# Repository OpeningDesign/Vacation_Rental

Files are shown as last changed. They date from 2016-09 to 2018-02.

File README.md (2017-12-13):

## The Downtowner - A Vacation Rental in Lake Geneva, WI

---

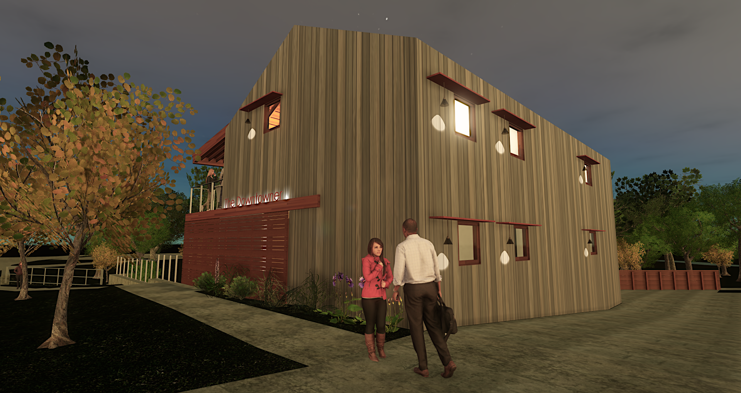
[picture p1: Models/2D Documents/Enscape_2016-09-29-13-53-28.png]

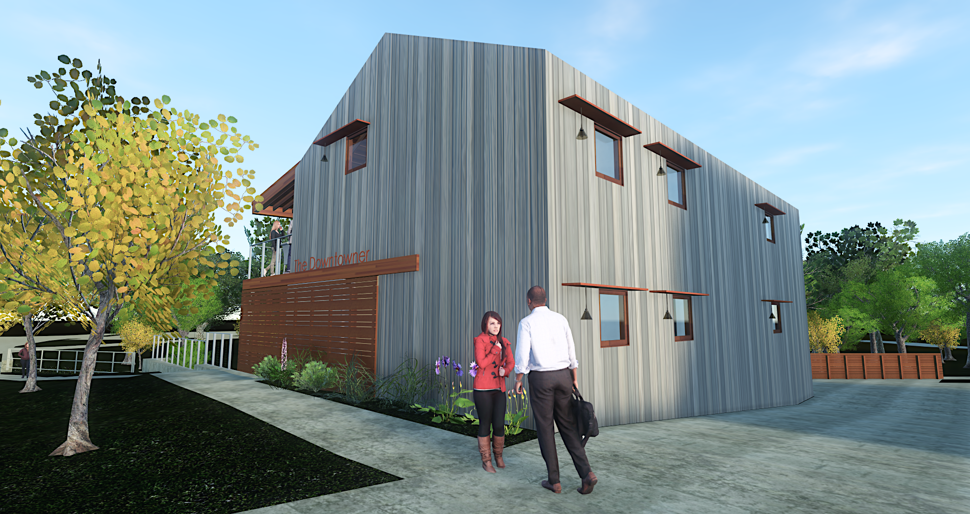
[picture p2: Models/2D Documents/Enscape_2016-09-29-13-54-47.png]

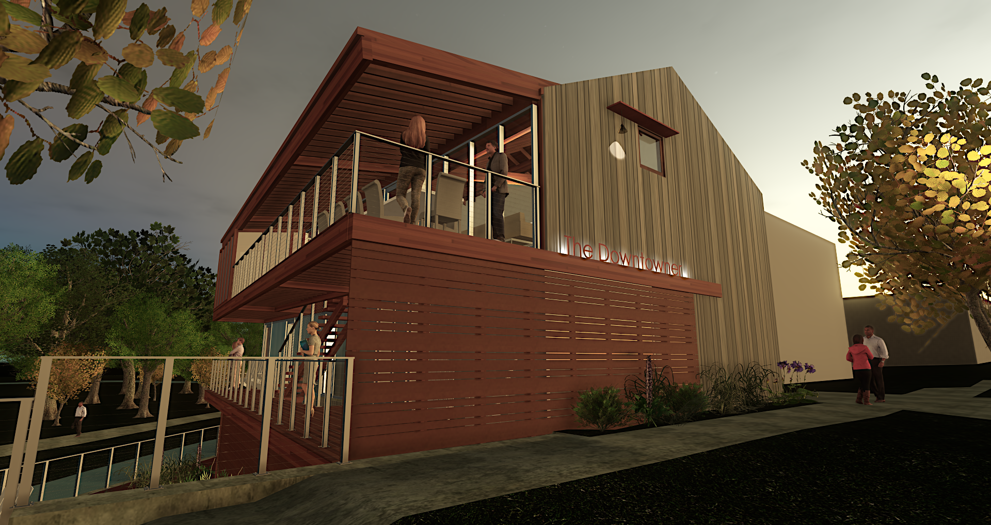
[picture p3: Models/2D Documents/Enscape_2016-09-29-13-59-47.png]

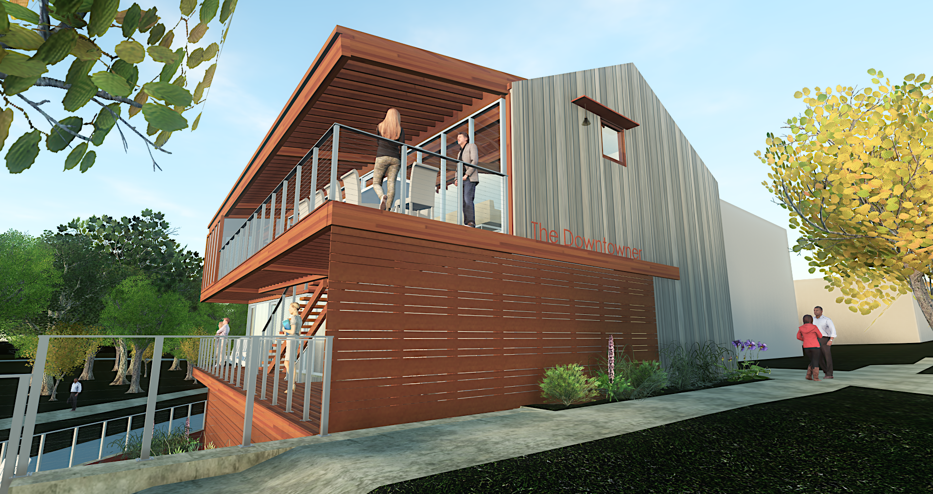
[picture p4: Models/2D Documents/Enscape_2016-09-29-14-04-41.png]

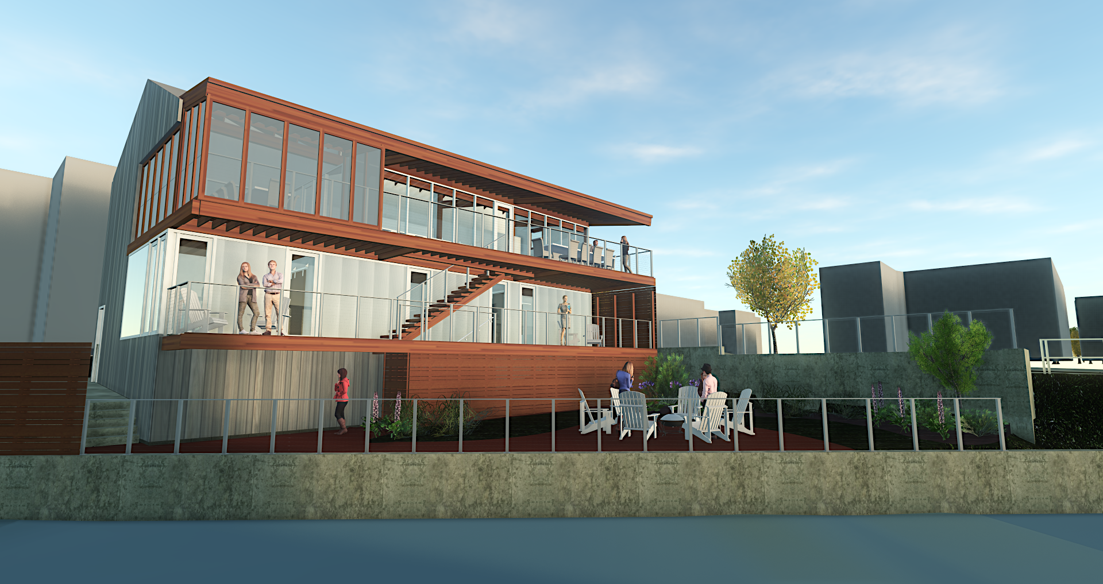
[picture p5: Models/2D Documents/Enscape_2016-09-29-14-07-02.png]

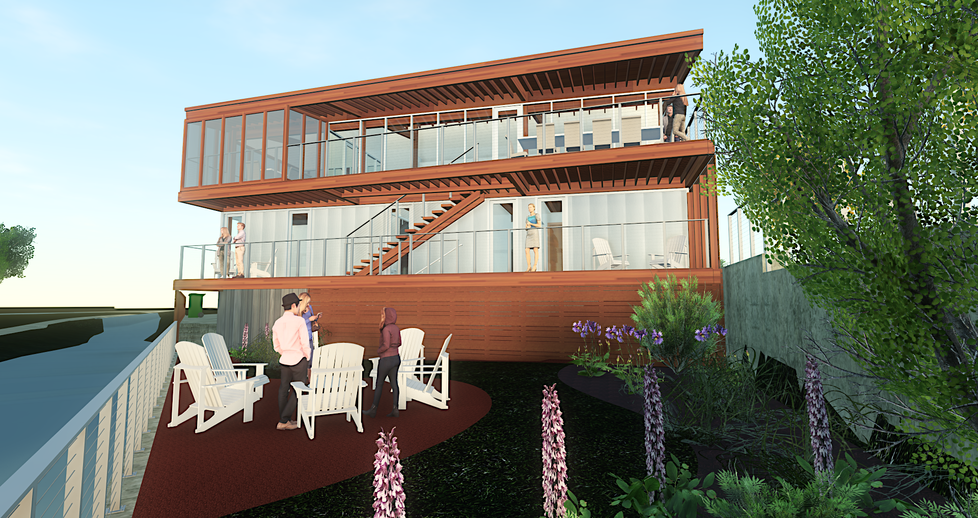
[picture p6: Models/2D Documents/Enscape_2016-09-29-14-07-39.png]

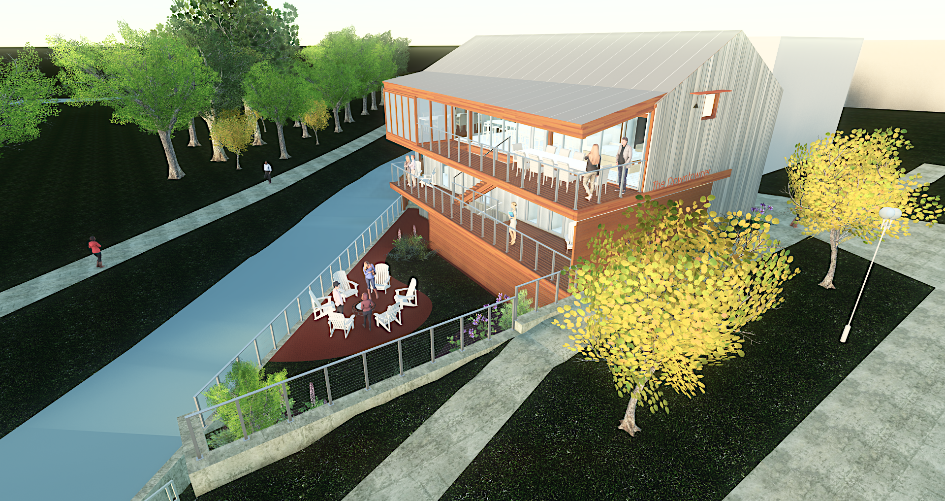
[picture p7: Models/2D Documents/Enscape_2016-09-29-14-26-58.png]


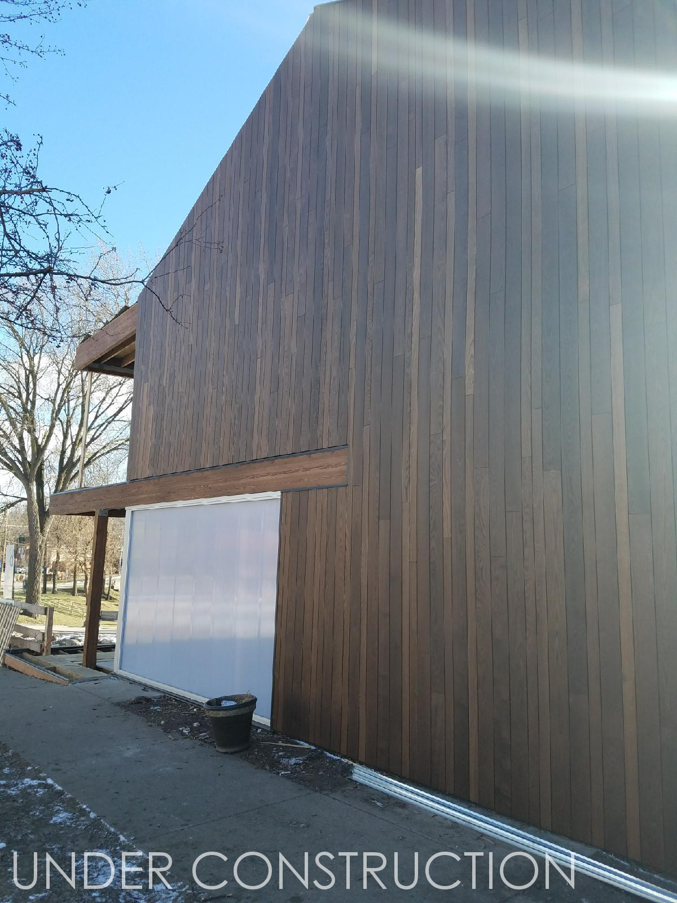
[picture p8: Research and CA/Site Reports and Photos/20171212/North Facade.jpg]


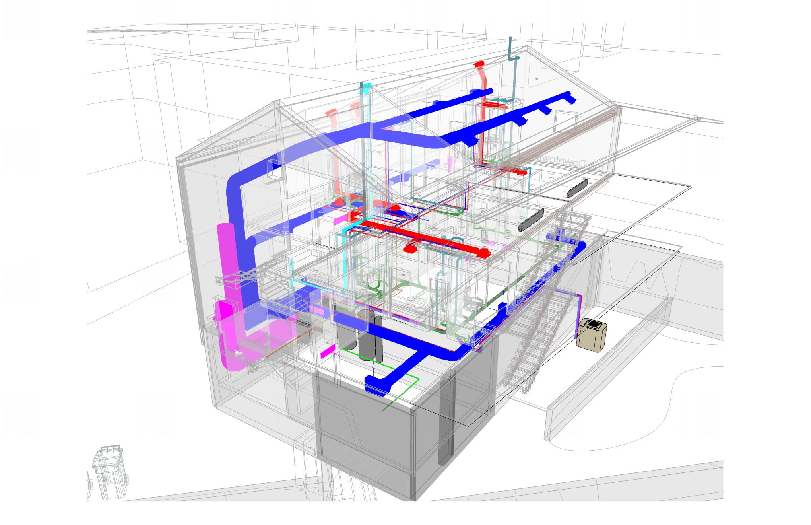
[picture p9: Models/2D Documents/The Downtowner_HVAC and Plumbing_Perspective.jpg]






---

#### In-the-Open

All of [OpeningDesign's](http://openingdesign.com/) projects are conducted out in the open.  That is, during the development of any one project, all team communication and content is hosted [publicly](https://github.com/OpeningDesign) (here on GitHub) and is <a href="#license">open source</a>.

Our [about page](http://openingdesign.com/about/) provides a more nuanced description of this open approach.

---

#### License
Per usual, unless otherwise noted, all content associated with [OpeningDesign](http://openingdesign.com) projects is licensed under an open source, 'copyleft' license: 
[Attribution-ShareAlike 4.0 International (CC BY-SA 4.0)](https://creativecommons.org/licenses/by-sa/4.0/).  Attribution to be given to the entire team associated with the project.


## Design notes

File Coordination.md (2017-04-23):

 - Screen Patio is not conditioned.
 - Eliminate the return ducts?  Can we just use the rooms/corridors to return air to main trunks?
 - Route bathroom exhausts up to roof
	 - combine exhaust stacks as much as possible. Desapex: Okay this can be done
		 - 3 exhaust penetrations on roof?
 - Okay to narrow plenum duct out of furnace to make room for stair? Desapex :Will reduce as much as possible
 - Move supply duct closer to east facing storefront to counteract cold drafts. Desapex:All floors ???
	 - Also Include radiant heat along east facing storefront on 2nd floor. Desapex : We shall discuss on this
		 - Might be valued engineered out, but include for permit set. Desapex : We shall discuss on this
 - Rerouted refrigerant lines to compressor . Desapex : This can be done the way required.
 - see ModelsARCHs HVAC Proposal.rvt file for other spatial/configuration proposals.Desapex : okay

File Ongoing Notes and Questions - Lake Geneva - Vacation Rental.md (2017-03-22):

 - Showers per room
 - 1/2 bath upstairs
 - 70" T.V.

- Outside basement entrance?

- submit HVAC?
- submit plumbing?

- Sliding door at unit entrance
- pocket door at restrooms
- stackable washer/dryer
- smaller closets
- ironing board

- screened in porch

- Fire Department
	- Lieutenant Dennis Detkowski 262-248-7228
	- Jim Bastic
- Zoning and Building Inspection
	- Ken Robers

Mike Kasseric
Dan Draper - City Attorney

- Balloon framed?
- foundation dimensions
	- floor dimensions
	-

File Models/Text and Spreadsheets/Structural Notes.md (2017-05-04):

### LAMINATED WOOD STRESS COMBINATIONS:
|SPECIES|DOUGLAS FIR UNLESS NOTED|
|-|-|
|LAMINATION THICKNESS|1 1/2" (2" NOM.) UNLESS NOTED|
|STRESS COMBINATION|SEE STRESS LISTING BELOW|
|TREATING|ALL MEMBERS EXPOSED TO THE EXTERIOR TO BE TREATED|
|ADHESIVE|RESORCINOL RESIN
|AITC APPEARANCE GRADE|ARCHITECTURAL SMOOTH TEXTURE |
|FINISH (EXPOSED SURFACES)|FACTORY STAIN - ONE COAT.<br>ARCHITECT TO SELECT COLOR|
|FINISH (UNEXPOSED SURFACES)|ONE COAT SEALER|
|PROTECTION (TRANSIT)|WRAP INDIVIDUAL MEMBERS w/WATER-RESISTANT PAPER OR OPAQUE POLYETHYLENE, TAPE SEAMS

- MATERIALS AND WORKMANSHIP SHALL BE IN CONFORMANCE WITH "AMERICAN NATIONAL STANDARD", ANSI/AITC A190.1-1992.
- MEMBERS SHALL BE MARKED WITH A QUALITY MARK INDICATING CONFORMANCE TO THE STANDARD LISTED IN NOTE 1.

### LAMINATED WOOD STRESS COMBINATIONS:
|-||
|-|-|
|BEAMS|24F-1.8E(SIMPLE SPAN, 3500' RADIUS)|
|COLUMNS|COMB 2|

### LAMINATED WOOD CONNECTION / HARDWARE NOTES:

 - ALL CONNECTIONS PLATES SHALL BE FABRICATED WITH ASTM A36 STEEL
 - WELDING SHALL BE PERFORMED IN ACCORDANCE WITH AWS STANDARDS 
 - ALL HOLES SHALL BE 13/16" - UNLESS NOTED OTHERWISE
 - ALL BOLTS SHALL BE 3/4" ASTM A307 UNLESS NOTED OTHERWISE 
 - ALL LAGS SHALL CONFORM TO ANSI/ASME STANDARDS 
 - ALL SHEAR PLATES SHALL CONFORM TO ANSI/AF&PA STANDARDS.
 - SHAPED STEEL CONNECTION PLATES MAY BE CUT FROM A SINGLE PLATE OR CONSTRUCTED OF MULTIPLE PLATES w/ BEVELED, FULL PENETRATION WELDS (GROUND SMOOTH) 
 - ALL FABRICATED STEEL, BOLTS, WASHERS, SHEAR PLATES, LAGS, AND NAILS SHALL BE HOT DIP GALVANIZED WHERE EXPOSED TO THE WEATHER OR EMBEDDED IN CONCRETE.

### LAMINATED WOOD STORAGE / ERECTION NOTES:
- JOB-SITE STORAGE SHALL BE PROVIDED IN A LEVEL AREA TO PREVENTWARPAGE.  MEMBERS SHALL BE SUPPORTED WITH BLOCKING SPACED TO PROVIDE UNIFORM AND ADEQUATE SUPPORT.
- MATERIAL SHALL BE BLOCKED WELL OFF THE GROUND AND SEPARATED WITH STRIPPING TO ALLOW AIR CIRCULATION AROUND ALL FOUR SIDES OF EACH MEMBER.
- INDIVIDUAL MEMBER WRAPPINGS SHALL BE SLIT OR PUNCTURED ON THE LOWER SIDE TO ALLOW DRAINAGE OF WATER.
- MATERIAL SHALL BE STORED BENEATH AN OPAQUE, MOISTURE-RESISTANT COVERING UNTIL ERECTED.
- PADDED OR NONMARRING SLINGS SHALL BE USED FOR ERECTION, AND CORNERS SHALL BE PROTECTED WITH WOOD BLOCKING.
- PROVIDE ADEQUATE TEMPORARY BRACING UNTIL THE ROOF STRUCTURE IS SHEATHED.
- MODERATE USE OF DRIFT PINS, MODERATE REAMING, AND SLIGHT CUTTING ARE ACCEPTABLE MEANS OF CORRECTION FOR PROPER ASSEMBLY AND FITTING.  CONTACT PIERCE ENGINEERS FOR METHOD OF CORRECTION IF ERROR OR MATERIAL DEFECTS DO NOT ALLOW PROPER ASSEMBLY.
- HEAT SHOULD NOT BE FULLY TURNED ON AS SOON AS THE STRUCTURE IS ENCLOSED.  EXCESSIVE CHECKING MAY OCCUR DUE TO RAPID LOWERING OF THE RELATIVE HUMIDITY IN THE BUILDING.  A GRADUAL SEASONING PERIOD AT MODERATE TEMPERATURE SHOULD BE PROVIDED.

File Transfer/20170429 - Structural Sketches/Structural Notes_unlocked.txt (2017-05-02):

PE
PE
AS NOTED
WIND RIVER FINANCIAL
65 BUTTONWOOD CT.
MADISON, WISCONSIN
BID PACKAGE #1
03/02/2015
1
1. DESIGN UPLIFT ON ROOF TRUSSES AS INDICATED IN THE DESIGN DATA.  PROVIDE A TIE DOWN CLIP
AT EACH TRUSS, AT EVERY POINT OF BEARING.
2. ROOF TRUSS TOP CHORDS SHALL BE PITCHED TO MATCH ROOF DRAINAGE PROFILE ON ARCH.
DWGS.
DEFLECTION LIMITS:
ROOF
LIVE LOAD                                  L/360
TOTAL LOAD                                L/240
1. ALL BRACING SHOWN OR DESCRIBED SHALL BE MINIMUM 2x4 WITH 2- 16d IN EVERY TRUSS IT
CROSSES.
2. ALL TRUSS TOP CHORDS SHALL BE CONTINUOUSLY BRACED BY THE ROOF OR FLOOR DECKING.
3. ALL TRUSS WEB MEMBERS SHALL BE BRACED @ 4'-0" O.C. UNLESS CALCULATIONS SHOW
OTHERWISE.  COORDINATE BRACING w/MECHANICAL DRAWINGS.
4. ALL ROOF TRUSS HORIZONTAL BRACING SHALL BE STIFFENED @ 20'-0" O.C. WITH EITHER:
a. DIAGONAL BRACING EXTENDED TO A SHEAR WALL PARALLEL TO THE ORIGINAL BRACING.
SEE BRACING DETAILS 5/S4.00 FIG. 1(a)-1(d).
b. 1
2" APA RATED SHEATHING EXTENDED TO ROOF DECK OR SHEAR WALL.
5. ALL TRUSS BOTTOM CHORDS SHALL BE BRACED @ 6'-0" O.C. UNLESS CALCULATIONS SHOW
OTHERWISE.
ROOF TRUSS BRACING NOTES
ROOF TRUSS DESIGN NOTES
NOTE: TRUSS MANUFACTURER MAY NOT DEVIATE FROM THE FRAMING PLANS UNLESS PRIOR
APPROVAL FROM THE STRUCTURAL ENGINEER HAS BEEN GIVEN.  IT IS THE TRUSS MANUFACTURER'S
RESPONSIBILITY TO SEEK SUCH APPROVAL PRIOR TO MANUFACTURE AND INSTALLATION OF FRAMING
MEMBERS.
WOOD TRUSS SHOP DRAWINGS SHALL SHOW THE FOLLOWING INFO:
1. INFORMATION WHICH THE RESPONSIBLE BUILDING DESIGN PROFESSIONAL WILL CHECK FOR
COMPLIANCE WITH CONTRACT DOCUMENTS.
a. ERECTION PLAN: SHOWING DIMENSIONED LOCATIONS AND TRUSS IDENTIFICATION.
b. BEARING DETAILS: SHOWING BEARING LENGTH, WIDTH, AND DEPTH INDICATING
CONFORMANCE TO DESIGN CALCULATIONS.
c. DESIGN LOADS: ALL DEAD AND LIVE LOADS SHALL BE SHOWN ON THE FRAMING PLAN OR
TRUSS ELEVATION INDICATING CONFORMANCE TO TRUSS CALCULATIONS.
d. ALL PERMANENT BRACING: SHOW TOP CHORD, BOTTOM CHORD, & WEB MEMBER BRACING
ON FRAMING PLAN AND TRUSS ELEVATION. SUPPLIER AND INSTALLER OF THIS BRACING
SHALL ALSO BE INDICATED.
e. TRUSS DIMENSIONS: SHOW DEPTH, SPAN BEARING, HEIGHT, AND SLOPES AT ALL CRITICAL
POINTS.
f. TRUSS DEFLECTIONS:  SHOW LIVE LOAD AND TOTAL LOAD DEFLECTION BASED UPON
DESIGN LOADS
2. INFORMATION THAT SHALL BE THE RESPONSIBILITY OF THE FABRICATOR AND TRUSS DESIGNER
AND SHALL BE PROVIDED WITH THE SHOP DRAWING SUBMITTAL.
a. MEMBER DESIGN: INCLUDING WEB CONFIGURATION, MEMBER SIZE, GRADE OF LUMBER,
FABRICATED SPLICES, AND MEMBER BRACING REQUIRED BY TRUSS DESIGN.
b. MEMBER CONNECTIONS: DESIGN AND INDICATE ALL NECESSARY HARDWARE FOR
PROPER INSTALLATION OF TRUSSES INCLUDING, BUT NOT LIMITED TO, GIRDER PLY
CONNECTIONS, TRUSS-TO-GIRDER CONNECTIONS, TIE-DOWNS, AND FIELD SPLICES.
c. INTERIOR CONNECTIONS: DESIGN AND SHOW DETAIL OF WEB AND CHORD CONNECTIONS,
INCLUDING CONNECTOR PLATE SIZES, CAPACITIES, AND BOLT SIZES.
d. ERECTION PLAN: SHOW SPACING AND LAYOUT OF ANY TEMPORARY BRACING REQUIRED
FOR ERECTION.
e. STRUCTURAL DESIGN OF TRUSSES: SUBMIT COMPLETE TRUSS CALCULATIONS STAMPED
AND SIGNED BY A PROFESSIONAL ENGINEER IN THE STATE OF WISCONSIN AND OBTAIN
ALL APPROVALS NECESSARY FOR CONFORMANCE TO BUILDING CODE. VERIFY SUBMITTAL
AND APPROVAL BY SENDING A COPY TO THE BUILDING DESIGN PROFESSIONAL.
f. PROVIDE CONTRACTOR/INSTALLER WITH ALL DATA NECESSARY FOR PROPER
INSTALLATION.
ROOF TRUSS SUBMITTAL NOTES
1. FABRICATION AND ERECTION OF STRUCTURAL STEEL SHALL CONFORM WITH THE AISC  (AMERICAN
INSTITUTE OF STEEL CONSTRUCTION), "MANUAL OF STEEL CONSTRUCTION",  LATEST EDITION.
2. ALL STEEL DETAILS AND CONNECTIONS SHALL BE IN ACCORDANCE WITH THE  REQUIREMENTS OF
THE AISC "SPECIFICATIONS FOR STRUCTURAL STEEL BUILDINGS,  ALLOWABLE STRESS DESIGN AND
PLASTIC DESIGN", LATEST EDITION.
3. FABRICATORS SHALL DESIGN CONNECTIONS NOT SPECIFICALLY DETAILED ON PLANS AS FOLLOWS:
A. GENERAL: MEMBERS REQUIRING END MOMENT CONNECTIONS SHALL MEET THE 
REQUIREMENTS OF TYPE 1 "RIGID FRAME" CONSTRUCTION INCLUDING FRICTION 
BOLTS IF UTILIZED. ALL OTHER MEMBERS SHALL FOLLOW THE REQUIREMENTS OF 
TYPE 2 "SIMPLE" CONSTRUCTION.
B. MEMBER SHEAR CONNECTIONS: UNLESS A LARGER END VERTICAL REACTION IS SHOWN 
OTHERWISE ON THE DRAWINGS (IE R = 85k), MINIMUM DESIGN SHEAR FORCES SHALL BE 
AS FOLLOWS:
I. NON-COMPOSITE BEAMS: SUPPORT A REACTION "R" EQUAL TO ONE HALF THE TOTAL 
UNIFORM LOAD CAPACITY FROM THE TABLE OF UNIFORM LOAD CONSTANTS IN THE 
AISC MANUAL PART 2 FOR GIVEN SHAPE, SPAN, AND GRADE OF STEEL.
4. USE A325N BOLTS UNLESS NOTED OTHERWISE.
5. SPLICES SHALL BE ALLOWED ONLY AT LOCATIONS SPECIFICALLY INDICATED ON THE  STRUCTURAL
DRAWINGS UNLESS APPROVED OTHERWISE BY THE ENGINEER.
6. OVERSIZED OR SLOTTED HOLES SHALL NOT BE USED FOR ANY CONNECTIONS UNLESS
SPECIFICALLY INDICATED ON THE DRAWINGS OR APPROVED BY THE ENGINEER.
7. BEAM AND GIRDER CONNECTIONS SHALL BE AS NOTED ON PLANS AND IN DETAILS.
8. PROVIDE HOLES IN ALL STEEL AS REQUIRED TO PREVENT ANY ACCUMULATION OF WATER DURING
ERECTION.  ALL PENETRATIONS THROUGH MAIN MEMBERS SHALL NOT EXCEED 11
2" IN DIAMETER AND
SHALL BE GROUND SMOOTH.
9. CUTS, HOLES, COPING, ETC. REQUIRED FOR WORK OF OTHER TRADES SHALL BE SHOWN ON THE
SHOP DRAWINGS AND MADE IN THE SHOP.  CUTS OR BURNING OF HOLES IN STRUCTURAL STEEL
MEMBERS IN THE FIELD WILL NOT BE PERMITTED.
10. PROVIDE ANY NECESSARY TEMPORARY BRACING OR GUYS TO PROVIDE LATERAL SUPPORT OF THE
BUILDING UNTIL PERMANENT FRAME IS COMPLETELY INSTALLED.
11. STRUCTURAL STEEL FRAMING SHALL BE TRUE AND PLUMB BEFORE CONNECTIONS ARE FINALLY
BOLTED OR WELDED.
12. THE DETAILS OF DESIGN, WORKMANSHIP, AND TECHNIQUE FOR WELDING, INSPECTION OF WELDING,
AND QUALIFICATIONS OF WELDING OPERATORS SHALL CONFORM TO THE REQUIREMENTS OF THE
SPECIFICATIONS LISTED IN IBC SECTIONS 2205, 2206, 2207, 2209, AND 2210.
STRUCTURAL STEEL NOTES
FOOTINGS - BOTTOM & SIDES 3"
FOOTING - TOP 2"
PERIMETER WALLS - #5 & SMALLER 11
2"
PERIMETER WALLS - #6 & LARGER 2"
INTERIOR WALLS 3
4"
BEAMS, PIERS, & COLUMNS 11
2"
SLABS - BOTTOM & SIDES 1"
SLABS - TOP 3
4"
MILD STEEL PROTECTION
1. DESIGN AND CONSTRUCTION SHALL BE IN ACCORDANCE WITH THE LATEST PROVISIONS OF ACI
318/318R.
2. CONTRACTOR SHALL NOTIFY THE ARCHITECT/ENGINEER AT LEAST 48 HOURS PRIOR  TO PLACING
CONCRETE TO FACILITATE ON SITE OBSERVATION OF REBAR.
3. ARRANGEMENT AND BENDING OF REINFORCING STEEL SHALL BE IN ACCORDANCE WITH ACI
DETAILING MANUAL (ACI SP-66), LATEST EDITION.
4. WHEN THE AVERAGE TEMPERATURE FROM MIDNIGHT TO MIDNIGHT IS EXPECTED TO DROP BELOW
40 DEGREES FAHRENHEIT FOR THREE SUCCESSIVE DAYS, COLD WEATHER CONCRETING
REQUIREMENTS MUST BE FOLLOWED.
5. WHEN AMBIENT AIR OR CONCRETE TEMPERATURES EXCEED 90 DEGREES FAHRENHEIT, STEEL
REINFORCING AND/OR FORMING SURFACES ARE ABOVE 120 DEGREES, OR WHEN WIND VELOCITY,
HUMIDITY, OR SOLAR RADIATION CREATE CONDITIONS OF ACCELERATED MOISTURE LOSS AND
INCREASED RATE OF HYDRATION, HOT WEATHER CONCRETING REQUIREMENTS SHALL BE
FOLLOWED.
6. ALL HOOKS IN STEEL REINFORCING SHALL BE ACI STANDARD HOOKS, UNLESS NOTED OTHERWISE
IN CONSTRUCTION DOCUMENTS.
7. ALL CONCRETE SURFACES SHALL BE FORMED, UNLESS OTHERWISE NOTED.
8. CONTROL JOINTS SHALL BE PLACED IN SLAB ON GRADE AND SLAB ON METAL DECK CONSTRUCTION
WITHIN 24 HOURS OF INITIAL POUR.
9. WIRE SPACERS, CHAIRS, TIES, ETC., FOR SUPPORT OF STEEL REINFORCING SHALL BE PROVIDED
BY THE CONTRACTOR TO ENSURE REINFORCING IS PLACED IN THE PROPER POSITION DURING
CONCRETE PLACEMENT.
10. STEEL REINFORCING SPLICES OF ADJACENT BARS SHALL BE STAGGERED SUCH THAT SPLICES ARE
4 FEET APART, MINIMUM.
11. PROVIDE (2) #5 BARS AROUND ALL OPENINGS AND (2) #5 DIAGONALLY AT ALL OPENING CORNERS
UNLESS OTHERWISE SPECIFIED.  EXTEND 2'-6" PAST OPENING TYPICALLY.
12. WELDED WIRE REINFORCING SHALL BE IN FLAT SHEETS ONLY, AND LAPPED A MINIMUM OF 6
INCHES.
13. WELDING OF STEEL REINFORCING IS NOT PERMITTED.
14. SLEEVES, CONDUITS, OR PIPES THROUGH SLABS AND WALLS SHALL BE PLACED AT THREE
DIAMETERS ON CENTER, OR 4 INCHES MINIMUM.
15. ALUMINUM CONDUIT OR PIPING SHALL NOT BE CAST IN CONCRETE.
16. PROVIDE A 3
4" CHAMFER ON EXPOSED CORNERS OF CONCRETE UNO. TOP EDGES OF WALLS SHALL
BE TOOLED UNO.
17. FINISH & COVER CONCRETE SLABS w/ FILM FORMING CURING COMPOUND OR VAPOR RETARDER
UNO OR SPECIFIED OTHERWISE.
CAST-IN-PLACE CONCRETE NOTES
1. CONCRETE COVER MEASURED PERPENDICULAR FROM THE SURFACE IN DIRECTION OF TOLERANCES:
MEMBERS 12" OR LESS ±3
8"
MEMBERS OVER 12" ±1
2"
2. STEEL REINFORCEMENT SPACING SHALL BE WITHIN THE FOLLOWING TOLERANCES:
1
4" SPACING DISTANCE, NOT TO EXCEED 1"
3. PLACEMENT OF EMBEDDED ITEMS SHALL BE WITHIN THE FOLLOWING TOLERANCES:
VERTICAL ALIGNMENT ±1"
LATERAL ALIGNMENT ±1"
LEVEL ALIGNMENT ±1"
4. PLACEMENT OF FOOTINGS SHALL BE WITHIN THE FOLLOWING TOLERANCES:
LATERAL ALIGNMENT ±2"
LEVEL ALIGNMENT +1
2" TO -2"
(LEVEL ALIGNMENT SUPPORTING MASONRY) ±1
2"
5. CROSS-SECTIONAL DIMENSION OF FOOTINGS SHALL BE WITHIN THE FOLLOWING TOLERANCES:
FORMED FOOTINGS +2" TO -1
2"
EARTHCAST FOOTINGS:
2' OR LESS +3" TO -1
2"
GREATER THAN 2' BUT LESS THAN 6' +6" TO -1
2"
GREATER THAN 6' +12" TO -1
2"
FOOTING THICKNESS ±5%
6. TOP OF FOOTING SLOPE 1" IN 10'
7. SEE DRILLED PIER NOTES FOR ADDITIONAL INFORMATION AT DRILLED PIER FOUNDATIONS.
CAST-IN-PLACE CONCRETE TOLERANCES
1. CONCRETE MIXES TO BE PLACED DURING DRY AND WINDY CONDITIONS SHALL BE MODIFIED BY
THE ADDITION OF RETARDING ADMIXTURES OR SLOWER CURING CEMENT SUBSTITUTES TO
MINIMIZE THE EFFECTS OF ACCELERATED CURING.
2. WATER SHALL NOT BE ADDED TO CONCRETE MIXES ON SITE FOR WORKABILITY. MID OR HIGH
RANGE WATER REDUCERS SHALL BE APPROVED BY ENGINEER BEFORE ADDING TO CONCRETE
MIX FOR INCREASED WORKABILITY.
3. INGREDIENTS USED IN CONCRETE MIXES SHALL BE COOLED TO MAINTAIN A CONCRETE
TEMPERATURE BELOW 90 DEGREES FAHRENHEIT AT TIME OF PLACEMENT.
4. CHILLED WATER AND CHOPPED ICE MAY BE USED IN CONCRETE MIXTURES TO CONTROL
CONCRETE TEMPERATURES. AMOUNT OF CHOPPED ICE SHALL NOT EXCEED THE EQUIVALENT
AMOUNT OF MIXING WATER REQUIRED FOR THE DESIGN MIX.
5. RETARDING ADMIXTURES SHALL NOT BE USED IN CONCRETE MIXES WITHOUT THE APPROVAL OF
THE ENGINEER.
HOT WEATHER CONCRETING NOTES
1. SNOW, FROST, AND ICE SHALL BE REMOVED FROM ALL SURFACES, INCLUDING REINFORCING,
AGAINST WHICH THE CONCRETE IS TO BE PLACED
2. DO NOT PLACE CONCRETE ON FROZEN SUBGRADE.
3. THE MINIMUM PLACEMENT AND PROTECTION TEMPERATURE OF CONCRETE SHALL BE AS
FOLLOWS: MINIMUM TEMP OF CONCRETE 
AS PLACED AND MAINTAINED
DURING PROTECTION PERIOD
LEAST DIMENSION OF SECTION (DEGREES FAHRENHEIT)
LESS THAN 12" 55
12" TO LESS THAN 36 50
36" TO 72" 45
GREATER THAN 72" 40
4. TEMPERATURES OF CONCRETE SHALL BE MEASURED AT THE CONCRETE SURFACE.
5. CONCRETE TEMPERATURES SHALL BE MEASURED AND RECORDED FOR THE FIRST 3 DAYS UPON
PLACEMENT OF CONCRETE, AT THE BEGINNING, MIDDLE, AND END OF EACH WORK DAY AT 4 HOUR
INTERVALS. OVERNIGHT TEMPERATURE MEASUREMENTS ARE NOT REQUIRED.
6. HEATED AIR TEMPERATURES SHALL NOT EXCEED THE REQUIRED CONCRETE TEMPERATURES
LISTED IN TABLE ABOVE BY MORE THAN 20 DEGREES.
7. CONCRETE SHALL BE CURED AND PROTECTED AGAINST DAMAGE FROM FREEZING FOR A MINIMUM
PERIOD OF 3 DAYS.
8. DURING PERIODS NOT DEFINED AS COLD WEATHER, BUT WHEN FREEZING TEMPERATURES MAY
OCCUR, PROTECT CONCRETE SURFACES FROM FREEZING FOR THE FIRST 24 HOURS AFTER
PLACEMENT.
9. IF TEMPERATURE REQUIREMENTS DURING PROTECTION PERIOD ARE NOT MET, BUT CONCRETE
WAS PREVENTED FROM FREEZING, CONTACT ARCHITECT/ENGINEER FOR EXTENT OF ADDITIONAL
PROTECTION TIME REQUIRED.
COLD WEATHER CONCRETING NOTES
22
f'c = 4000
BAR
SIZE f'c = 3000
#3
CLASS 'B' TENSION LAP SPLICE LENGTHS (INCHES)
BOT
CLASS BOT TOP TOP
29
#4
#5
#6
#7
#8
#9
#10
#11
28 19 24
33
25
37
36
43
63
72
81
91
101
47
56
81
93
105
118
131
31
37
54
62
70
79
87
41
49
71
81
91
102
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
NOTES (db = BAR DIAMETER, C-C = CENTER TO CENTER):
1. SCHEDULE BASED ON CLEAR COVER >1 db AND C-C > 2db
2. TOP BARS OF BEAMS AND JOIST AND HORIZONTAL WALL REINFORCING
THIS SCHEDULE IS PROVIDED FOR THE CONVENIENCE OF THE CONTRACTOR AND IS NOT
INTENDED TO COVER ALL SITUATIONS. SHOP DRAWINGS SHALL CLEARLY INDICATE ALL REQUIRED
LAP LENGTHS
1. ANCHOR BOLTS SHALL BE SET TO THE FOLLOWING TOLERANCES:
ELEVATION OF TOP OF BOLTS +1" TO -3
8"
OUT OF POSITION OF ANCHOR BOLTS ± 1
8"
2. PROTECT IN-PLACE FOUNDATIONS AND SLABS ON GRADE FROM FROST PENETRATION UNTIL
PROJECT COMPLETION
3. WHERE FILL MATERIAL IS REQUIRED ON BOTH SIDES OF GRADE BEAMS OR WALLS, IT SHALL BE
PLACED SIMULTANEOUSLY. REFER TO PLANS AND SPECIFICATIONS FOR TYPE AND PLACING OF
BACKFILL.
4. WHERE FILL MATERIAL IS PLACED ON ONE SIDE OF A WALL (OR GRADE BEAM), THE WALL (OR
BEAM) SHALL BE ADEQUATELY SHORED AND BRACED OR THE MATERIAL SHALL NOT BE PLACED
UNTIL SUPPORTING FLOOR SLABS HAVE BEEN POURED AND SET.
5. REFER TO ARCHITECTURAL DRAWINGS OR PLUMBING DRAWINGS FOR SPECIFIC FLOOR DRAIN
LOCATIONS & ELEVATIONS.
6. NO PROVISION HAS BEEN MADE FOR FUTURE EXPANSION.
7. VERIFY SIZES OF ALL STOOPS WITH ARCHITECT PRIOR TO CONSTRUCTION.
GENERAL FOUNDATION NOTES
1. FRAMING MEMBERS:
VERTICAL MEMBERS: SEE PLANS FOR SIZE, SPACING AND
GRADE.   KILN DRIED, MOISTURE 
CONTENT SHALL BE BETWEEN 15%
AND 19%
2. TOP & BOTTOM PLATES OF STUD WALLS SHALL BE THE SAME AS THE WALL STUDS.  (BOTTOM
PLATE TO BE TREATED).
3. ROOF SHEATHING SHALL BE 3
4" AT FLAT ROOFS ATTACHED TO THE ROOF FRAMING MEMBERS w/
8d COMMON OR BOX NAILS @ 6" O.C. ALONG EDGES AND 12" O.C. ALONG INTERMEDIATE
MEMBERS. STAGGER PANEL EDGES.  (1" MIN. EMBED. INTO FRAMING MEMBER).  INSTALL EDGE
CLIPS ON PANEL EDGES BETWEEN FRAMING MEMBERS.
4. EXTERIOR WALLS TO BE SHEATHED w/APA RATED SHEATHING, SEE ARCH DRAWINGS FOR
THICKNESS.   ATTACH DIRECTLY TO THE OUTSIDE FACE OF EXTERIOR STUD WALLS WITH 8d
COMMON OR BOX NAILS @ 6"O.C. ALONG EDGES AND 12" O.C. ALONG INTERMEDIATE MEMBERS.
U.N.O.
5. AS A MINIMUM, ALL CONNECTIONS SHALL CONFORM TO IBC 2006 TABLE 2304.9.1 FASTENING
SCHEDULE. DRAWING DETAILS SHALL GOVERN IF THEIR CONNECTION CAPACITY IS GREATER
THAN THOSE SPECIFIED IN TABLE 2304.9.1.
6. WHERE BUILT-UP/MULTI-PLY BEAMS AND HEADERS OF DIMENSIONAL LUMBER OR LVL MATERIAL
ARE INDICATED, SEE DETAIL 1/S4.00 FOR TOP LOADED MEMBERS FOR MINIMUM FASTENING
REQUIREMENTS.  ALSO SEE MANUFACTURER'S MINIMUM FASTENING REQUIREMENTS.
7. WHERE BUILT-UP/MULTI-PLY POSTS AND JAMBS ARE INDICATED, FASTENING SHALL BE IN
ACCORDANCE WITH NATIONAL DESIGN SPECIFICATION SECTION 15.3.3.
8. USE JOIST HANGERS DESIGNED FOR GIVEN MEMBER SIZE TO SUPPORT ALL JOISTS/HEADERS
FRAMING INTO SIDES OF OTHER MEMBERS.
9. COORDINATE WALL & FACE BRICK DIMENSIONS W/ ARCHITECTURAL DRAWINGS.
WOOD FRAMING NOTES
(APPLY TO ALL FRAMING DRAWINGS)
DESIGN CODE:
2011 WISCONSIN COMMERCIAL BUILDING CODE
WIND LOAD INFORMATION:
BASIC WIND SPEED 90 MPH
 BUILDING OCCUPANCY CATEGORY II
WIND LOAD IMPORTANCE FACTOR (Iw) 1.00
WIND EXPOSURE B
INTERNAL PRESSURE COEFFICIENTS ± .18
COMPONENTS AND CLADDING (GROSS WIND PRESSURES):
(FOR ZONE DEFINITIONS & DIAGRAMS SEE DESIGN GUIDE ASCE/SEI 7 SECTION 6)
WIDTH OF PRESSURE COEFFICIENT ZONE (a) 6 ft
TRIBUTARY WIND LOAD AREAS: 10 ftà 50 ftà 100 ftà
ROOF (GABLE/HIP/MONOSLOPE):
NEGATIVE ZONE 1 -14.6 psf -13.7 psf -13.3 psf
NEGATIVE ZONE 2 -24.4 psf -18.4 psf -15.8 psf
NEGATIVE ZONE 3 -24.4 psf -18.4 psf -15.8 psf
POSITIVE PRESSURE ALL ZONES 10.0 psf 10.0 psf 10.0 psf
WALLS:
ZONE 4 -14.4 psf -13.1 psf -12.5 psf
ZONE 5 -17.8 psf -15.0 psf -13.9 psf
OVERHANGS/CANOPIES:
ZONE 1,2 -21.0 psf -20.1 psf -19.8 psf
ZONE 3 -21.0 psf -20.1 psf -19.8 psf
SEISMIC LOAD INFORMATION:
SEISMIC USE GROUP / OCCUPANCY CATEGORY II
SEISMIC LOAD IMPORTANCE FACTOR (Ie) 1.00
SEISMIC SITE CLASS D
MAPPED SPECTRAL RESPONSE ACCELERATION (Ss) 10.40                                   
MAPPED SPECTRAL RESPONSE ACCELERATION (S1) 4.40
SPECTRAL RESPONSE COEFFICIENT (Sds) 0.111
SPECTRAL RESPONSE COEFFICIENT (Sd1) 0.070
SEISMIC DESIGN CATEGORY A
BASIC SEISMIC FORCE RESISTING SYSTEM LIGHT FRAME SHEAR WALLS
RESPONSE MODIFICATION FACTOR 2.5
SEISMIC RESPONSE COEFFICIENT (Cs) 0.044
ANALYSIS PROCEDURE EQUIVALENT LATERAL FORCE
SNOW LOAD INFORMATION:
GROUND SNOW LOAD (Pg) 30 psf 
SNOW EXPOSURE FACTOR (Ce) 1.00
SNOW LOAD IMPORTANCE FACTOR (Is) 1.00
THERMAL FACTOR (Ct) 1.10
1.20 AT OVERHANGS
DESIGN/BALANCED SNOW LOAD (Ps) 30 psf
SOIL LOAD INFORMATION:
COEFFICIENT OF SLIDING FRICTION (μ) 0.40
LATERAL EARTH PRESSURE:
ACTIVE 35 pcf
AT-REST 55 pcf
PASSIVE 200 pcf
ALLOWABLE NET SOIL BEARING PRESSURE Qa = 2500psf
MODULUS OF SUB-GRADE REACTION k = 125 pci
FROST DEPTH 42"
LIVE LOADS:
FLOOR UNLESS NOTED 100 psf
ROOF SEE SNOW LOAD INFO
CIP CONCRETE STRENGTHS:
FOOTINGS f'c = 3000 psi
CONCRETE WALLS / PIERS / COLUMNS f'c = 4000 psi
SLAB ON GRADE f'c = 4000 psi
EXTERIOR SLAB ON GRADE f'c = 4500 psi
REINFORCING STEEL STRENGTHS:
BARS (ASTM A 615, grade 60) Fy = 60,000 psi
WWF (ASTM A 185) Fy = 65,000 psi
STRUCTURAL STEEL STRENGTHS:
WF SHAPES (ASTM A992) Fy = 50,000 psi
ANGLES, CHANNELS, PLATES, & BARS (ASTM A36) Fy = 36,000 psi
SQUARE & RECTANGULAR TS OR HSS SECTIONS Fy = 46,000 psi
(ASTM A500, grade B)
ROUND HSS SECTIONS (ASTM A500, grade B) Fy = 42,000 psi
STEEL PIPE (ASTM A53, grade B) Fy = 35,000 psi
HIGH STRENGTH BOLTS (ASTM A325)
ANCHOR BOLTS (ASTM F1554) Fy = 36,000 psi
WELD ELECTRODES E70 XX
HEADED WELDED STUDS (ASTM A108) Fu = 55,000 psi
WOOD STRENGTHS:
DIMENSIONAL LUMBER (SEE PLANS & WOOD FRAMING NOTES)
LAMINATED VENEER LUMBER: E  = 1,900 ksi
Fb = 2,600 psi
Fv = 285 psi
Fc(perp) = 750 psi
Fc(para) = 2,510 psi
PARALLEL STRAND LUMBER: E  = 2,000 ksi
Fb = 2,900 psi
Fv = 290 psi
Fc(perp) = 750 psi
Fc(para) = 2,900 psi
LAMINATED STRAND LUMBER: E  = 1,500 ksi
Fb = 2,250 psi
Fv = 400 psi
Fc(perp) = 750 psi
Fc(para) = 1,950 psi
MATERIAL DESIGN PROPERTIES
DESIGN DATA
1. PREPARE SITE IN ACCORDANCE w/GEOTECHNICAL REPORT.  ALLOWABLE SOIL PRESSURE BASE ON
GEOTECHNICAL INVESTIGATION REPORT PREPARED BY CGC, INC. (PROJECT #C15019) DATED
FEBRUARY 13, 2015.  FOR A DETAILED DESCRIPTION OF THE SOILS AND BORING LOGS, REFER TO
GEOTECHNICAL EXPLORATION REPORT DATED FEBRUARY 14, 2003 FROM CGC, INC (NO. C03027).
2. ALL TOPSOIL, DEBRIS, SILTS, AND ORGANIC MATERIAL SHALL BE STRIPPED AND REMOVED FROM
LIMITS OF EXCAVATIONS AND EXISTING SUBGRADE SHALL BE COMPACTED TO 95% STANDARD
PROCTOR MAXIMUM DRY DENSITY PRIOR TO PLACEMENT OF FILL MATERIAL
3. FILL MATERIAL SHALL BE PLACED AND COMPACTED IN LIFTS NO THICKER THAN 8". EACH LIFT SHALL
MEET COMPACTION REQUIREMENTS PRIOR TO PLACEMENT AND COMPACTION OF ADDITIONAL
LIFTS.
4. FILL MATERIAL SHALL BE PLACED AND COMPACTED AT +1% TO -4% OPTIMUM MOISTURE CONTENT
TO 95% STANDARD PROCTOR MAXIMUM DRY DENSITY, UNLESS RECOMMENDED OTHERWISE BY A
QUALIFIED SOILS ENGINEER.
5. UNSATISFACTORY SOILS LOCATED BELOW FOUNDATIONS SHALL BE REMOVED AND REPLACED AS
DIRECTED BY THE SOILS ENGINEER.
EARTHWORK NOTES
@ AT
& AND
AB ANCHOR BOLT
ALT ALTERNATE
APA AMERICAN PLYWOOD ASSOC.
ARCH ARCHITECT(URAL)
BC BOTTOM CHORD
BLDG BUILDING
BLKG BLOCKING
BM BEAM
BOT BOTTOM
BRG BEARING
ȭ CENTERLINE
CB COLUMN BASE
CJ CONTROL JOINT
CMU CONCRETE MASONRY UNIT
COL COLUMN
CONC CONCRETE
CONT CONTINUOUS
DEFL DEFLECTION
DFL DOUGLAS FIR LARCH
DIA (Ø) DIAMETER
DIM DIMENSION
DL DEAD LOAD
DTL DETAIL
DWG DRAWING
EA EACH
EF EACH FACE
EL ELEVATION
EMBED EMBEDMENT
EOS EDGE OF SLAB
EO STL EDGE OF STEEL
EW EACH WAY
EXIST EXISTING
EXP EXPANSION
EXT EXTERIOR
FND FOUNDATION
FF FINISH FLOOR
FIN FINISH
FLR FLOOR
FRMG FRAMING
FTG FOOTING
GA GAGE
GB GRADE BEAM
GC GENERAL CONTRACTOR
GT GIRDER TRUSS
GYP GYPSUM
HORIZ HORIZONTAL
HP TENDON HIGH POINT
HSS HOLLOW STRUCTURAL SECTION
HT HEIGHT
INFO INFORMATION
JST JOIST
KSI KIPS PER SQUARE INCH
LL LIVE LOAD
LLH LONG LEG HORIZONTAL
LLV LONG LEG VERTICAL
LP TENDON LOW POINT
LSL LAMINATED STRAND LUMBER
LVL LAMINATED VENEER LUMBER
LW LONG WAY
MANUF MANUFACTURER
MAX MAXIMUM
MECH MECHANICAL
MIN MINIMUM
MISC MISCELLANEOUS
NTS NOT TO SCALE
OC ON CENTER
OPP OPPOSITE
PARA PARALLEL
P/C PRECAST CONCRETE
PCF POUNDS PER CUBIC FOOT
PERP PERPENDICULAR
ɓ PLATE
PLY PLYWOOD
PSI POUNDS PER SQUARE INCH
PSF POUNDS PER SQUARE FOOT
PSL PARALLEL STRAND LUMBER
P/T POST TENSIONED CONCRETE
PT PRESSURE TREATED
REINF REINFORCEMENT
REQD REQUIRED
RTU ROOF TOP UNIT
SCHED SCHEDULE
SHT SHEET
SIM SIMILAR
SMS SHEET METAL SCREWS
SPEC SPECIFICATION
SPF SPRUCE-PINE-FIR
SQ SQUARE
STRUCT STRUCTURAL
SW SHORT WAY
SYM SYMMETRICAL
SYP SOUTHERN YELLOW PINE
T&B TOP AND BOTTOM
TC TOP CHORD
T&G TONGUE AND GROOVE
TF TOP OF FOOTING
TL TOP OF LEDGE
TOC TOP OF CONCRETE
TOS TOP OF SLAB
TO STL TOP OF STEEL
TP TOP OF PIER
TRANS TRANSVERSE
TS TUBE STEEL
TW TOP OF WALL
TYP TYPICAL
UNO UNLESS NOTED OTHERWISE
VERT VERTICAL
VIF VERIFY IN FIELD
w/ WITH
WF WIDE FLANGE
w/o WITHOUT
WT WEIGHT
WWF WELDED WIRE FABRIC
STANDARD ABBREVIATIONS
WORD OR PHRASE
ABBRV. ABBRV. WORD OR PHRASE
LAMINATED WOOD SPECIFICATIONS:
SPECIES
LAMINATION THICKNESS
STRESS COMBINATION
TREATING
ADHESIVE
AITC APPEARANCE GRADE
FINISH (EXPOSED SURFACES)
FINISH (UNEXPOSED SURFACES)
PROTECTION (TRANSIT)
DOUGLAS FIR UNLESS NOTED
1 1/2" (2" NOM.) UNLESS NOTED
SEE STRESS LISTING BELOW
NONE
RESORCINOL RESIN
ARCHITECTURAL
SMOOTH TEXTURE
FACTORY STAIN - ONE COAT.
ARCHITECT TO SELECT COLOR
ONE COAT SEALER
WRAP INDIVIDUAL MEMBERS w/
WATER-RESISTANT PAPER OR
OPAQUE POLYETHYLENE, TAPE SEAMS
1.
2.
MATERIALS AND WORKMANSHIP SHALL BE IN CONFORMANCE WITH
"AMERICAN NATIONAL STANDARD", ANSI/AITC A190.1-1992.
MEMBERS SHALL BE MARKED WITH A QUALITY MARK INDICATING
CONFORMANCE TO THE STANDARD LISTED IN NOTE 1.
LAMINATED WOOD STRESS COMBINATIONS:
BEAMS
COLUMNS
OTHER MEMBERS
24F-V4 (SIMPLE SPAN, 3500' RADIUS)
COMB 2
AS NOTED
ROOF DECKING NOTES:
1.
2.
3.
4.
5.
6.
ROOF DECKING SHALL BE 2x6 NOMINAL SOUTHERN PINE OR DOUGLAS FIR,
SELECT GRADE, KILN DRIED, TONGUE & GROOVED, EDGE VEE 1 SIDE,
SMOOTH TEXTURE, FACTORY STAINED WITH ONE COAT.
DECK LAY-UP SHALL BE:
RANDOM LAY UP DECKING SHALL BE CONTINUOUS OVER THREE OR MORE
SPANS.  EACH PIECE OF DECK MUST BEAR ON AT LEAST ONE SUPPORT.
RANDOM LAY-UP DECKING SHALL BE LAID TO DISPERSE END-JOINTS SUCH
THAT:
DECKING AT CANTILEVERED OVERHANGS SHALL BE FREE OF END-JOINTS.
NAILING SCHEDULE - SEE DECK NAILING DETAIL 1 & 2/S400.
a. RANDOM LAY-UP OR TWO SPAN, SEE PLAN
a.
b.
THE DISTANCE BETWEEN END-JOINTS IN ADJACENT ROWS OF
DECKING IS AT LEAST TWO FEET.
THE DISTANCE BETWEEN END-JOINTS IN ROWS OF DECKING
SEPARATED BY ONLY ONE ROW IS AT LEAST ONE FOOT.
LAMINATED WOOD ROOF FRAMING NOTES
LAMINATED WOOD CONNECTION / HARDWARE NOTES:
1.
2.
3.
4.
5.
6.
7.
8.
ALL CONNECTIONS PLATES SHALL BE FABRICATED WITH ASTM A36 STEEL
WELDING SHALL BE PERFORMED IN ACCORDANCE WITH AWS STANDARDS
ALL HOLES SHALL BE 13/16" - UNLESS NOTED OTHERWISE
ALL BOLTS SHALL BE 3/4" ASTM A307 UNLESS NOTED OTHERWISE
ALL LAGS SHALL CONFORM TO ANSI/ASME STANDARDS
ALL SHEAR PLATES SHALL CONFORM TO ANSI/AF&PA STANDARDS
SHAPED STEEL CONNECTION PLATES MAY BE CUT FROM A SINGLE PLATE
OR CONSTRUCTED OF MULTIPLE PLATES w/ BEVELED, FULL PENETRATION
WELDS (GROUND SMOOTH)
ALL FABRICATED STEEL, BOLTS, WASHERS, SHEAR PLATES, LAGS, AND
NAILS SHALL BE HOT DIP GALVANIZED WHERE EXPOSED TO THE WEATHER OR
EMBEDDED IN CONCRETE.
LAMINATED WOOD STORAGE / ERECTION NOTES:
1.
2.
3.
4.
5.
6.
7.
8.
JOB-SITE STORAGE SHALL BE PROVIDED IN A LEVEL AREA TO PREVENT
WARPAGE.  MEMBERS SHALL BE SUPPORTED WITH BLOCKING SPACED TO
PROVIDE UNIFORM AND ADEQUATE SUPPORT.
MATERIAL SHALL BE BLOCKED WELL OFF THE GROUND AND SEPARATED
WITH STRIPPING TO ALLOW AIR CIRCULATION AROUND ALL FOUR SIDES OF
EACH MEMBER.
INDIVIDUAL MEMBER WRAPPINGS SHALL BE SLIT OR PUNCTURED ON THE
LOWER SIDE TO ALLOW DRAINAGE OF WATER.
MATERIAL SHALL BE STORED BENEATH AN OPAQUE, MOISTURE-RESISTANT
COVERING UNTIL ERECTED.
PADDED OR NONMARRING SLINGS SHALL BE USED FOR ERECTION, AND
CORNERS SHALL BE PROTECTED WITH WOOD BLOCKING.
PROVIDE ADEQUATE TEMPORARY BRACING UNTIL THE ROOF STRUCTURE
IS SHEATHED.
MODERATE USE OF DRIFT PINS, MODERATE REAMING, AND SLIGHT
CUTTING ARE ACCEPTABLE MEANS OF CORRECTION FOR PROPER
ASSEMBLY AND FITTING.  CONTACT PIERCE ENGINEERS FOR METHOD OF
CORRECTION IF ERROR OR MATERIAL DEFECTS DO NOT ALLOW PROPER
ASSEMBLY.
HEAT SHOULD NOT BE FULLY TURNED ON AS SOON AS THE STRUCTURE IS
ENCLOSED.  EXCESSIVE CHECKING MAY OCCUR DUE TO RAPID LOWERING
OF THE RELATIVE HUMIDITY IN THE BUILDING.  A GRADUAL SEASONING
PERIOD AT MODERATE TEMPERATURE SHOULD BE PROVIDED.
03/12/2015
2 ADDENDUM #1
1
1

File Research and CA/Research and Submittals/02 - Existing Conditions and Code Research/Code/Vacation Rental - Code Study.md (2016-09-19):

- Occupancy Types (303, 310, 508):
    - R-l Residential occupancies containing sleeping units where the occupants are primarily transient in nature, including:
	    - Boarding houses (transient) 
	    - Hotels (transient) 
	    - Motels (transient)
- Sprinkler System (903.2.8): 
	- - Required
- Type of Construction:  TYPE III-B
- General Building Height And Area Limitations
    - Residential Group R (TYPE III-B per Table 503)
        - Maximum Stories: 4  (Actual = 2 stories)
        - Maximum Square Footage: 1600 SF (Actual = xxx SF)
- Location on Property
- Means of Egress
- Accessiblity
	- 1107.6.1.2 all Type B units
	- (1) Accessible Unit (no roll-in shower necessary) - table 1107.6.1.1

- Building Separation and Shafts
- Fire Resistance Ratings (Table 601 for TYPE III-B construction):
    - Structural Frame:   0 hr
    - Bearing Walls- exterior: 2 hr
    - Bearing Walls-interior:  0 hr
    - Non-bearing walls-exterior:
        - Fire Separation Distance:
            - X < 5c = 1 hr
            - 5 ≤ X< 10 = 1 hr
            - 10 ≤ X< 30 = 1 hr
            - X ≥ 30 = 0 hr
    - Non-bearing walls-interior: 0 hr
    - Floor Construction: 0 hr
    - Roof Construction: 0 hr
- Fire Protection
	- Section 420, 709.1 and 712.3

Applicable Codes:

- Building/Dwelling Code IBC 2009 (WI Commercial Building Code, SPS 362)
- International Existing Building Code 2009 (WI Commercial Building Code, SPS 366)
- International  Energy  Conservation  Code 2009 (WI Commercial Building Code, v363)
- International  Plumbing Code (WI Commercial Building Code, SPS 381-387)
- Mechanical Code IMC 2009 (WI Commercial Building Code, SPS 364)
- Electrical Code NEC 2008(WI Commercial Building Code, SPS 316
- Fire/Life Safety Code 2009 NFPA-1 (WI Commercial Building Code, SPS 314 & 330)
- Accessibility Code ADA Standards (WI Commercial Building Code, SPS 362)
    - ANSI Stanadard A117.1-2009- for Accessibility
- International Fuel Gas Code 2009 (WI Commercial Building Code, Chapter 365)
- Zoning - Sun Prairie Zoning Regulations

Areas: 

- TI Interior Scope: 4,205 SF (1st Floor = 2505 SF; Basement = 1700 SF)
- Total Building Footprint: ~3011 SF
- Total Building Area: 9468 SF (1st Floor = 2505 SF; Basement = 2295 SF; 2nd&3rd Floors = 2334 SF)
- Site Zoning Classiﬁcation: (UC) Urban Commercial 
- Use of Tenant Space: Restaurant
- Alteration Level (IEBC 405):  Level 2 (TI Scope < (1/2 x Total Building Area)): (4,205 SF < (1/2 X 9468 SF))

- Table 508.4 Required Separation Of Occupancies (Hours) 
    - 2 hour floor separation between A-2 and R-2 occupancies 
- Fire Resistance Ratings (Table 601 for TYPE III-B construction):
    - Structural Frame:   0 hr
    - Bearing Walls- exterior: 2 hr
    - Bearing Walls-interior:  0 hr
    - Non-bearing walls-exterior:
        - Fire Separation Distance:
            - X < 5c = 1 hr
            - 5 ≤ X< 10 = 1 hr
            - 10 ≤ X< 30 = 1 hr
            - X ≥ 30 = 0 hr
    - Non-bearing walls-interior: 0 hr
    - Floor Construction: 0 hr
    - Roof Construction: 0 hr

- Corridor Fire Resistance Rating (Table 1018.1) 1 hr
- Interior Finishes (Table 803.9 - nonsprinklered)
    - Exit Enclosures and Passageways: Class A
    - Corridors: Class B in lobbys and Class A in all other spaces
    - Rooms and Enclosed Spaces: Class C for occupant loads < 300

- Occupant Load: (Table 1004.1.1) Maximum ﬂoor area allowances per occ. 
    - Residenital = 200sf/occupant
- Exit Access:
    - (1014.3) Common Path of Egress Travel:  75’
    - (1016.1) Maximum Travel Distance: 350’ w/ sprinklers
    - (Table 1015.1 & Table 1021.1) 
	    - Occupants ≥ 10 1 exit is required
	    - Occupants btwn (11-500) 2 exits are required
    - Dead end corridor max. length (IEBC) :  35’
- Plumbing Fixture Requirements (Table 2902.1): 47 males/48 females
- Water Closets
    - Female: (1 per 75) = 1 WC
    - Male: (1 per 75) = 1 WC
- Lavatories
    - Female: (1 per 200) = 1 Lavatory
    - Male: (1 per 200) = 1 Lavatory
- Drinking Fountains: None required IPC 410.1)
- Service Sink: 1

Fire Extinguishers:
Type: 2-A 10 lb
Distance to Extinguisher: 75’
Min. Rating: Class B
- 
-

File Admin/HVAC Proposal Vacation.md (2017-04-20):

<p align="right" style="" >

</p>

## Vacation Rental in Lake Geneva, WI

#### Proposal for [Desapex Engineering Consultants'](http://desapex.com/) Mechanical Design (HVAC) services

---
Hello, 

We are very happy to submit our proposal for the Mechanical design services for Vacation House in Lake Geneva, WI!  We have kept this simple with scope, time and fees.

---

####  Part A - Scope of work...
Although a more nuanced list of requirements will undoubtedly unfold as the project evolves, so far, on a high-level, we understand that the project will include the following...

 - Heating Ventilation & Air conditioning system design with load analysis for all 3500 sft space in accordance to requirements of Wisconsin SPS 364.
 - We can finalise on room to be eliminated from air conditioning 

---

#### Part B -Phases & Scope of Services

* **Phase 1 - Concept Design** 
*(approximate duration/fee: 0.3 weeks / 5% )*
    * Understand project existing conditions
    * Collect inputs for preliminary load calculation
    * Identify statutory requirements for the projects

* **Phase 2 - Schematic Design**
*(approximate duration/fee: 1.2 weeks / 20% )*
    * Heat gain/loss & ventilation calculation for all spaces.
    * Space allocation for AC equipment
    * Presenting design brief report in PowerPoint highlighting design consideration and basis of equipment selection.
    * Develop single line scheme routing for AC ducting/piping
    * Coordinate with Architect & other services consultants

* **Phase 3 - Design Development**
*(approximate duration/fee: 2.1 weeks / 35% )*
    * Develop approved design option
    * Update 3D model with approx. sizes of equipment
    * Discuss the selection of air terminals/AC equipment with client/Architect
    * Discuss structural requirements for floor mounted/ceiling suspended AC units
    * Developed deliverables will include:
        * Floor Plans
        * Sections detail
        * Civil requirement drawing
        * Ventilation scheme
        * Power requirement for AC equipment
    * Coordinate with Architect & other services consulatnts

* **Phase 4 - Tender Documentation**
*(approximate duration/fee: 2.1 weeks / 35% )*
     * Will complete the following drawings for Tender/contarctor quote:
        * Scope of work for the Mechanical/HVAC contractor.
        * Specification & performance requirements of all items in scope.
        * Bill of quantities of all items in scope
        * Equipment & Airterminal schedule
        * Tender drawings
	        * Mechanical/HVAC floor plan for each floor with equipment & air distribution details.
	        * Civil requirements drawing for each floor
	        * Sectional details
	        * Typical installation details of HVAC items in scope
		* Equipment, air terminal & damper schedules.
	    * Clarify design intent to the contractor and clarify any questions in preparing bid
        * Provide technical assistance to client (if required) in comparing/evaluating contractor's quote.
    * Continue to coordinate and communicate with Architect, other engineering consultant and contractor if necessary.

* **Phase 5 - Commissioning & Closure**
*(approximate duration/fee: 0.3 week / 5% )*
    * Monitor construction progress (remotely) and coordinate with HVAC contractor on site
    * coordinate with commissioning team
    * Review commissioning/balancing reports submitted by commissioning team
    * Review warranty & other closure documents submitted by contractor

---
#### Part C - Time, Fees and workflow

* Time required for above mentioned scope & phases is ** 6 weeks ** with 40 hour work week.
* **35 US$ per hour** is our hourly rate.
* Total fees shall not exceed **4200 USD**
* Payment shall be linked to phases of project and invoice shall be raised at the end of each phase.
* Payment needs to be made within 30 days of invoicing date.
* We understand the project file and project communication will be hosted on Github.  Specific location: https://github.com/OpeningDesign/Vacation_Rental
* We understand our digital content associated with this project will be licensed under an open source, 'copyleft' license: [Attribution-ShareAlike 4.0 International (CC BY-SA 4.0)](https://creativecommons.org/licenses/by-sa/4.0/).  Copyright and attribution of this content will be associated with [Desapex Engineering Consultants](http://desapex.com/).

---

We [(Desapex Engineering Consultants)](http://desapex.com/) sincerely appreciate the opportunity to provide you with this proposal and look forward to the potential of a fruitful collaboration in the future.

If any changes in scope or any other aspect needs to be made kindly let us know.
If the terms of this proposal are acceptable please sign in the space offered below.

We assure you best of our services.

<br>
Kind Regards,
<br>

Shreenidhi Hungund
Desapex Engineering Consultants

We agree to the terms mentioned in Part C with reference to scope of work mentioned in Part A & Part B.
We hereby appoint **Desapex Engineering Consultants** to provide design services for the project.

## Authorized by:

Representative for **OpeningDesign** 

* Signature
<hr>

* Title
<hr>

* Date
	<hr>

<br>
<br>
Representative for **Desapex Engineering Consultants** 

* Signature
<hr>

* Title
<hr>

* Date
	<hr>

<br>

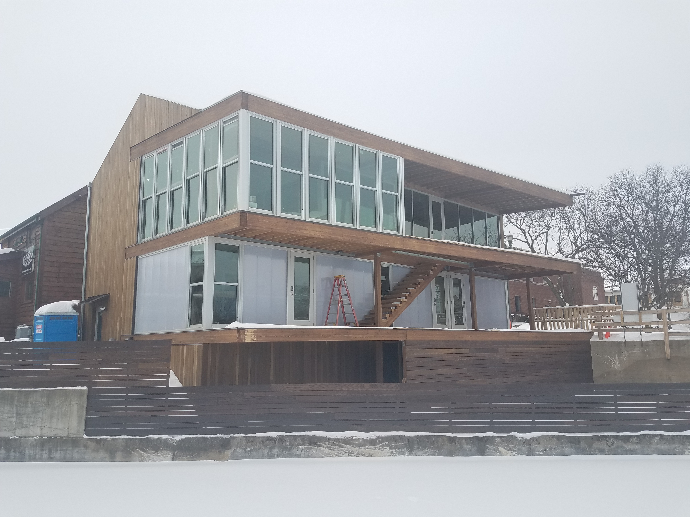
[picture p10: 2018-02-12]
Research and CA/Site Reports and Photos/20180212/2018-02-10 15.50.14.jpg

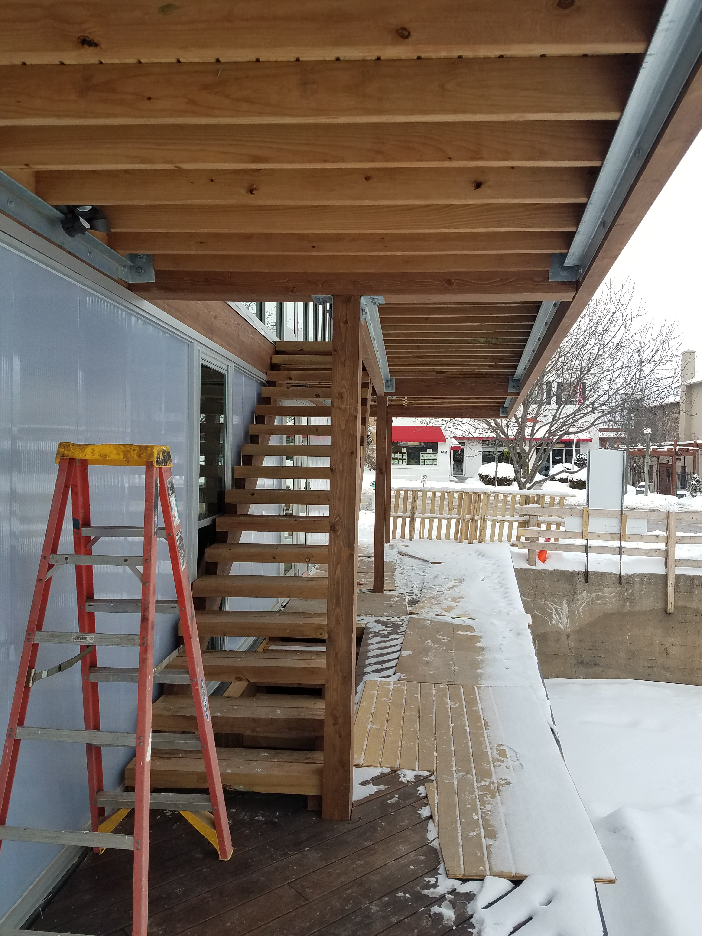
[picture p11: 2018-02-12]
Research and CA/Site Reports and Photos/20180212/2018-02-10 16.04.55.jpg

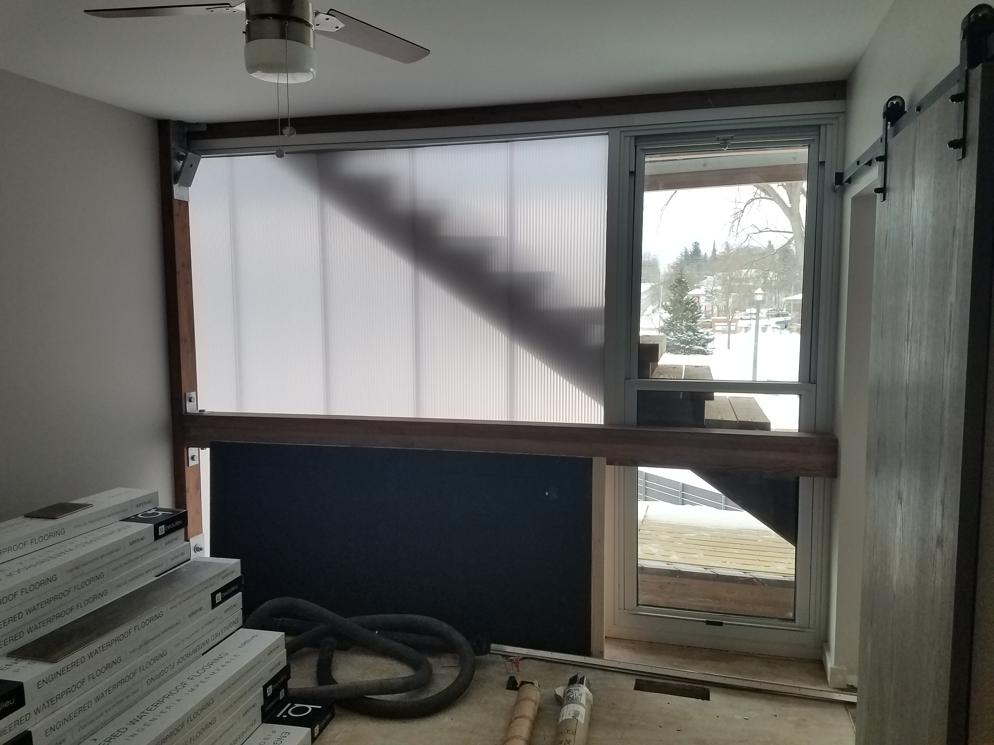
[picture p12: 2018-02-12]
Research and CA/Site Reports and Photos/20180212/2018-02-10 16.00.36.jpg

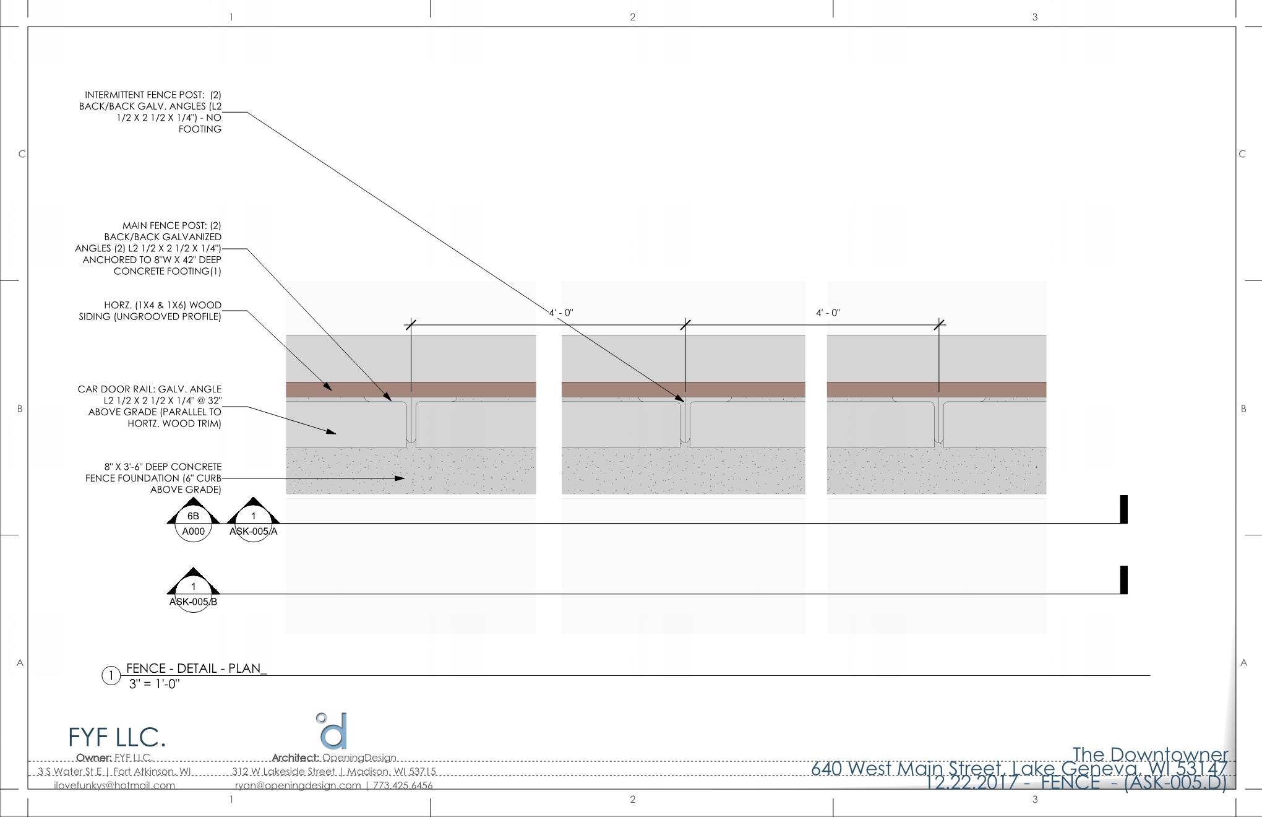
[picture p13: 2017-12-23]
Transfer/20171222 - fence design - owner review/20171223 - The Downtowner - Fence Details Page 004.jpg

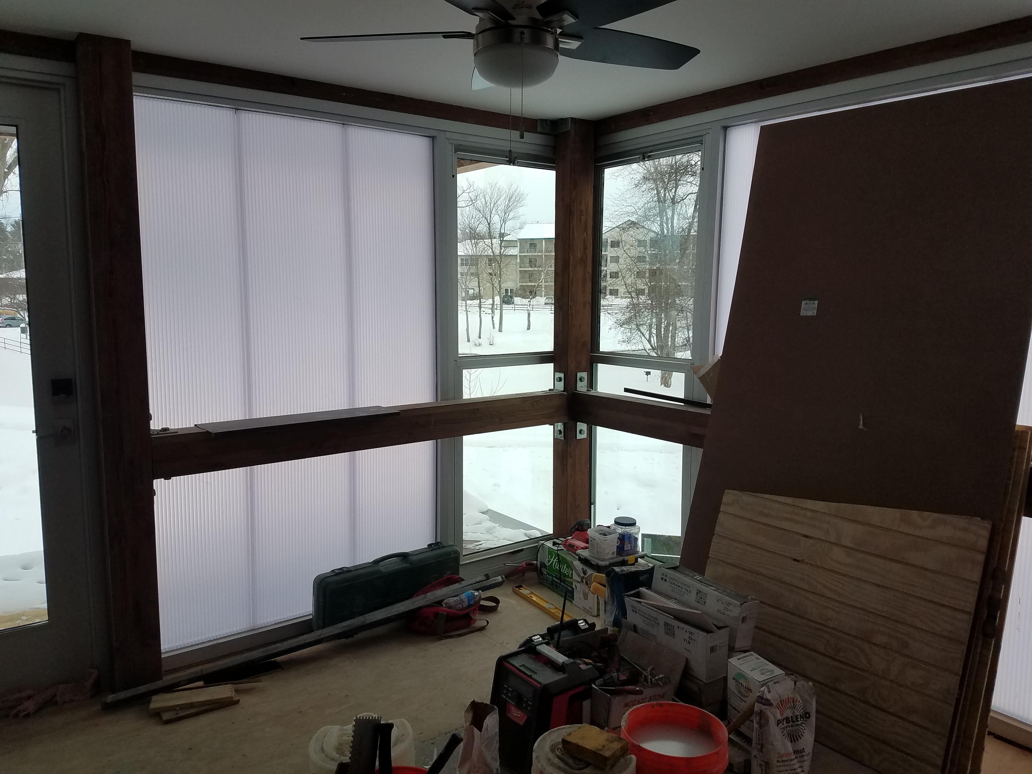
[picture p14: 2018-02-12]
Research and CA/Site Reports and Photos/20180212/2018-02-10 16.08.30.jpg

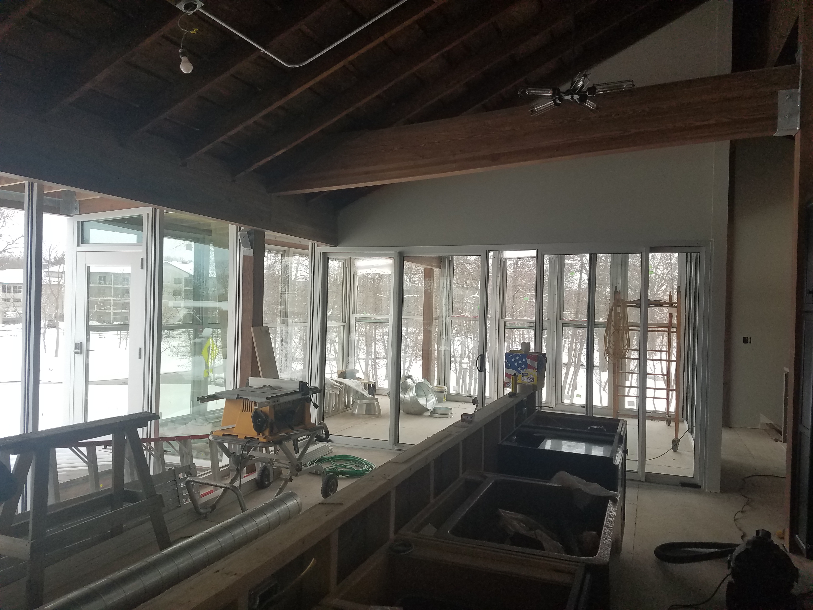
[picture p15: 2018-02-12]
Research and CA/Site Reports and Photos/20180212/2018-02-10 15.56.08.jpg

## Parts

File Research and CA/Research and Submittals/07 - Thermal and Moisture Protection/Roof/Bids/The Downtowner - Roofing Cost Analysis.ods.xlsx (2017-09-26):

Scope | Square Footage | Cost/SF | Total Installed | Notes
Demolition | 1542 SF | $1.50/sf | $2313.00 | This is an inferred number from numbers assocated with demoing floors and ceilings.
9” insulation | 1542 SF | $6.33/sf | $9760.86 | see source numbers below. 6.33/sf = ($4.83 + 1.5/sf for plywood and vapor barrier)
Standing Seam Roof | 1975 SF | $11.00/sf | $21725.00 | see source numbers below.
Gutter | 104 LF | $11.80/lf | $1227.20 | see source numbers below.
Downspout | 23 LF | $7.75/lf | $178.25 | see source numbers below.
Snow Guards | 104 LF | $12.00/lf | $1248.00
Total |  |  | $36452.31
Insulation
Line Number | Main |  | Ind 1 | Ind 2 | Ind 3 | Ind 4 | Unit | Material | Installation | Total | Notes
B30103201510 |  |  | Polyisocyanurate 2#/CF density, 1" thick |  |  |  | S.F. | $0.63 | $0.43 | $1.06
B30103201550 |  |  |  |  | 1 1/2" thick |  | S.F. | $0.80 | $0.47 | $1.27
B30103201600 |  |  |  |  | 2" thick |  | S.F. | $1.00 | $0.51 | $1.51
B30103201650 |  |  |  |  | 2 1/2" thick |  | S.F. | $1.30 | $0.53 | $1.83
B30103201700 |  |  |  |  | 3" thick |  | S.F. | $1.43 | $0.54 | $1.97 | $4.83 = (3 * $1.43) + $0.54 (conservative number, since installation would be greater with more insulation)
B30103201750 |  |  |  |  | 3 1/2" thick |  | S.F. | $2.17 | $0.54 | $2.71
Standing Seam Roof
Line Number | Main |  | Ind 1 | Ind 2 | Ind 3 | Ind 4 | Unit | Material | Installation | Total | Notes
B30101350800 | Formed Metal
B30101351000 |  |  | Batten seam, formed copper roofing, 3" min slope, 16 oz., 1.2 P.S.F. |  |  |  | S.F. | $13.57 | $5.57 | $19.14
B30101351100 |  |  |  |  |  | 18 oz., 1.35 P.S.F. | S.F. | $15.04 | $6.10 | $21.14
B30101352000 |  |  |  | Zinc copper alloy, 3" min slope, .020" thick, .88 P.S.F. |  |  | S.F. | $13.82 | $5.07 | $18.89
B30101353000 |  |  | Flat seam, copper, 1/4" min. slope, 16 oz., 1.2 P.S.F. |  |  |  | S.F. | $9.90 | $5.07 | $14.97 | The galvanized roof we’re using would be less than the copper price here, so I used $11/sf, which also checks out from an internet search
B30101353100 |  |  |  |  |  | 18 oz., 1.35 P.S.F. | S.F. | $11.12 | $5.28 | $16.40
B30101355000 |  |  | Standing seam, copper, 2-1/2" min. slope, 16 oz., 1.25 P.S.F. |  |  |  | S.F. | $10.63 | $4.70 | $15.33
B30101355100 |  |  |  |  |  | 18 oz., 1.40 P.S.F. | S.F. | $11.86 | $5.07 | $16.93
B30101356000 |  |  |  | Zinc copper alloy, 2-1/2" min. slope, .020" thick, .87 P.S.F. |  |  | S.F. | $13.33 | $5.07 | $18.40
B30101356100 |  |  |  |  |  | .032" thick, 1.39 P.S.F. | S.F. | $19.21 | $5.57 | $24.78
Gutters
Line Number | Main |  | Ind 1 | Ind 2 | Ind 3 | Ind 4 | Unit | Material | Installation | Total | Notes
B30106100040 |  | Gutters
B30106100041 |  | SECTION MATERIAL THICKNESS SIZE FINISH
B30106100050 |  | Boxaluminum.027"5"enameled |  |  |  |  | L.F. | $3.11 | $4.95 | $8.06
B30106100100 |  | mill |  |  |  |  | L.F. | $3.13 | $4.95 | $8.08
B30106100200 |  | .032"5"enameled |  |  |  |  | L.F. | $3.87 | $4.79 | $8.66
B30106100500 |  | copper16 0z.5"lead coated |  |  |  |  | L.F. | $19.60 | $4.79 | $24.39
B30106100600 |  | mill |  |  |  |  | L.F. | $8.67 | $4.79 | $13.46
B30106101000 |  | steel galv.28 Ga.5"enameled |  |  |  |  | L.F. | $2.35 | $4.79 | $7.14
B30106101200 |  | 26 Ga.5"mill |  |  |  |  | L.F. | $2.59 | $4.79 | $7.38
B30106101800 |  | vinyl 4"colors |  |  |  |  | L.F. | $1.40 | $4.66 | $6.06
B30106101900 |  | 5"colors |  |  |  |  | L.F. | $1.72 | $4.66 | $6.38
B30106102300 |  | hemlock or fir 4"x5"treated |  |  |  |  | L.F. | $18.08 | $5.35 | $23.43
B30106103000 |  | Half roundcopper16 Oz.4"lead coated |  |  |  |  | L.F. | $15.83 | $4.79 | $20.62
B30106103100 |  | mill |  |  |  |  | L.F. | $10.24 | $4.79 | $15.03
B30106103600 |  | steel galv.28 Ga.5"enameled |  |  |  |  | L.F. | $2.35 | $4.79 | $7.14
B30106104102 |  | stainless steel 5"mill |  |  |  |  | L.F. | $10.19 | $4.79 | $14.98
B30106105000 |  | vinyl 4"white |  |  |  |  | L.F. | $1.46 | $4.66 | $6.12
 |  |  |  |  |  |  |  |  |  | $11.80 | Took Average
Downspout
Line Number | Main |  | Ind 1 | Ind 2 | Ind 3 | Ind 4 | Unit | Material | Installation | Total | Notes
B30106200040 |  | Downspouts
B30106200041 |  | MATERIALS SECTION SIZE FINISH THICKNESS
B30106200100 |  | Aluminumrectangular2"x3"embossed mill.020" |  |  |  |  | V.L.F. | $1.14 | $3.16 | $4.30
B30106200150 |  | enameled.020" |  |  |  |  | V.L.F. | $1.50 | $3.16 | $4.66
B30106200250 |  | 3"x4"enameled.024" |  |  |  |  | V.L.F. | $2.56 | $4.28 | $6.84
B30106200300 |  | round corrugated3"enameled.020" |  |  |  |  | V.L.F. | $2.16 | $3.16 | $5.32
B30106200350 |  | 4"enameled.025" |  |  |  |  | V.L.F. | $3.19 | $4.28 | $7.47
B30106200500 |  | Copperrectangular corr.2"x3"mill16 Oz. |  |  |  |  | V.L.F. | $9.41 | $3.16 | $12.57
B30106200600 |  | smooth mill16 Oz. |  |  |  |  | V.L.F. | $11.91 | $3.16 | $15.07
B30106200700 |  | rectangular corr.3"x4"mill16 Oz. |  |  |  |  | V.L.F. | $11.22 | $4.13 | $15.35
B30106201300 |  | Steelrectangular corr.2"x3"galvanized28 Ga. |  |  |  |  | V.L.F. | $2.09 | $3.16 | $5.25
B30106201350 |  | epoxy coated24 Ga. |  |  |  |  | V.L.F. | $2.51 | $3.16 | $5.67
B30106201400 |  | smooth galvanized28 Ga. |  |  |  |  | V.L.F. | $3.94 | $3.16 | $7.10
B30106201450 |  | rectangular corr.3"x4"galvanized28 Ga. |  |  |  |  | V.L.F. | $1.96 | $4.13 | $6.09
B30106201500 |  | epoxy coated24 Ga. |  |  |  |  | V.L.F. | $3.05 | $4.13 | $7.18
B30106201550 |  | smooth galvanized28 Ga. |  |  |  |  | V.L.F. | $4.38 | $4.13 | $8.51
B30106201600 |  | round corrugated2"galvanized28 Ga. |  |  |  |  | V.L.F. | $2.26 | $3.16 | $5.42
B30106201650 |  | 3"galvanized28 Ga. |  |  |  |  | V.L.F. | $2.26 | $3.16 | $5.42
B30106201700 |  | 4"galvanized28 Ga. |  |  |  |  | V.L.F. | $2.71 | $4.13 | $6.84
B30106201750 |  | 5"galvanized28 Ga. |  |  |  |  | V.L.F. | $4.02 | $4.61 | $8.63
 |  |  |  |  |  |  |  |  |  | $7.65 | Took Average

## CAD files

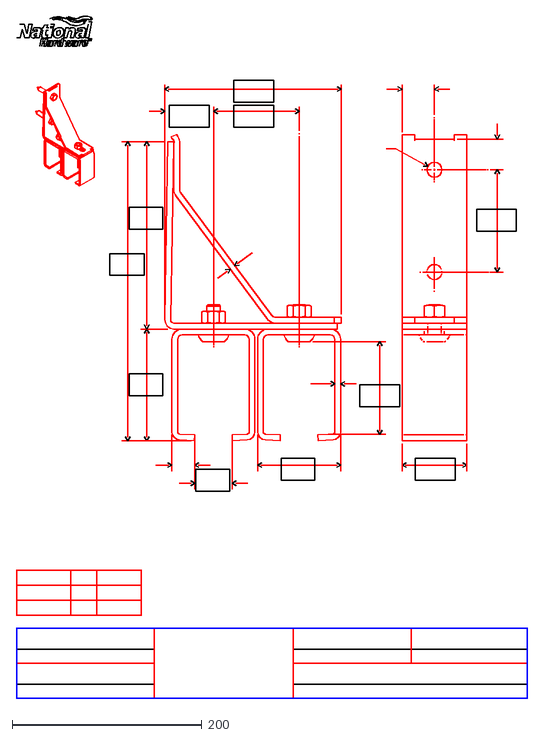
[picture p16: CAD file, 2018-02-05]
Research and CA/Research and Submittals/08 - Openings/Gate Hardware/51h-51hbc-double-box-rail-bracket_techdrawing.dxf
539.9 x 719.7

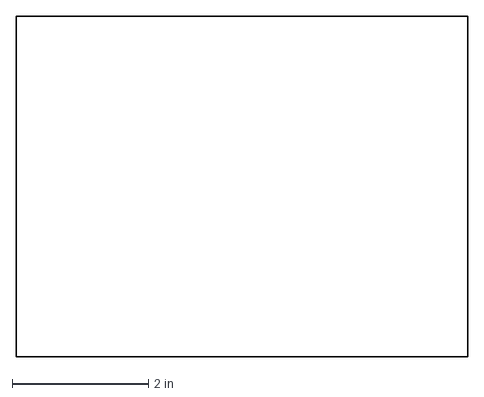
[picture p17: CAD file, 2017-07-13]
Transfer/20170626 - example files for bracket fabrication/Flat pattern - ITEM#3.DXF
6.62 x 5.00 in

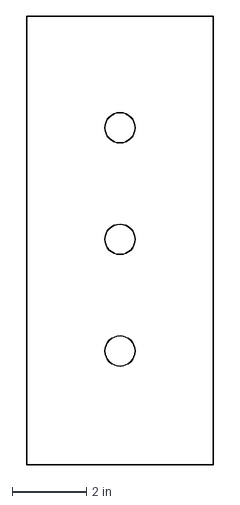
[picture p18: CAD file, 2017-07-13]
Transfer/20170626 - example files for bracket fabrication/Flat pattern - ITEM#1.DXF
5.00 x 12.1 in

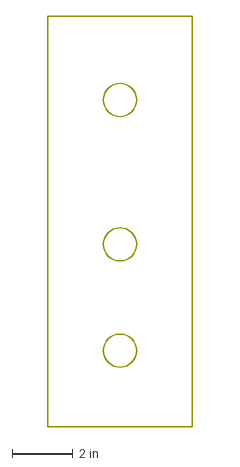
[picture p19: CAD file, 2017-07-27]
Transfer/20170726 - to Metal Fabricator - connection shop drawings/(C-2-2-1ST) - SECTION LOOKING NORTH (4 COPIES).dxf
4.75 x 13.5 in

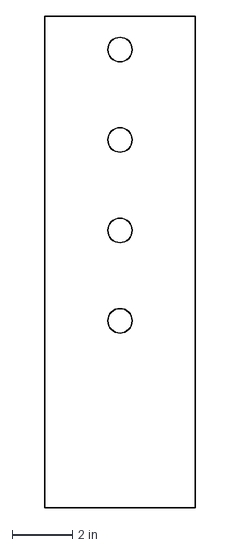
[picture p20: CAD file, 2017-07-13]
Transfer/20170626 - example files for bracket fabrication/Flat pattern - ITEM#2.DXF
5.00 x 16.3 in

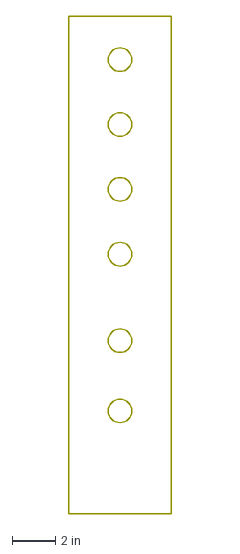
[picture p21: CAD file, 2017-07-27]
Transfer/20170726 - to Metal Fabricator - connection shop drawings/(C-ROOF) - SECTION LOOKING SOUTH (4 COPIES).dxf
4.75 x 23.0 in

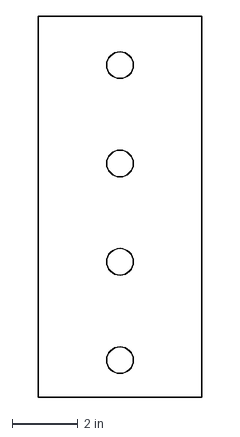
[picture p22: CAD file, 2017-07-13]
Transfer/20170626 - example files for bracket fabrication/Flat pattern - ITEM#4.DXF
5.00 x 11.6 in

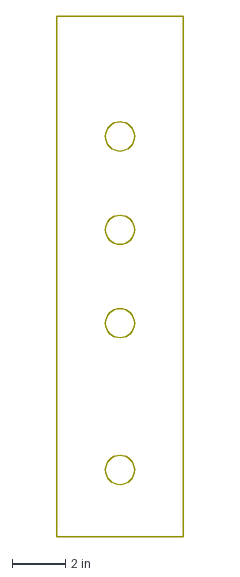
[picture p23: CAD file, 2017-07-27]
Transfer/20170726 - to Metal Fabricator - connection shop drawings/(C-3-2ND) - HIGH - SECTION LOOKING SOUTH (2 COPIES).dxf
4.75 x 19.5 in

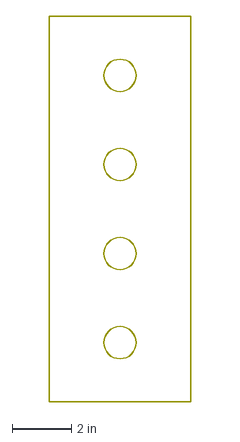
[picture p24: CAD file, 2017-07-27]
Transfer/20170726 - to Metal Fabricator - connection shop drawings/(C-Roof) SECTION LOOKING EAST (6 COPIES).dxf
4.75 x 13.0 in

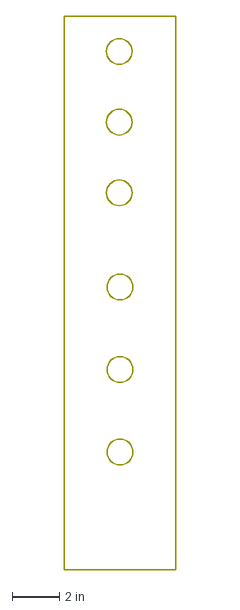
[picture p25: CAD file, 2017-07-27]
Transfer/20170726 - to Metal Fabricator - connection shop drawings/(C-3-2ND) - LOW - SECTION LOOKING SOUTH (2 COPIES).dxf
4.75 x 23.5 in

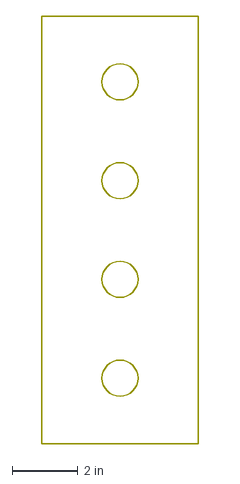
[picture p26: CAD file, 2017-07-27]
Transfer/20170726 - to Metal Fabricator - connection shop drawings/(C-2ND) - SECTION LOOKING EAST (4 COPIES).dxf
4.75 x 13.0 in

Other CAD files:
Research and CA/Research and Submittals/02 - Existing Conditions and Code Research/Topo_REDUCED.dwg
Transfer/20170726 - to Metal Fabricator - connection shop drawings/(C-2-2-2ND) - Plate 1 (2 COPIES).dxf
Research and CA/Research and Submittals/02 - Existing Conditions and Code Research/Topo.dwg
Research and CA/Research and Submittals/02 - Existing Conditions and Code Research/Streets & buildings.dwg
Research and CA/Research and Submittals/02 - Existing Conditions and Code Research/Cadastral Map.dwg
Research and CA/Research and Submittals/02 - Existing Conditions and Code Research/Cadastral Map2.dwg

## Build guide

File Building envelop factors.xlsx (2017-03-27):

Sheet: Wall
Element | Sections | Thickness (In) | Thermal Resistance "R " ( °F Ft² Hr/BTU) | U (BTU/Hr °F Ft²) | Density (lb/Sft) | Description
West wall | Inside air film | - | 0.68 |  |  | Table -18 ,ASHRE Fundamentals
 | gyp board | 0.625 | 0.56
 | gyp board | 0.625 | 0.56
 | Existing or new wood stud | 3.5 | 3.29
 | fibre glass mat gypsum panel | 0.625 | 0
 | fibre glass mat gypsum panel | 0.625 | 0
 | cont. rigid insulation ( class A flame spread) | 0.75 | 0
 | UV stable water resistant vapour permeable air barrier | - | 0.06
 | EPDM SHIMS under hat channel | 0.25
 | Galvanised( perforated or punched ) horizontal hat channel | 0.875 | 0
 | open joint siding ( chemically treated wood accoya wood) | 0.75 | 0
 | Outside air film | - | 0.25
 | Total | 8.625 | 5.4 | 0.19
South wall | Inside air film | - | 0.68
 | gyp board | 0.625 | 0.56
 | Existing or new wood stud | 3.5 | 3.29
 | fibre glass mat gypsum panel | 0.625
 | cont. rigid insulation ( class A flame spread) | 0.75
 | UV stable water resistant vapour permeable air barrier | 0 | 0.87
 | EPDM SHIMS under hat channel | 0.25
 | Galvanised( perforated or punched ) horizontal hat channel | 0.875 | 0
 | open joint siding ( chemically treated wood accoya wood) | 0.75 | 0
 | Outside air film | - | 0.25
 | Total | 7.375 | 5.65 | 0.18
North wall | Inside air film | - | 0.68
 | gyp board | 0.625 | 0.56
 | Existing or new wood stud | 3.5 | 3.29
 | fibre glass mat gypsum panel | 0.625 | 0
 | cont. rigid insulation ( class A flame spread) | 0.75 | 0
 | UV stable water resistant vapour permeable air barrier | 0 | 0.87
 | EPDM SHIMS under hat channel | 0.25 | 0
 | Galvanised( perforated or punched ) horizontal hat channel | 0.875 | 0
 | open joint siding ( chemically treated wood accoya wood) | 0.75 | 0
 | Outside air film | - | 0.25
 | Total | 7.375 | 5.65 | 0.18
East curtan wall( first floor) | Inside air film | - | 0.68
 | Poly carbonate panel ( first floor)
 | outside air film | - | 0.25
 | Total |  | 0.93 | 1.08
East curtain wall(Second floor) | inside air film | - | 0.68
 | curtain wall ( second floor)
 | Outside air film | - | 0.25
 | Total |  | 0.93 | 1.08
Interior walls | Inside air film | - | 0.68
 | Gypsum wall board | 0.5 | 0.45
 | Existing or new wood stud | 3.5 | 3.29
 | Gypsum wall board | 0.5 | 0.45
 | Inside air film | - | 0.68
 | Total | 4.5 | 5.55 | 0.18

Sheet: Roof-floor
Element | Sections | Thickness (In) | Thermal Resistance "R " ( °F Ft² Hr/BTU) | U (BTU/Hr °F Ft²) | Density (lb/Sft) | Description
Roof( inclined) | Inside air film | - | 0.92
 | 1X12 joist (existing) | 1
 | plywood substrate( existing) | 0.75 | 0.94
 | Rigid insulation | 5.5
 | Plywood substrate | 0.5 | 0.625
 | Standing seam metal roof (galv-ten robust) | 0.5 | 0
 | outside air film | - | 0.25
 | Total | 8.25 | 2.735 | 0.37
2F Floor | Inside air film | - | 0.68
 | Wood plank sub floor( existing) | 2.5 | 2.35
 | Elastic imapct base mat | 1
 | separating layer | 0.5
 | Dense-sound check layer | 0.5
 | New wood floor | 0.75 | 0.705
 | Inside air film | - | 0.25
 | Total | 5.25 | 3.985 | 0.25
1F Floor | Inside air film | - | 0.68
 | Wood Floor (NEW) | 0.75 | 0.705
 | New Sub floor | 4
 | Existing concrete slab | 6 | 1.62
 | Existing Crushed stone | 6
 | Total | 16.75 | 3.005 | 0.33

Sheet: Window
Element | Sections | Thickness (In) | Thermal Resistance "R " ( °F Ft² Hr/BTU) | U (BTU/Hr °F Ft²) | Description
West windows | Inside air film | - | 0.68
 | Glass & frame | 0.63 | 0
 | Outside air film | - | 0.25
 | Total | 0.63 | 0.93 | 1.08
South windows | Inside air film | - | 0.68
 | Glass & frame | 0.63 | 0
 | Outside air film | - | 0.25
 | Total | 0.63 | 0.93 | 1.08
North windows | Inside air film | - | 0.68
 | Glass & frame | 0.63 | 0
 | Outside air film | - | 0.25
 | Total | 0.63 | 0.93 | 1.08
East windows | Inside air film | - | 0.68
 | Glass & frame | 0.63 | 0
 | Outside air film | - | 0.25
 | Total | 0.63 | 0.93 | 1.08

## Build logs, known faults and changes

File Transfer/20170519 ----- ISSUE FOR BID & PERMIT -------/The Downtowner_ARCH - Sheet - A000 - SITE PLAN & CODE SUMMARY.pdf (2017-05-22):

# 9' - 5 1/2" ²' - 4 1/2" 9'x18' STALL

# MAIN STREET

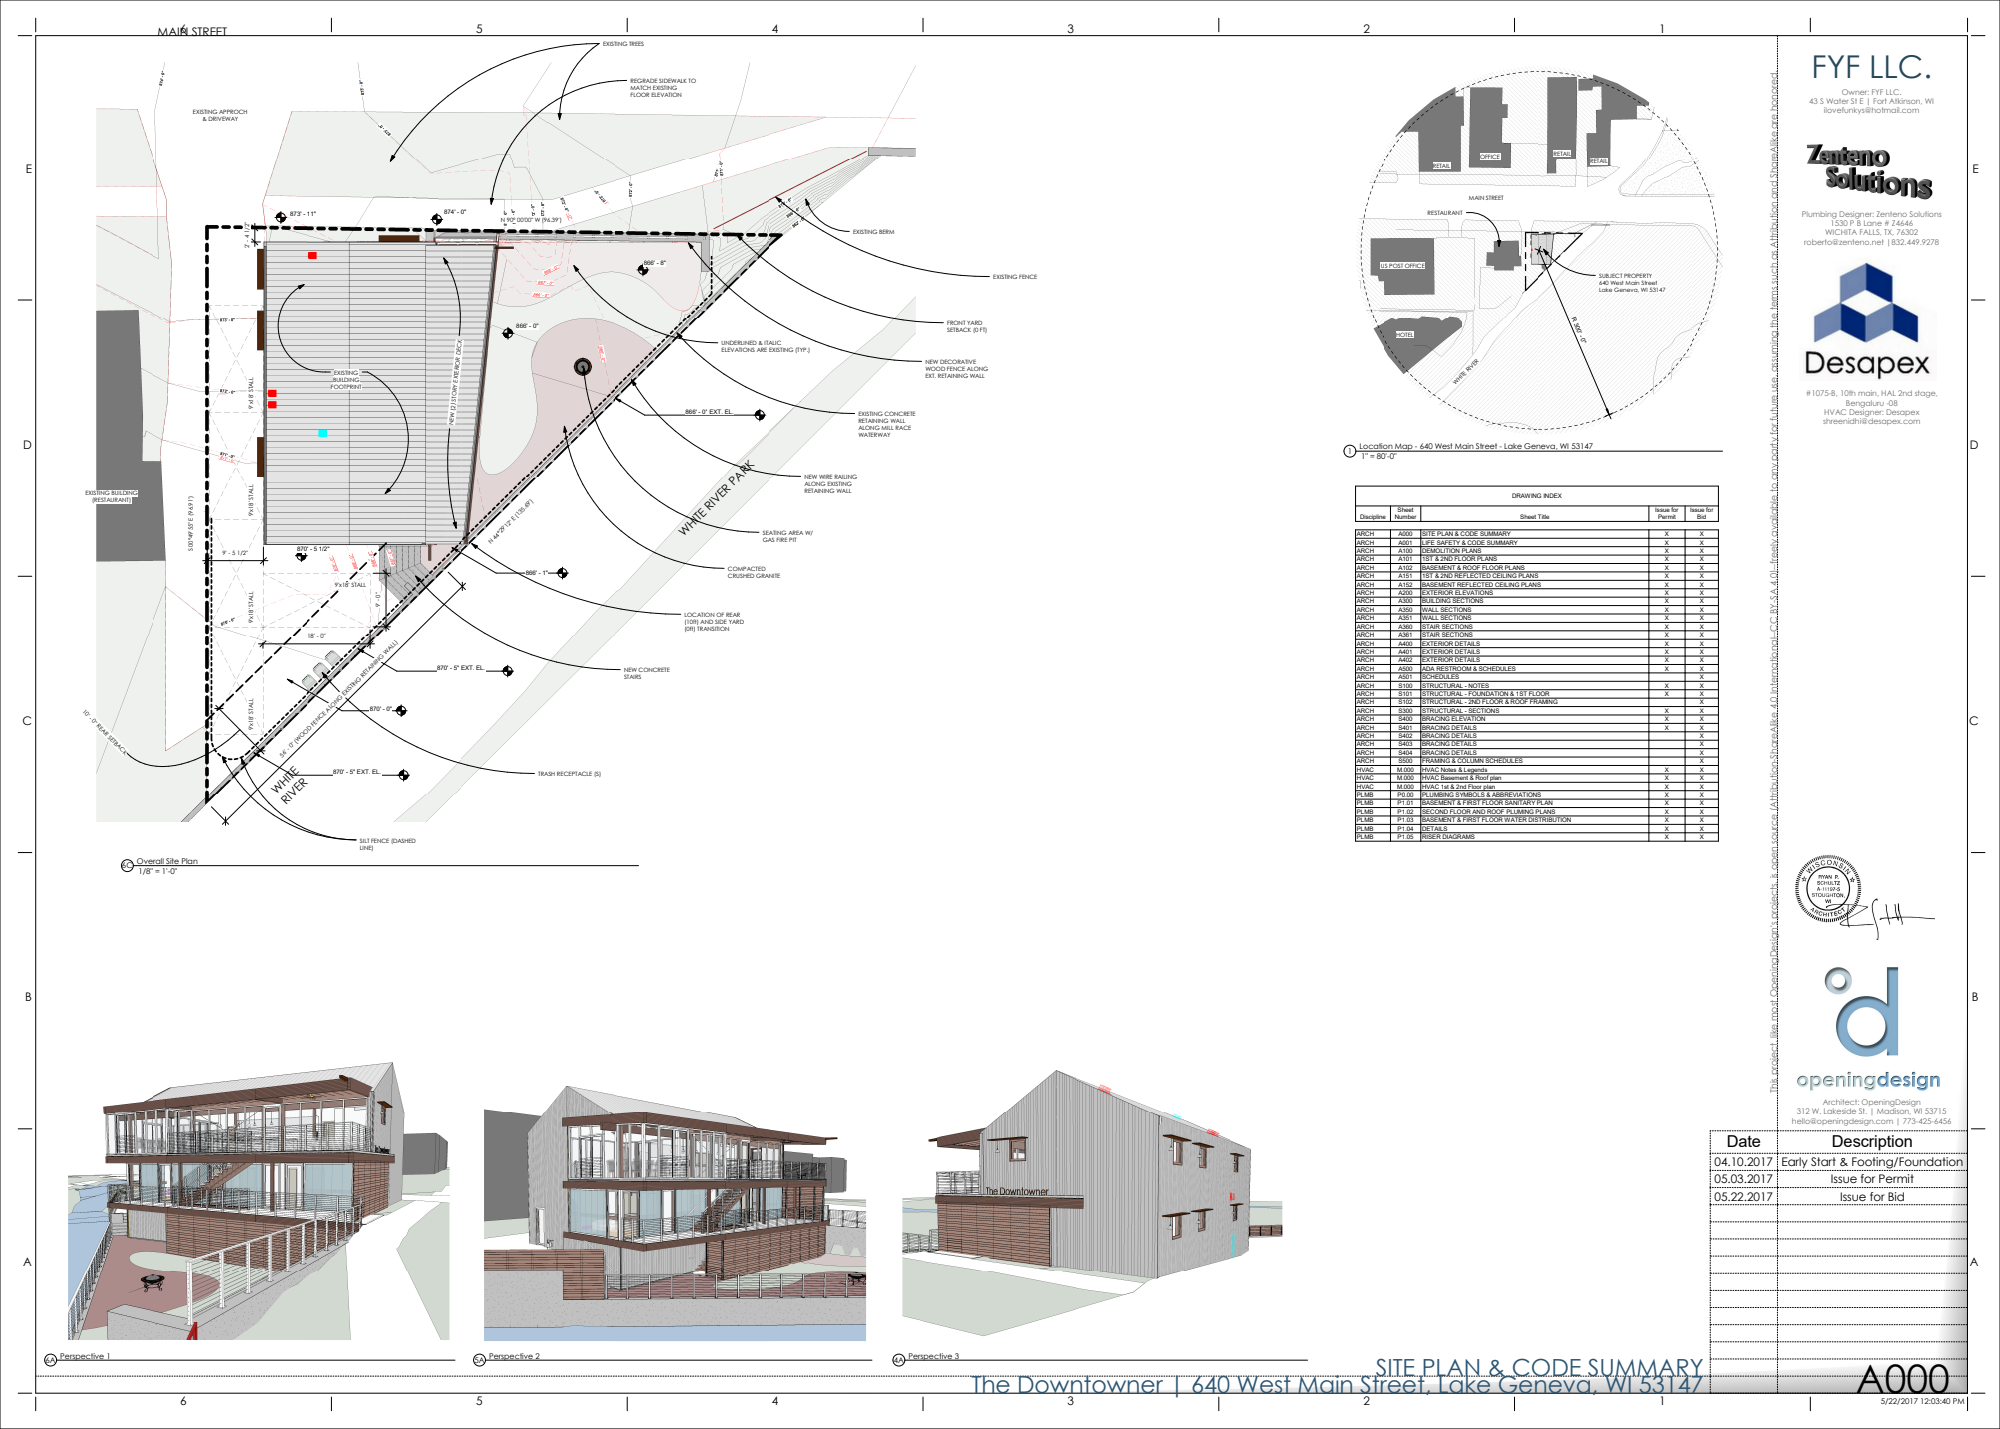
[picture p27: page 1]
870' - 5" EXT. EL.; 866' - 0" EXT. EL.; EXISTING BERM; 9'x18' STALL; 10' - 0" REAR SETBACK; EXISTING APPROCH & DRIVEWAY; EXISTING TREES; TRASH RECEPTACLE (S); WHITE RIVER; NEW CONCRETE STAIRS; EXISTING FENCE; COMPACTED CRUSHED GRANITE; NEW (2) STO; Y EXTERIO; DEC; FRONT YARD SETBACK (0 FT); EXISTING BUILDING (RESTAURANT); HOTEL; RESTAURANT; OFFICE; RETAIL; MAIN STREET; Architect: OpeningDesign; FYF LLC.; 6A Perspective 1; 5A Perspective 2; DRAWING INDEX; Discipline; Sheet; Number; Sheet Title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

This project, like most OpeningDesign's projects, is open source (Attribution-ShareAlike 4.0 International--CC BY-SA 4.0)--freely available to any party for future use, assuming the terms such as Attribution and ShareAlike are honored.

REGRADE SIDEWALK TO
MATCH EXISTING
FLOOR ELEVATION

Owner: FYF LLC.

43 S Water St E | Fort Atkinson, WI
ilovefunkys@hotmail.com

Plumbing Designer: Zenteno Solutions

1530 P B Lane # Z4646
WICHITA FALLS, TX, 76302
roberto@zenteno.net |832.449.9278

US POST OFFICE

SUBJECT PROPERTY
640 West Main Street
Lake Geneva, WI 53147

UNDERLINED & ITALIC
ELEVATIONS ARE EXISTING (TYP.)

NEW DECORATIVE
WOOD FENCE ALONG

EXT. RETAINING WALL EXISTING
BUILDING
FOOTPRINT

9'x18' STALL 9'x18' STALL 9'x18' STALL

#1075-B, 10th main, HAL 2nd stage,

Bengaluru -08
HVAC Designer: Desapex
shreenidhi@desapex.com

EXISTING CONCRETE
RETAINING WALL
ALONG MILL RACE
WATERWAY

Location Map - 640 West Main Street - Lake Geneva, WI 53147

WHITE RIVER PARK

NEW WIRE RAILING
ALONG EXISTING

SEATING AREA W/
GAS FIRE PIT

ARCH | A000 | SITE PLAN & CODE SUMMARY | X | X
ARCH | A001 | LIFE SAFETY & CODE SUMMARY | X | X
ARCH | A100 | DEMOLITION PLANS | X | X
ARCH | A101 | 1ST & 2ND FLOOR PLANS | X | X
ARCH | A102 | BASEMENT & ROOF FLOOR PLANS | X | X
ARCH | A151 | 1ST & 2ND REFLECTED CEILING PLANS | X | X
ARCH | A152 | BASEMENT REFLECTED CEILING PLANS | X | X
ARCH | A200 | EXTERIOR ELEVATIONS | X | X
ARCH | A300 | BUILDING SECTIONS | X | X
ARCH | A350 | WALL SECTIONS | X | X
ARCH | A351 | WALL SECTIONS | X | X
ARCH | A360 | STAIR SECTIONS | X | X
ARCH | A361 | STAIR SECTIONS | X | X
ARCH | A400 | EXTERIOR DETAILS | X | X
ARCH | A401 | EXTERIOR DETAILS | X | X
ARCH | A402 | EXTERIOR DETAILS | X | X
ARCH | A500 | ADA RESTROOM & SCHEDULES | X | X
ARCH | A501 | SCHEDULES | | X
ARCH | S100 | STRUCTURAL - NOTES | X | X
ARCH | S101 | STRUCTURAL - FOUNDATION & 1ST FLOOR | X | X
ARCH | S102 | STRUCTURAL - 2ND FLOOR & ROOF FRAMING | | X
ARCH | S300 | STRUCTURAL - SECTIONS | X | X
ARCH | S400 | BRACING ELEVATION | X | X
ARCH | S401 | BRACING DETAILS | X | X
ARCH | S402 | BRACING DETAILS | | X
ARCH | S403 | BRACING DETAILS | | X
ARCH | S404 | BRACING DETAILS | | X
ARCH | S500 | FRAMING & COLUMN SCHEDULES | | X
HVAC | M.000 | HVAC Notes & Legends | X | X
HVAC | M.000 | HVAC Basement & Roof plan | X | X
HVAC | M.000 | HVAC 1st & 2nd Floor plan | X | X
PLMB | P0.00 | PLUMBING SYMBOLS & ABBREVIATIONS | X | X
PLMB | P1.01 | BASEMENT & FIRST FLOOR SANITARY PLAN | X | X
PLMB | P1.02 | SECOND FLOOR AND ROOF PLUMING PLANS | X | X
PLMB | P1.03 | BASEMENT & FIRST FLOOR WATER DISTRIBUTION | X | X
PLMB | P1.04 | DETAILS | X | X
PLMB | P1.05 | RISER DIAGRAMS | X | X

LOCATION OF REAR
(10ft) AND SIDE YARD
(0ft) TRANSITION

56' - 0" (WOOD FENCE ALONG EXISTING RETAINING WALL)

SILT FENCE (DASHED
LINE)

1/8" = 1'-0" 6C Overall Site Plan

312 W. Lakeside St. | Madison, WI 53715
hello@openingdesign.com | 773-425-6456

04.10.2017 Early Start & Footing/Foundation
05.03.2017 Issue for Permit
05.22.2017 Issue for Bid

Perspective 3
The Downtowner | 640 West Main Street, Lake Geneva, WI 53147

SITE PLAN & CODE SUMMARY

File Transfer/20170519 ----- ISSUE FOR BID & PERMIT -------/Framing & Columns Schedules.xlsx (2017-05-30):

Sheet: Structural Column Schedule
Structural Column Schedule
MARK | TYPE | LEVEL | LEVEL OFFSET | COLUMN LOCATION | LENGTH | DESCRIPTION - FINISH | Top Offset
Basement
 | 5 1/8" x 6" G.L. | Basement | 0' - 2" | B.5-E | 6' - 5 3/4" | GLULAMS COLUMNS - EXTERIOR (PRESSURE TREATED W/ PENTA IN SOLVENT) (STAIN: PENOFIN VERDE EXT. STAIN - COLOR: CEDAR) | -1' - 1"
 | 5 1/8" x 6" G.L. | Basement | 0' - 2" | B.5-E.1 | 6' - 6 3/4" | GLULAMS COLUMNS - EXTERIOR (PRESSURE TREATED W/ PENTA IN SOLVENT) (STAIN: PENOFIN VERDE EXT. STAIN - COLOR: CEDAR) | -1' - 0"
 | 5 1/8" x 6" G.L. | Basement | 0' - 2" | E-2 | 6' - 5 3/4" | GLULAMS COLUMNS - EXTERIOR (PRESSURE TREATED W/ PENTA IN SOLVENT) (STAIN: PENOFIN VERDE EXT. STAIN - COLOR: CEDAR) | -1' - 1"
 | 5 1/8" x 6" G.L. | Basement | 0' - 2" | E-3 | 6' - 5 3/4" | GLULAMS COLUMNS - EXTERIOR (PRESSURE TREATED W/ PENTA IN SOLVENT) (STAIN: PENOFIN VERDE EXT. STAIN - COLOR: CEDAR) | -1' - 1"
 | 5 1/8" x 6" G.L. | Basement | 0' - 2" | E.1-2 | 6' - 6 3/4" | GLULAMS COLUMNS - EXTERIOR (PRESSURE TREATED W/ PENTA IN SOLVENT) (STAIN: PENOFIN VERDE EXT. STAIN - COLOR: CEDAR) | -1' - 0"
 | 5 1/8" x 6" G.L. | Basement | 0' - 2" | E.1-3 | 6' - 5 3/4" | GLULAMS COLUMNS - EXTERIOR (PRESSURE TREATED W/ PENTA IN SOLVENT) (STAIN: PENOFIN VERDE EXT. STAIN - COLOR: CEDAR) | -1' - 1"
5 1/8" x 6" G.L.: 6 |  |  |  |  | 39' - 0 1/2"
 | 40" | Basement | -5' - 4 1/2" | E-1.AA | 5' - 1" | 40" DIAMETER X 5FT DEEP SONO PIER WITH (4) - #5 BARS VERTICAL AND #3 TIES AT 12" O.C. | -0' - 3 1/2"
 | 40" | Basement | -5' - 4 1/2" | E-2 | 5' - 1" | 40" DIAMETER X 5FT DEEP SONO PIER WITH (4) - #5 BARS VERTICAL AND #3 TIES AT 12" O.C. | -0' - 3 1/2"
 | 40" | Basement | -5' - 3 1/2" | E-3 | 5' - 0" | 40" DIAMETER X 5FT DEEP SONO PIER WITH (4) - #5 BARS VERTICAL AND #3 TIES AT 12" O.C. | -0' - 3 1/2"
40": 3 |  |  |  |  | 15' - 2"
 | PIPE COLUMN | Basement | 0' - 0" | B(-2' - 0 13/16")-5.A(2' - 10 29/32") | 7' - 0 1/4" | Steel ASTM A53 | -0' - 8 1/2"
PIPE COLUMN: 1 |  |  |  |  | 7' - 0 1/4"
Basement: 10 |  |  |  |  | 61' - 2 3/4"
1st Floor
 | 5 1/8" x 6" G.L. | 1st Floor | 0' - 0" | B.5-E | 9' - 0" | GLULAMS COLUMNS - EXTERIOR (PRESSURE TREATED W/ PENTA IN SOLVENT) (STAIN: PENOFIN VERDE EXT. STAIN - COLOR: CEDAR) | -0' - 2 1/2"
 | 5 1/8" x 6" G.L. | 1st Floor | 0' - 0" | E-2 | 7' - 9" | GLULAMS COLUMNS - EXTERIOR (PRESSURE TREATED W/ PENTA IN SOLVENT) (STAIN: PENOFIN VERDE EXT. STAIN - COLOR: CEDAR) | -1' - 5 1/2"
 | 5 1/8" x 6" G.L. | 1st Floor | 0' - 0" | E-3 | 7' - 9" | GLULAMS COLUMNS - EXTERIOR (PRESSURE TREATED W/ PENTA IN SOLVENT) (STAIN: PENOFIN VERDE EXT. STAIN - COLOR: CEDAR) | -1' - 5 1/2"
 | 5 1/8" x 6" G.L. | 1st Floor | -0' - 0 3/4" | B-2 | 6' - 9 11/32" | GLULAMS COLUMNS - INTERIOR - (STAIN TO MATCH EXTERIOR COLUMNS) | -2' - 5 29/32"
 | 5 1/8" x 6" G.L. | 1st Floor | -0' - 0 3/4" | B-2.9 | 6' - 9 11/32" | GLULAMS COLUMNS - INTERIOR - (STAIN TO MATCH EXTERIOR COLUMNS) | -2' - 5 29/32"
 | 5 1/8" x 6" G.L. | 1st Floor | -1' - 0" | B-3 | 8' - 2 1/2" | GLULAMS COLUMNS - INTERIOR - (STAIN TO MATCH EXTERIOR COLUMNS) | -2' - 0"
 | 5 1/8" x 6" G.L. | 1st Floor | -1' - 0" | B-5.A | 9' - 4 1/2" | GLULAMS COLUMNS - INTERIOR - (STAIN TO MATCH EXTERIOR COLUMNS) | -0' - 10"
 | 5 1/8" x 6" G.L. | 1st Floor | -0' - 0 3/4" | B-B.5 | 8' - 5 1/4" | GLULAMS COLUMNS - INTERIOR - (STAIN TO MATCH EXTERIOR COLUMNS) | -0' - 10"
 | 5 1/8" x 6" G.L. | 1st Floor | -0' - 0 3/4" | B-B.5(-1' - 0 3/16") | 6' - 9 11/32" | GLULAMS COLUMNS - INTERIOR - (STAIN TO MATCH EXTERIOR COLUMNS) | -2' - 5 29/32"
 | 5 1/8" x 6" G.L. | 1st Floor | -0' - 0 3/4" | B.5-C.2 | 8' - 5 1/4" | GLULAMS COLUMNS - INTERIOR - (STAIN TO MATCH EXTERIOR COLUMNS) | -0' - 10"
 | 5 1/8" x 6" G.L. | 1st Floor | -0' - 0 3/4" | C.2-2 | 8' - 0 3/4" | GLULAMS COLUMNS - INTERIOR - (STAIN TO MATCH EXTERIOR COLUMNS) | -1' - 2 1/2"
 | 5 1/8" x 6" G.L. | 1st Floor | -0' - 0 3/4" | C.2-2.2 | 8' - 5 1/4" | GLULAMS COLUMNS - INTERIOR - (STAIN TO MATCH EXTERIOR COLUMNS) | -0' - 10"
 | 5 1/8" x 6" G.L. | 1st Floor | -1' - 0" | C.2-3 | 8' - 9" | GLULAMS COLUMNS - INTERIOR - (STAIN TO MATCH EXTERIOR COLUMNS) | -1' - 5 1/2"
 | 5 1/8" x 6" G.L. | 1st Floor | -1' - 0" | C.2-5.A | 9' - 4 1/2" | GLULAMS COLUMNS - INTERIOR - (STAIN TO MATCH EXTERIOR COLUMNS) | -0' - 10"
5 1/8" x 6" G.L.: 14 |  |  |  |  | 113' - 11 1/16"
 | 5 1/8" X 6" GLULAM @ JAMB | 1st Floor | -0' - 0 3/4" | C.1(0' - 8 1/16")-1.5(-3' - 1 13/32") | 8' - 3 1/4" | GLULAMS COLUMNS - INTERIOR - (STAIN TO MATCH EXTERIOR COLUMNS) | -1' - 0"
 | 5 1/8" X 6" GLULAM @ JAMB | 1st Floor | -1' - 0" | C.1(0' - 8 1/16")-4(1' - 2 3/4") | 9' - 8 1/2" | GLULAMS COLUMNS - INTERIOR - (STAIN TO MATCH EXTERIOR COLUMNS) | -0' - 6"
 | 5 1/8" X 6" GLULAM @ JAMB | 1st Floor | -1' - 0" | C.1(0' - 8 3/8")-3(-4' - 10 3/4") | 9' - 8 1/2" | GLULAMS COLUMNS - INTERIOR - (STAIN TO MATCH EXTERIOR COLUMNS) | -0' - 6"
5 1/8" X 6" GLULAM @ JAMB: 3 |  |  |  |  | 27' - 8 1/4"
1st Floor: 17 |  |  |  |  | 141' - 7 5/16"
2nd Floor
 | 5 1/8" x 6" G.L. | 2nd Floor | -0' - 2 1/2" | B-2 | 13' - 2 1/4" | GLULAMS COLUMNS - INTERIOR - (STAIN TO MATCH EXTERIOR COLUMNS) | 4' - 8 1/2"
 | 5 1/8" x 6" G.L. | 2nd Floor | -1' - 0" | B-3 | 13' - 11 3/4" | GLULAMS COLUMNS - INTERIOR - (STAIN TO MATCH EXTERIOR COLUMNS) | 4' - 8 1/2"
 | 5 1/8" x 6" G.L. | 2nd Floor | -0' - 10" | B-5.A | 13' - 9 3/4" | GLULAMS COLUMNS - INTERIOR - (STAIN TO MATCH EXTERIOR COLUMNS) | 4' - 8 1/2"
 | 5 1/8" x 6" G.L. | 2nd Floor | -0' - 10" | B-B.5 | 13' - 9 3/4" | GLULAMS COLUMNS - INTERIOR - (STAIN TO MATCH EXTERIOR COLUMNS) | 4' - 8 1/2"
 | 5 1/8" x 6" G.L. | 2nd Floor | -0' - 10" | B.5-C.2 | 9' - 4 1/2" | GLULAMS COLUMNS - INTERIOR - (STAIN TO MATCH EXTERIOR COLUMNS) | 0' - 3 1/4"
 | 5 1/8" x 6" G.L. | 2nd Floor | -0' - 2 1/2" | C.2-2 | 8' - 9" | GLULAMS COLUMNS - INTERIOR - (STAIN TO MATCH EXTERIOR COLUMNS) | 0' - 3 1/4"
 | 5 1/8" x 6" G.L. | 2nd Floor | -0' - 10" | C.2-2.2 | 9' - 4 1/2" | GLULAMS COLUMNS - INTERIOR - (STAIN TO MATCH EXTERIOR COLUMNS) | 0' - 3 1/4"
 | 5 1/8" x 6" G.L. | 2nd Floor | -0' - 2 1/2" | C.2-3 | 8' - 9" | GLULAMS COLUMNS - INTERIOR - (STAIN TO MATCH EXTERIOR COLUMNS) | 0' - 3 1/4"
 | 5 1/8" x 6" G.L. | 2nd Floor | -0' - 10" | C.2-5.A | 9' - 4 1/2" | GLULAMS COLUMNS - INTERIOR - (STAIN TO MATCH EXTERIOR COLUMNS) | 0' - 3 1/4"
5 1/8" x 6" G.L.: 9 |  |  |  |  | 100' - 5"
2nd Floor: 9 |  |  |  |  | 100' - 5"
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

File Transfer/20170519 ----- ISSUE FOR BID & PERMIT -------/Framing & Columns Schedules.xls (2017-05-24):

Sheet: Structural Column Schedule
Structural Column Schedule
MARK | TYPE | LEVEL | LEVEL OFFSET | COLUMN LOCATION | LENGTH | DESCRIPTION - FINISH | Top Offset
Basement
 | 5 1/8" x 6" G.L. | Basement | 0' - 2" | B.5-E | 6' - 5 3/4" | GLULAMS COLUMNS - EXTERIOR (PRESSURE TREATED W/ PENTA IN SOLVENT) (STAIN: PENOFIN VERDE EXT. STAIN - COLOR: CEDAR) | -1' - 1"
 | 5 1/8" x 6" G.L. | Basement | 0' - 2" | B.5-E.1 | 6' - 6 3/4" | GLULAMS COLUMNS - EXTERIOR (PRESSURE TREATED W/ PENTA IN SOLVENT) (STAIN: PENOFIN VERDE EXT. STAIN - COLOR: CEDAR) | -1' - 0"
 | 5 1/8" x 6" G.L. | Basement | 0' - 2" | E-2 | 6' - 5 3/4" | GLULAMS COLUMNS - EXTERIOR (PRESSURE TREATED W/ PENTA IN SOLVENT) (STAIN: PENOFIN VERDE EXT. STAIN - COLOR: CEDAR) | -1' - 1"
 | 5 1/8" x 6" G.L. | Basement | 0' - 2" | E-3 | 6' - 5 3/4" | GLULAMS COLUMNS - EXTERIOR (PRESSURE TREATED W/ PENTA IN SOLVENT) (STAIN: PENOFIN VERDE EXT. STAIN - COLOR: CEDAR) | -1' - 1"
 | 5 1/8" x 6" G.L. | Basement | 0' - 2" | E.1-2 | 6' - 6 3/4" | GLULAMS COLUMNS - EXTERIOR (PRESSURE TREATED W/ PENTA IN SOLVENT) (STAIN: PENOFIN VERDE EXT. STAIN - COLOR: CEDAR) | -1' - 0"
 | 5 1/8" x 6" G.L. | Basement | 0' - 2" | E.1-3 | 6' - 5 3/4" | GLULAMS COLUMNS - EXTERIOR (PRESSURE TREATED W/ PENTA IN SOLVENT) (STAIN: PENOFIN VERDE EXT. STAIN - COLOR: CEDAR) | -1' - 1"
5 1/8" x 6" G.L.: 6 |  |  |  |  | 39' - 0 1/2"
 | 40" | Basement | -5' - 4 1/2" | E-1.AA | 5' - 1" | 40" DIAMETER X 5FT DEEP SONO PIER WITH (4) - #5 BARS VERTICAL AND #3 TIES AT 12" O.C. | -0' - 3 1/2"
 | 40" | Basement | -5' - 4 1/2" | E-2 | 5' - 1" | 40" DIAMETER X 5FT DEEP SONO PIER WITH (4) - #5 BARS VERTICAL AND #3 TIES AT 12" O.C. | -0' - 3 1/2"
 | 40" | Basement | -5' - 3 1/2" | E-3 | 5' - 0" | 40" DIAMETER X 5FT DEEP SONO PIER WITH (4) - #5 BARS VERTICAL AND #3 TIES AT 12" O.C. | -0' - 3 1/2"
40": 3 |  |  |  |  | 15' - 2"
 | PIPE COLUMN | Basement | 0' - 0" | B(-2' - 0 13/16")-5.A(2' - 10 29/32") | 7' - 0 1/4" | Steel ASTM A53 | -0' - 8 1/2"
PIPE COLUMN: 1 |  |  |  |  | 7' - 0 1/4"
Basement: 10 |  |  |  |  | 61' - 2 3/4"
1st Floor
 | 5 1/8" x 6" G.L. | 1st Floor | 0' - 0" | B.5-E | 9' - 0" | GLULAMS COLUMNS - EXTERIOR (PRESSURE TREATED W/ PENTA IN SOLVENT) (STAIN: PENOFIN VERDE EXT. STAIN - COLOR: CEDAR) | -0' - 2 1/2"
 | 5 1/8" x 6" G.L. | 1st Floor | 0' - 0" | E-2 | 7' - 9" | GLULAMS COLUMNS - EXTERIOR (PRESSURE TREATED W/ PENTA IN SOLVENT) (STAIN: PENOFIN VERDE EXT. STAIN - COLOR: CEDAR) | -1' - 5 1/2"
 | 5 1/8" x 6" G.L. | 1st Floor | 0' - 0" | E-3 | 7' - 9" | GLULAMS COLUMNS - EXTERIOR (PRESSURE TREATED W/ PENTA IN SOLVENT) (STAIN: PENOFIN VERDE EXT. STAIN - COLOR: CEDAR) | -1' - 5 1/2"
 | 5 1/8" x 6" G.L. | 1st Floor | -0' - 0 3/4" | B-2 | 6' - 9 11/32" | GLULAMS COLUMNS - INTERIOR - (STAIN TO MATCH EXTERIOR COLUMNS) | -2' - 5 29/32"
 | 5 1/8" x 6" G.L. | 1st Floor | -0' - 0 3/4" | B-2.9 | 6' - 9 11/32" | GLULAMS COLUMNS - INTERIOR - (STAIN TO MATCH EXTERIOR COLUMNS) | -2' - 5 29/32"
 | 5 1/8" x 6" G.L. | 1st Floor | -1' - 0" | B-3 | 8' - 2 1/2" | GLULAMS COLUMNS - INTERIOR - (STAIN TO MATCH EXTERIOR COLUMNS) | -2' - 0"
 | 5 1/8" x 6" G.L. | 1st Floor | -1' - 0" | B-5.A | 9' - 4 1/2" | GLULAMS COLUMNS - INTERIOR - (STAIN TO MATCH EXTERIOR COLUMNS) | -0' - 10"
 | 5 1/8" x 6" G.L. | 1st Floor | -0' - 0 3/4" | B-B.5 | 8' - 5 1/4" | GLULAMS COLUMNS - INTERIOR - (STAIN TO MATCH EXTERIOR COLUMNS) | -0' - 10"
 | 5 1/8" x 6" G.L. | 1st Floor | -0' - 0 3/4" | B-B.5(-1' - 0 3/16") | 6' - 9 11/32" | GLULAMS COLUMNS - INTERIOR - (STAIN TO MATCH EXTERIOR COLUMNS) | -2' - 5 29/32"
 | 5 1/8" x 6" G.L. | 1st Floor | -0' - 0 3/4" | B.5-C.2 | 8' - 5 1/4" | GLULAMS COLUMNS - INTERIOR - (STAIN TO MATCH EXTERIOR COLUMNS) | -0' - 10"
 | 5 1/8" x 6" G.L. | 1st Floor | -0' - 0 3/4" | C.2-2 | 8' - 0 3/4" | GLULAMS COLUMNS - INTERIOR - (STAIN TO MATCH EXTERIOR COLUMNS) | -1' - 2 1/2"
 | 5 1/8" x 6" G.L. | 1st Floor | -0' - 0 3/4" | C.2-2.2 | 8' - 5 1/4" | GLULAMS COLUMNS - INTERIOR - (STAIN TO MATCH EXTERIOR COLUMNS) | -0' - 10"
 | 5 1/8" x 6" G.L. | 1st Floor | -1' - 0" | C.2-3 | 8' - 9" | GLULAMS COLUMNS - INTERIOR - (STAIN TO MATCH EXTERIOR COLUMNS) | -1' - 5 1/2"
 | 5 1/8" x 6" G.L. | 1st Floor | -1' - 0" | C.2-5.A | 9' - 4 1/2" | GLULAMS COLUMNS - INTERIOR - (STAIN TO MATCH EXTERIOR COLUMNS) | -0' - 10"
5 1/8" x 6" G.L.: 14 |  |  |  |  | 113' - 11 1/16"
 | 5 1/8" X 6" GLULAM @ JAMB | 1st Floor | -0' - 0 3/4" | C.1(0' - 8 1/16")-1.5(-3' - 1 13/32") | 8' - 3 1/4" | GLULAMS COLUMNS - INTERIOR - (STAIN TO MATCH EXTERIOR COLUMNS) | -1' - 0"
 | 5 1/8" X 6" GLULAM @ JAMB | 1st Floor | -1' - 0" | C.1(0' - 8 1/16")-4(1' - 2 3/4") | 9' - 8 1/2" | GLULAMS COLUMNS - INTERIOR - (STAIN TO MATCH EXTERIOR COLUMNS) | -0' - 6"
 | 5 1/8" X 6" GLULAM @ JAMB | 1st Floor | -1' - 0" | C.1(0' - 8 3/8")-3(-4' - 10 3/4") | 9' - 8 1/2" | GLULAMS COLUMNS - INTERIOR - (STAIN TO MATCH EXTERIOR COLUMNS) | -0' - 6"
5 1/8" X 6" GLULAM @ JAMB: 3 |  |  |  |  | 27' - 8 1/4"
1st Floor: 17 |  |  |  |  | 141' - 7 5/16"
2nd Floor
 | 5 1/8" x 6" G.L. | 2nd Floor | -0' - 2 1/2" | B-2 | 13' - 2 1/4" | GLULAMS COLUMNS - INTERIOR - (STAIN TO MATCH EXTERIOR COLUMNS) | 4' - 8 1/2"
 | 5 1/8" x 6" G.L. | 2nd Floor | -1' - 0" | B-3 | 13' - 11 3/4" | GLULAMS COLUMNS - INTERIOR - (STAIN TO MATCH EXTERIOR COLUMNS) | 4' - 8 1/2"
 | 5 1/8" x 6" G.L. | 2nd Floor | -0' - 10" | B-5.A | 13' - 9 3/4" | GLULAMS COLUMNS - INTERIOR - (STAIN TO MATCH EXTERIOR COLUMNS) | 4' - 8 1/2"
 | 5 1/8" x 6" G.L. | 2nd Floor | -0' - 10" | B-B.5 | 13' - 9 3/4" | GLULAMS COLUMNS - INTERIOR - (STAIN TO MATCH EXTERIOR COLUMNS) | 4' - 8 1/2"
 | 5 1/8" x 6" G.L. | 2nd Floor | -0' - 10" | B.5-C.2 | 9' - 4 1/2" | GLULAMS COLUMNS - INTERIOR - (STAIN TO MATCH EXTERIOR COLUMNS) | 0' - 3 1/4"
 | 5 1/8" x 6" G.L. | 2nd Floor | -0' - 2 1/2" | C.2-2 | 8' - 9" | GLULAMS COLUMNS - INTERIOR - (STAIN TO MATCH EXTERIOR COLUMNS) | 0' - 3 1/4"
 | 5 1/8" x 6" G.L. | 2nd Floor | -0' - 10" | C.2-2.2 | 9' - 4 1/2" | GLULAMS COLUMNS - INTERIOR - (STAIN TO MATCH EXTERIOR COLUMNS) | 0' - 3 1/4"
 | 5 1/8" x 6" G.L. | 2nd Floor | -0' - 2 1/2" | C.2-3 | 8' - 9" | GLULAMS COLUMNS - INTERIOR - (STAIN TO MATCH EXTERIOR COLUMNS) | 0' - 3 1/4"
 | 5 1/8" x 6" G.L. | 2nd Floor | -0' - 10" | C.2-5.A | 9' - 4 1/2" | GLULAMS COLUMNS - INTERIOR - (STAIN TO MATCH EXTERIOR COLUMNS) | 0' - 3 1/4"
5 1/8" x 6" G.L.: 9 |  |  |  |  | 100' - 5"
2nd Floor: 9 |  |  |  |  | 100' - 5"
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

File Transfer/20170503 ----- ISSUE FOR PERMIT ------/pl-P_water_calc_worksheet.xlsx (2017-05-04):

WATER CALCULATION WORKSHEET FOR: Project Name, Job Number, City, State
 | Date Designer
BUILDING INFORMATION
1. | Demand of building in gallons per minute (65 SFU). |  |  | 33 | gpm
2. | Size of the water meter. (Proposed size for hydraulic calcs, subject to Water Utility review.) |  |  | 1.50 | inch
3. | Low pressure at building entrance. |  |  | 35.0 | psi
CALCULATE PRESSURE AVAILABLE AFTER BUILDING CONTROL VALVE
4. | Low pressure at building entrance. |  |  | 40.0 | psi
5. | Pressure loss due to water meter. |  |  | 2.0 | psi
6. | Available pressure after building water meter. |  | (Line 6 - 7a - 7b - 8) | 38.0 | psi
CALCULATE PRESSURE AVAILABLE FOR UNIFORM LOSS (VALUE OF “A”)
B. | Available distribution pressure. |  | (Line 9 + B1 - B2) | 38.0 | psi
D. | Pressure required at controlling fixture. (Shower in second floor bathroom.) |  |  | 20.0 | psi
 |  |  | Subtotal | 18.0 | psi
E. | Head loss from the building control valve to the controlling fixture.
 | (Elevation change, multiply by 0.434 psi/ft.)
 | Elevation change ft | 25 |  | 10.8 | psi
 |  |  | Subtotal | 7.2 | psi
F. | Pressure loss due to water treatment devices, instantaneous water heaters,
 | backflow preventers, and other accessories which serve the controlling fixture.
 | N/A |  |  | 0.0 | psi
 |  |  | Total Available Pressure | 7.2 | psi
G. | Actual pipe length from building control valve to controlling fixture ft | 80
 | Developed length. (Actual length, multiply by fitting/loss factor.) | fitting/loss factor | 1.5 | 120.0 | feet
 | Pressure available for uniform loss. (Total Available Pressure / Developed Length.) |  |  | 0.060 | psi/ft
 | Pressure available for uniform loss per 100 ft. (Multiply by 100 / 100.) |  |  | 6.0 | psi/100 ft
A. | Pressure available for uniform loss per 100 ft. (Value rounded up to next integer.) |  | “A” = | 6.0 | psi/100 ft

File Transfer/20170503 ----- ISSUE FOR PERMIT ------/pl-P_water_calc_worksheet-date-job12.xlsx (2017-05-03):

WATER CALCULATION WORKSHEET FOR: Project Name, Job Number, City, State
 | Date Designer
BUILDING INFORMATION
1. | Demand of building in gallons per minute. (xxx SFU/xx gpm current, xxx SFU/xxx gpm future.) |  |  | 58 | gpm
2. | Rise in elevation from hydrant to building control valve. (Negative value indicates elevation drop.) |  |  | 15.0 | feet
3. | Size of the water meter. (Proposed size for hydraulic calcs, subject to Water Utility review.) |  |  | 1.50 | inch
4. | Length of service from main to building control valve. |  |  |  | feet
5. | Low pressure at hydrant elevation. (Hydrant flow test dated xx/xxx/2011.) |  |  |  | psi
CALCULATE PRESSURE AVAILABLE AFTER BUILDING CONTROL VALVE
6. | Low pressure at hydrant elevation. (Value from 5. above.) |  |  | 0.0 | psi
7a. | Water service loss. (Pipe diameter is xx inch, material is K-copper/PVC/ductile iron, multiply pressure loss by value from 4. above, divide by 100.)
 | Pressure loss psi/100ft |  |  | 0.0 | psi
7b. | Pressure loss due to exterior water meter (x.x psi) and exterior RPZ (xx.x psi - 8 to12 psi). |  |  |  | psi
8. | Determine pressure loss (gain) due to rise (drop) in elevation.
 | (Value from 2. above, multiply by 0.434 psi/ft.) |  |  | 6.5 | psi
9. | Available pressure after building control valve. |  | (Line 6 - 7a - 7b - 8) | -6.5 | psi
CALCULATE PRESSURE AVAILABLE FOR UNIFORM LOSS (VALUE OF “A”)
B1. | Booster pump pressure increase. (Enter zero if not applicable.) |  |  |  | psi
B2. | Water pressure reducing valve pressure decrease. (Enter zero if not applicable.) |  |  |  | psi
B. | Available distribution pressure. |  | (Line 9 + B1 - B2) | -6.5 | psi
C. | Pressure loss due to interior water meter (x.x psi) and building interior RPZ (xx.x psi - 8 to12 psi). |  |  |  | psi
 |  |  | Subtotal | -6.5 | psi
D. | Pressure required at controlling fixture. (Eyewash 30/35 psig, room xx.) |  |  |  | psi
 |  |  | Subtotal | -6.5 | psi
E. | Head loss from the building control valve to the controlling fixture.
 | (Elevation change, multiply by 0.434 psi/ft.)
 | Elevation change ft |  |  | 0.0 | psi
 |  |  | Subtotal | -6.5 | psi
F. | Pressure loss due to water treatment devices, instantaneous water heaters,
 | backflow preventers, and other accessories which serve the controlling fixture.
 | (List devices, if any, e.g., thermostatic mixing valve.) |  |  |  | psi
 |  |  | Total Available Pressure | -6.5 | psi
G. | Actual pipe length from building control valve to controlling fixture ft
 | Developed length. (Actual length, multiply by fitting/loss factor.) | fitting/loss factor | 1.5 | 0.0 | feet
 | Pressure available for uniform loss. (Total Available Pressure / Developed Length.) |  |  | #DIV/0! | psi/ft
 | Pressure available for uniform loss per 100 ft. (Multiply by 100 / 100.) |  |  | #DIV/0! | psi/100 ft
A. | Pressure available for uniform loss per 100 ft. (Value rounded up to next integer.) |  | “A” = | #DIV/0! | psi/100 ft

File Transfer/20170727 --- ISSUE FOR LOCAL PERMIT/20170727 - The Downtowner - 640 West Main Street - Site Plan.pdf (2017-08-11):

870' - 5" 9' - 5 1/4"²' - 3 1/4"

N 90° 00'00" W (96.39')

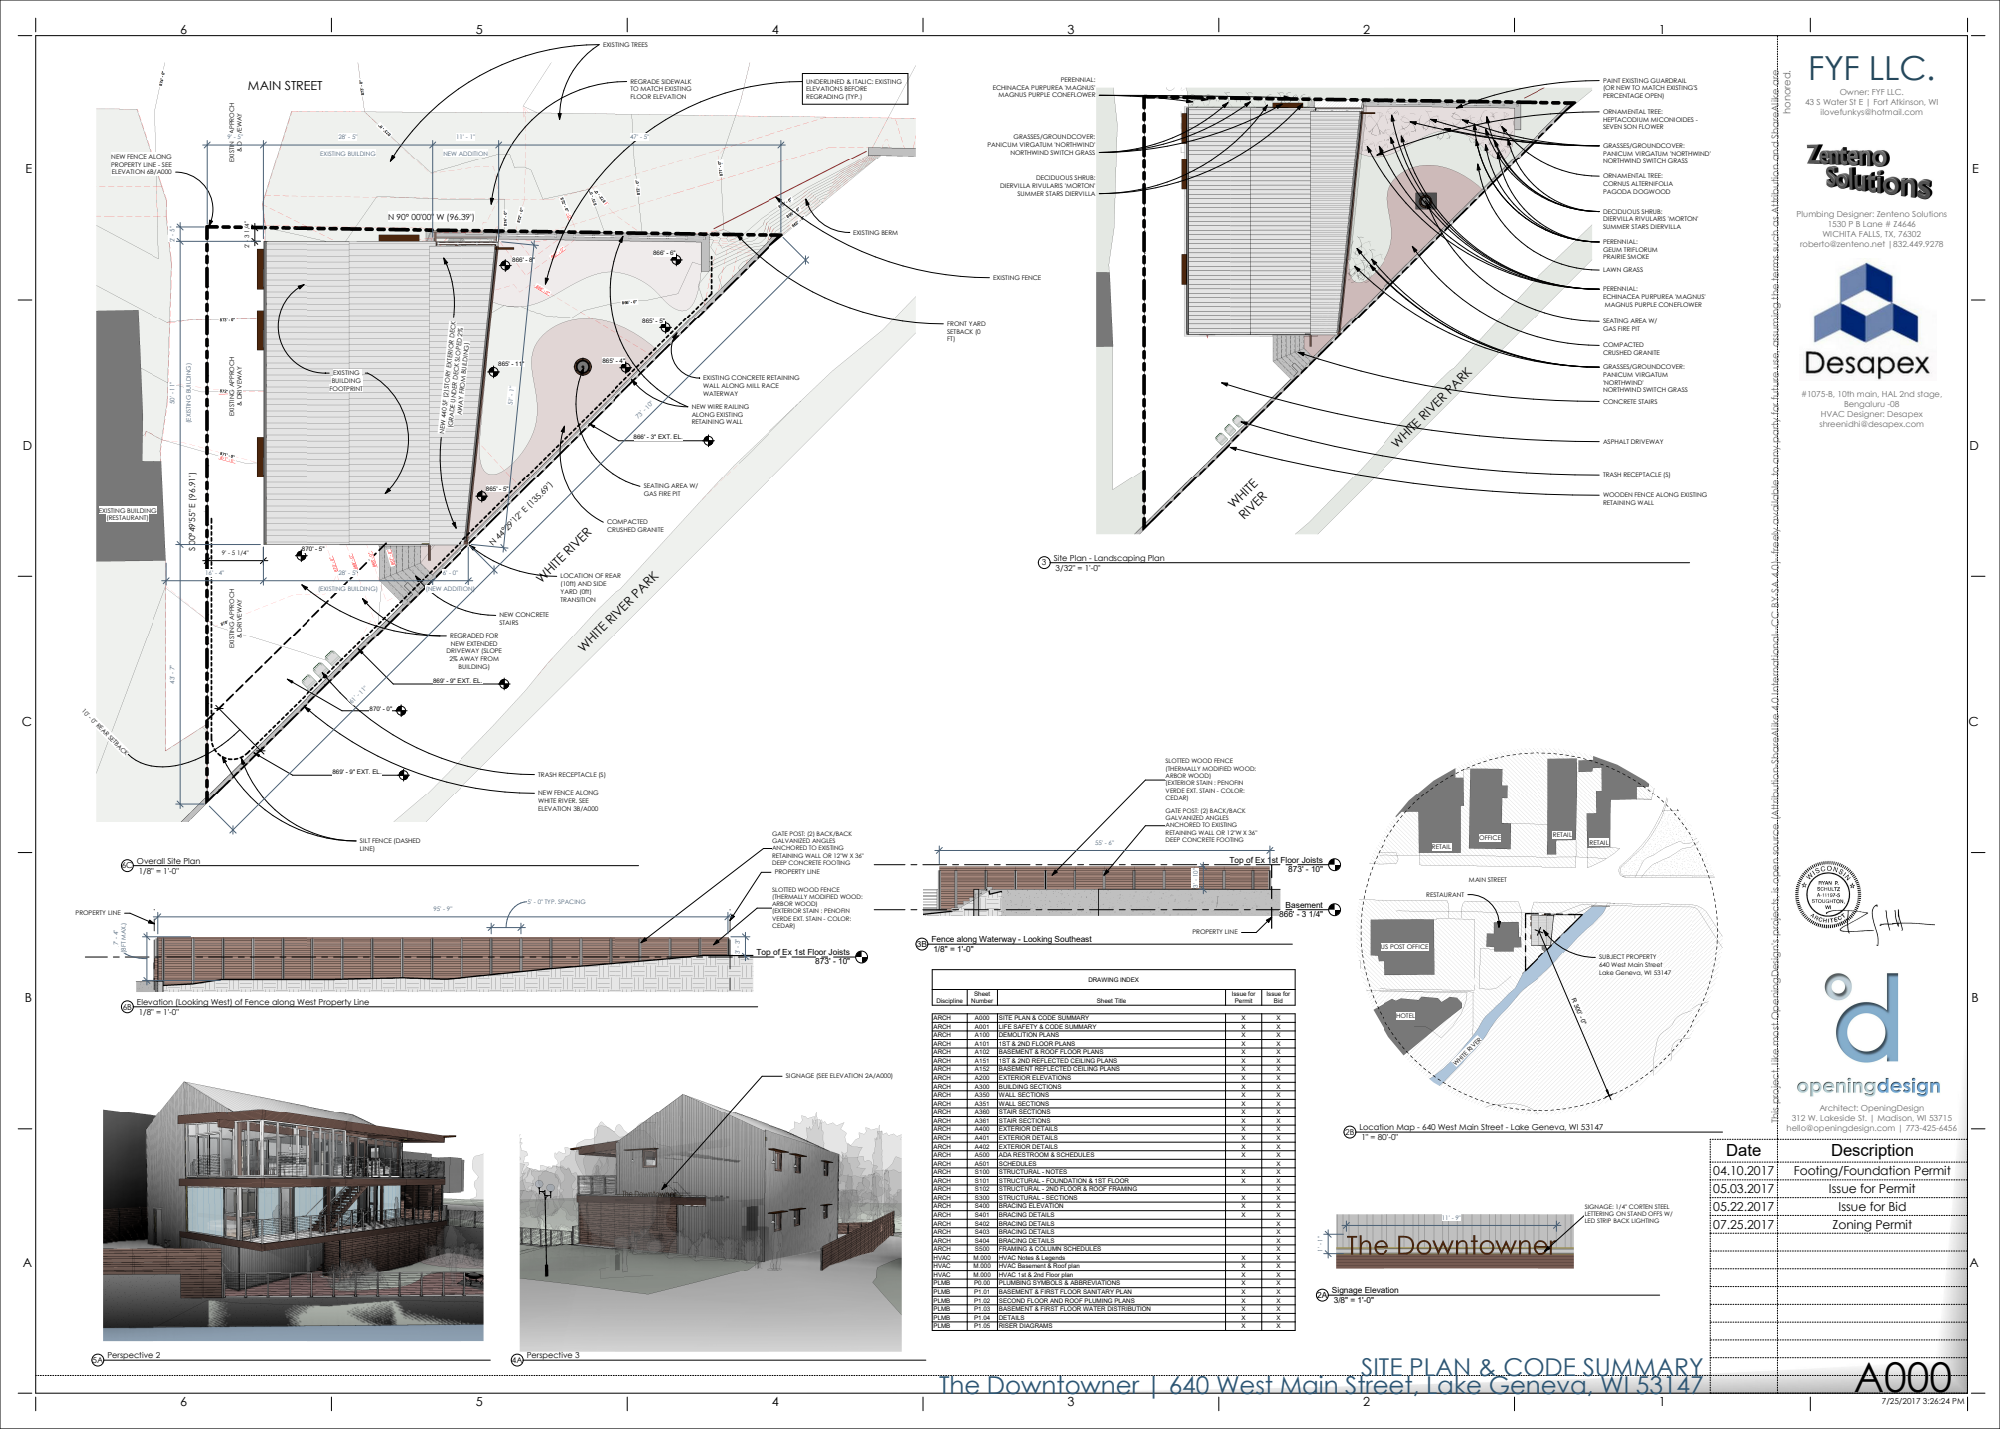
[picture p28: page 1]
869' - 9" EXT. EL.; 866' - 3" EXT. EL.; EXISTING BERM; 10' - 0" REAR SETBACK; EXISTING APPROCH; & DRIVEWAY; EXISTING TREES; TRASH RECEPTACLE (S); WHITE RIVER; MAIN STREET; NEW CONCRETE STAIRS; EXISTING FENCE; COMPACTED CRUSHED GRANITE; EXISTING BUILDING FOOTPRINT; SF (2) STO; EXTE; RIO; SLO; AWAY FR; UILDIN; FRONT YARD SETBACK (0 FT); EXISTING BUILDING (RESTAURANT); (EXISTING BUILDING); (NEW ADDITION); REGRADED FOR NEW EXTENDED DRIVEWAY (SLOPE 2% AWAY FROM BUILDING); EXISTING BUILDING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

This project, like most OpeningDesign's projects, is open source (Attribution-ShareAlike 4.0 International--CC BY-SA 4.0)--freely available to any party for future use, assuming the terms such as Attribution and ShareAlike are

REGRADE SIDEWALK
TO MATCH EXISTING
FLOOR ELEVATION

UNDERLINED & ITALIC: EXISTING
ELEVATIONS BEFORE
REGRADING (TYP.)

PAINT EXISTING GUARDRAIL
(OR NEW TO MATCH EXISTING'S
PERCENTAGE OPEN)

ECHINACEA PURPUREA 'MAGNUS'
MAGNUS PURPLE CONEFLOWER

Owner: FYF LLC.

43 S Water St E | Fort Atkinson, WI
ilovefunkys@hotmail.com

ORNAMENTAL TREE:
HEPTACODIUM MICONIOIDES -
SEVEN SON FLOWER

PANICUM VIRGATUM 'NORTHWIND'

GRASSES/GROUNDCOVER:
NORTHWIND SWITCH GRASS

NEW FENCE ALONG
PROPERTY LINE - SEE
ELEVATION 6B/A000

DIERVILLA RIVULARIS 'MORTON'
SUMMER STARS DIERVILLA

DECIDUOUS SHRUB:

Plumbing Designer: Zenteno Solutions

1530 P B Lane # Z4646
WICHITA FALLS, TX, 76302
roberto@zenteno.net |832.449.9278

PERENNIAL:

SEATING AREA W/
GAS FIRE PIT

WHITE RIVER PARK

PANICUM VIRGATUM
'NORTHWIND'
CONCRETE STAIRS

EXISTING CONCRETE RETAINING
WALL ALONG MILL RACE
WATERWAY

#1075-B, 10th main, HAL 2nd stage,

NEW WIRE RAILING
ALONG EXISTING
RETAINING WALL

Bengaluru -08
HVAC Designer: Desapex
shreenidhi@desapex.com

WOODEN FENCE ALONG EXISTING

LOCATION OF REAR
(10ft) AND SIDE
YARD (0ft)
TRANSITION

SLOTTED WOOD FENCE
(THERMALLY MODIFIED WOOD:
ARBOR WOOD)
(EXTERIOR STAIN : PENOFIN
VERDE EXT. STAIN - COLOR:
CEDAR)

WHITE RIVER. SEE
ELEVATION 3B/A000

GATE POST: (2) BACK/BACK
GALVANIZED ANGLES
ANCHORED TO EXISTING
RETAINING WALL OR 12"W X 36"
DEEP CONCRETE FOOTING

PROPERTY LINE

SILT FENCE (DASHED
LINE)

1/8" = 1'-0" 6C Overall Site Plan

Top of Ex 1st Floor Joists

Fence along Waterway - Looking Southeast

US POST OFFICE

SUBJECT PROPERTY
640 West Main Street
Lake Geneva, WI 53147

1/8" = 1'-0" 6B Elevation (Looking West) of Fence along West Property Line

ARCH | A000 | SITE PLAN & CODE SUMMARY | X | X
ARCH | A001 | LIFE SAFETY & CODE SUMMARY | X | X
ARCH | A100 | DEMOLITION PLANS | X | X
ARCH | A101 | 1ST & 2ND FLOOR PLANS | X | X
ARCH | A102 | BASEMENT & ROOF FLOOR PLANS | X | X
ARCH | A151 | 1ST & 2ND REFLECTED CEILING PLANS | X | X
ARCH | A152 | BASEMENT REFLECTED CEILING PLANS | X | X
ARCH | A200 | EXTERIOR ELEVATIONS | X | X
ARCH | A300 | BUILDING SECTIONS | X | X
ARCH | A350 | WALL SECTIONS | X | X
ARCH | A351 | WALL SECTIONS | X | X
ARCH | A360 | STAIR SECTIONS | X | X
ARCH | A361 | STAIR SECTIONS | X | X
ARCH | A400 | EXTERIOR DETAILS | X | X
ARCH | A401 | EXTERIOR DETAILS | X | X
ARCH | A402 | EXTERIOR DETAILS | X | X
ARCH | A500 | ADA RESTROOM & SCHEDULES | X | X
ARCH | A501 | SCHEDULES | | X
ARCH | S100 | STRUCTURAL - NOTES | X | X
ARCH | S101 | STRUCTURAL - FOUNDATION & 1ST FLOOR | X | X
ARCH | S102 | STRUCTURAL - 2ND FLOOR & ROOF FRAMING | | X
ARCH | S300 | STRUCTURAL - SECTIONS | X | X
ARCH | S400 | BRACING ELEVATION | X | X
ARCH | S401 | BRACING DETAILS | X | X
ARCH | S402 | BRACING DETAILS | | X
ARCH | S403 | BRACING DETAILS | | X
ARCH | S404 | BRACING DETAILS | | X
ARCH | S500 | FRAMING & COLUMN SCHEDULES | | X
HVAC | M.000 | HVAC Notes & Legends | X | X
HVAC | M.000 | HVAC Basement & Roof plan | X | X
HVAC | M.000 | HVAC 1st & 2nd Floor plan | X | X
PLMB | P0.00 | PLUMBING SYMBOLS & ABBREVIATIONS | X | X
PLMB | P1.01 | BASEMENT & FIRST FLOOR SANITARY PLAN | X | X
PLMB | P1.02 | SECOND FLOOR AND ROOF PLUMING PLANS | X | X
PLMB | P1.03 | BASEMENT & FIRST FLOOR WATER DISTRIBUTION | X | X
PLMB | P1.04 | DETAILS | X | X
PLMB | P1.05 | RISER DIAGRAMS | X | X

SIGNAGE (SEE ELEVATION 2A/A000)

312 W. Lakeside St. | Madison, WI 53715
hello@openingdesign.com | 773-425-6456

Location Map - 640 West Main Street - Lake Geneva, WI 53147

04.10.2017 Footing/Foundation Permit
05.03.2017 Issue for Permit
05.22.2017 Issue for Bid
07.25.2017 Zoning Permit

SIGNAGE: 1/4" CORTEN STEEL
LETTERING ON STAND OFFS W/
LED STRIP BACK LIGHTING

SITE PLAN & CODE SUMMARY

The Downtowner | 640 West Main Street, Lake Geneva, WI 53147

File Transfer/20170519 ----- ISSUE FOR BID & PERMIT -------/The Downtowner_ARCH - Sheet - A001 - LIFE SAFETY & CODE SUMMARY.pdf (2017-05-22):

5' - 5" 22' - 6" 13' - 1"

E

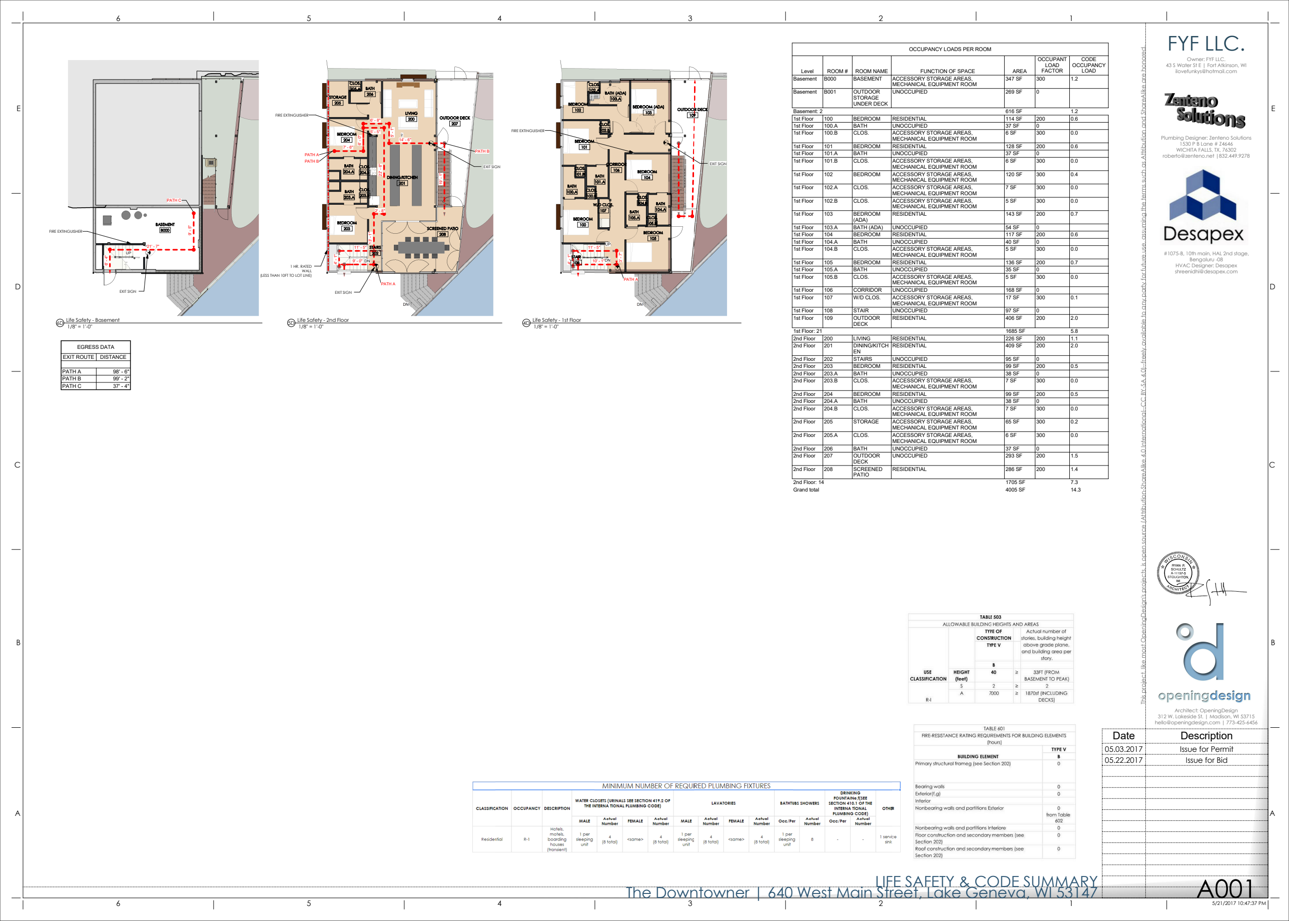
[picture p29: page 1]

7' - 6"

6' - 0"

2' - 8"

9' - 0"

4' - 1"

11' - 5"

PATH B

PATH A

PATH B

PATH A

6' - 8"

5' - 1"

14' - 6"

19' - 1"

BEDROOM
204

STORAGE
205

CLOS.
205.A

BATH
204.A

BATH
203.A

BEDROOM
203

CLOS.
203.B

CLOS.
204.B

SCREENED PATIO
208

LIVING
200

BATH
206

DINING/KITCHEN
201

STAIRS
202

OUTDOOR DECK
207

EXIT SIGN

EXIT SIGN

?

FIRE EXTINGUISHER

### 1 HR. RATED

WALL
(LESS THAN 10FT TO LOT LINE)

11' - 5"

10' - 1"

4' - 1"

3' - 7"

PATH A

BEDROOM
105

BEDROOM
100

BATH
100.A

BATH
101.A

BEDROOM
101

BEDROOM
102

BATH (ADA)
103.A

BEDROOM (ADA)
103

CORRIDOR
106 BEDROOM

104

BATH
104.A
BATH
105.A

CLOS.
102.A

CLOS.
102.B

W/D CLOS.
107

CLOS.
101.B

CLOS.
100.B | CLOS.
| 104.B

CLOS.
105.B

STAIR
108

OUTDOOR DECK
109

EXIT SIGN

FIRE EXTINGUISHER

9' - 5"

21' - 7"

6' - 4"

PATH C

EXIT SIGN

FIRE EXTINGUISHER

BASEMENT
B000

Architect: OpeningDesign
312 W. Lakeside St. | Madison, WI 53715
hello@openingdesign.com | 773-425-6456

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
5 | 4 | 3 | 2 | 1
6 | 5 | 4 | 3 | 2 | 1

Owner: FYF LLC.

### 43 S Water St E | Fort Atkinson, WI

ilovefunkys@hotmail.com

FYF LLC.

Plumbing Designer: Zenteno Solutions 1530 P B Lane # Z4646
WICHITA FALLS, TX, 76302
roberto@zenteno.net |832.449.9278

#1075-B, 10th main, HAL 2nd stage, Bengaluru -08

HVAC Designer: Desapex
shreenidhi@desapex.com

This project, like most OpeningDesign's projects, is open source (Attribution-ShareAlike 4.0 International--CC BY-SA 4.0)--freely available to any party for future use, assuming the terms such as Attribution and ShareAlike are honored.

A001

5/21/2017 10:47:37 PM

# LIFE SAFETY & CODE SUMMARY The Downtowner | 640 West Main Street, Lake Geneva, WI 53147

EGRESS DATA

EXIT ROUTE | DISTANCE
PATH A | 98' - 6"
PATH B | 99' - 2"
PATH C | 37' - 4"

1/8" = 1'-0" 5D Life Safety - 2nd Floor 1/8" = 1'-0"

4D

Life Safety - 1st Floor

OCCUPANCY LOADS PER ROOM

Level | ROOM # | ROOM NAME | FUNCTION OF SPACE | AREA | OCCUPANT LOAD FACTOR | CODE OCCUPANCY LOAD
Basement | B000 | BASEMENT | ACCESSORY STORAGE AREAS, MECHANICAL EQUIPMENT ROOM | 347 SF | 300 | 1.2
Basement | B001 | OUTDOOR
STORAGE
UNDER DECK
UNOCCUPIED | 269 SF | 0
Basement: 2 | 616 SF | 1.2
1st Floor | 100 | BEDROOM | RESIDENTIAL | 114 SF | 200 | 0.6
1st Floor | 100.A | BATH | UNOCCUPIED | 37 SF | 0
1st Floor | 100.B | CLOS. | ACCESSORY STORAGE AREAS, MECHANICAL EQUIPMENT ROOM | 6 SF | 300 | 0.0
1st Floor | 101 | BEDROOM | RESIDENTIAL | 128 SF | 200 | 0.6
1st Floor | 101.A | BATH | UNOCCUPIED | 37 SF | 0
1st Floor | 101.B | CLOS. | ACCESSORY STORAGE AREAS, MECHANICAL EQUIPMENT ROOM | 6 SF | 300 | 0.0
1st Floor | 102 | BEDROOM | ACCESSORY STORAGE AREAS, MECHANICAL EQUIPMENT ROOM
120 SF | 300 | 0.4
1st Floor | 102.A | CLOS. | ACCESSORY STORAGE AREAS, MECHANICAL EQUIPMENT ROOM | 7 SF | 300 | 0.0
1st Floor | 102.B | CLOS. | ACCESSORY STORAGE AREAS, MECHANICAL EQUIPMENT ROOM | 5 SF | 300 | 0.0
1st Floor | 103 | BEDROOM (ADA) | RESIDENTIAL | 143 SF | 200 | 0.7
1st Floor | 103.A | BATH (ADA) | UNOCCUPIED | 54 SF | 0
1st Floor | 104 | BEDROOM | RESIDENTIAL | 117 SF | 200 | 0.6
1st Floor | 104.A | BATH | UNOCCUPIED | 40 SF | 0
1st Floor | 104.B | CLOS. | ACCESSORY STORAGE AREAS, MECHANICAL EQUIPMENT ROOM | 5 SF | 300 | 0.0
1st Floor | 105 | BEDROOM | RESIDENTIAL | 136 SF | 200 | 0.7
1st Floor | 105.A | BATH | UNOCCUPIED | 35 SF | 0
1st Floor | 105.B | CLOS. | ACCESSORY STORAGE AREAS, MECHANICAL EQUIPMENT ROOM | 5 SF | 300 | 0.0
1st Floor | 106 | CORRIDOR | UNOCCUPIED | 168 SF | 0
1st Floor | 107 | W/D CLOS. | ACCESSORY STORAGE AREAS, MECHANICAL EQUIPMENT ROOM | 17 SF | 300 | 0.1
1st Floor | 108 | STAIR | UNOCCUPIED | 97 SF | 0
1st Floor | 109 | OUTDOOR DECK | RESIDENTIAL | 406 SF | 200 | 2.0
1st Floor: 21 | 1685 SF | 5.8
2nd Floor | 200 | LIVING | RESIDENTIAL | 226 SF | 200 | 1.1
2nd Floor | 201 | DINING/KITCH EN | RESIDENTIAL | 409 SF | 200 | 2.0
2nd Floor | 202 | STAIRS | UNOCCUPIED | 95 SF | 0
2nd Floor | 203 | BEDROOM | RESIDENTIAL | 99 SF | 200 | 0.5
2nd Floor | 203.A | BATH | UNOCCUPIED | 38 SF | 0
2nd Floor | 203.B | CLOS. | ACCESSORY STORAGE AREAS, MECHANICAL EQUIPMENT ROOM | 7 SF | 300 | 0.0
2nd Floor | 204 | BEDROOM | RESIDENTIAL | 99 SF | 200 | 0.5
2nd Floor | 204.A | BATH | UNOCCUPIED | 38 SF | 0
2nd Floor | 204.B | CLOS. | ACCESSORY STORAGE AREAS, MECHANICAL EQUIPMENT ROOM | 7 SF | 300 | 0.0
2nd Floor | 205 | STORAGE | ACCESSORY STORAGE AREAS, MECHANICAL EQUIPMENT ROOM | 65 SF | 300 | 0.2
2nd Floor | 205.A | CLOS. | ACCESSORY STORAGE AREAS, MECHANICAL EQUIPMENT ROOM | 6 SF | 300 | 0.0
2nd Floor | 206 | BATH | UNOCCUPIED | 37 SF | 0
2nd Floor | 207 | OUTDOOR DECK | UNOCCUPIED | 293 SF | 200 | 1.5
2nd Floor | 208 | SCREENED PATIO | RESIDENTIAL | 286 SF | 200 | 1.4
2nd Floor: 14 | 1705 SF | 7.3
Grand total | 4005 SF | 14.3

1/8" = 1'-0" 6D Life Safety - Basement

Date | Description

## 05.03.2017 Issue for Permit 05.22.2017 Issue for Bid

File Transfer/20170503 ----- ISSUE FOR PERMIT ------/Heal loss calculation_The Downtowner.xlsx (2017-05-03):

Level | Space name | Area (sq.ft ) | Volume ( cu.ft) | Occupancy | Exposed Wall |  | window |  | Partition wall |  | Floor |  | Roof exposed |  | Heat loss by wall | Heat loss by window | Heat loss by partition wall | Heat loss by Roof | Heat loss by Floor | Total Envelop Load | Infiltration @ 0.035 cfm/sft | Heat loss by Infiltration |  |  | Safety | Total Room SH with safety | Total room LH with safety | Room Total load | Design Air Quantity | Ventilation 7.5cfm/person | Heat loss by Ventilation |  |  | Total Sensible Load | Total Latent Load | Total Heat loss
 |  |  |  | Nos | Net Area (sq ft ) | U (Btu/h °F ft2) | Area (sq ft ) | U (Btu/h °F ft2) | Area (sq ft ) | U (Btu/h °F ft2) | Area (sq ft ) | U (Btu/h °F ft2) | Area (sq ft ) | U (Btu/h °F ft2) | Btu/Hr | Btu/Hr | Btu/Hr | Btu/Hr | Btu/Hr | Btu/Hr | CFm | SH Btu/Hr | LH Btu/Hr | TH Btu/Hr |  | Btu/Hr | Btu/Hr | Btu/Hr | CFM | CFM | SH Btu/Hr | LH Btu/Hr | TH Btu/Hr | Btu/Hr | Btu/Hr | Btu/Hr
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

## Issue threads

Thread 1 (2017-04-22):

Gas line to fireplace

theoryshaw, 2017-04-22:
Hi @rvzenteno Can you add a gas line out to the outdoor fireplace?

Thanks.

rvzenteno, 2017-04-29:
Hey @theoryshaw.

Gas was not part of my estimate but I can incorporate it.

Where is the Gas line coming into the building?
What are the BTU requirements of the Kitchen and Furnace?
Also the Grill BTU

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

theoryshaw, 2017-04-29:
@shree6984 Do you know the BTU requirements for the furnace?

I'm going to the site today.  Will locate/size the gas line.

Will get you the BTUs requirements for the others tomorrow.

Thanks, Ryan

shree6984, 2017-04-30:
@theoryshaw @rvzenteno  We need 80,000 BTU/hr capacity. For ref pls take a look at
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

theoryshaw, 2017-04-30:
- BTUs
  - Range: 50k - 60k BTU
  - Firepit: 60k - 80k BTU

Gas line location...

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

rvzenteno, 2017-04-30:
The 80k btu is only for the Furnace? what about the Kitchen, and the BBQ Grill outside?

I currently have 152 CFH between the 80K BTU you sent me, and the Water heater will take about 72K BTU.

theoryshaw, 2017-04-30:
looks great. Thanks.

Closed 2017-04-30.

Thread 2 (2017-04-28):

Radiant Heaters at 2nd floor storefront

theoryshaw, 2017-04-28:
Hi @rvzenteno, in order to counteract cold drafts along the large expanses of glass on the east side of the 2nd floor, we'd like to locate radiant heaters along the base of these windows.

Are these units we can connect to the water heater, or do they have to have a separated dedicated mini boiler?

If they can be connected to the water heater, I wanted to let you know, just so you can size the water heater appropriately.

@shree6984, @ Let me know if you'd like to add anything.

Cheers, Ryan

rvzenteno, 2017-04-28:
Hi @theoryshaw , I have not done anything with radiant heat before and I would not know how to size the water heater for it, that typically is handled by the HVAC contractor/engineer. Researching a bit on this they will need to have a dedicated Hydronic Heating Boiler.  Thanks.

theoryshaw, 2017-04-28:
Thanks Roberto.

@shree6984 is this something you guys can handle? or should I ping someone in to help?

Thanks, Ryan

shree6984, 2017-04-29:
@rvzenteno Could you please tell what will be outlet water temp for planned domestic water heater . @theoryshaw We are planning to use same water heater for radiator some like this, Please take a look at it https://www.youtube.com/watch?v=50ufVwINeyk

rvzenteno, 2017-04-29:
The outlet temperature is typically set at 120 F, some places like it hotter like 140 F. But, so people don't get scalded I typically show it at 120 F.

rvzenteno, 2017-04-29:
@theoryshaw Do they allow PEX piping in WI? Let me know. Otherwise I'll just remove any notes that I have in reference to PEX Piping.

Thanks,

Roberto,

theoryshaw, 2017-04-29:
FYI, i was only thinking of isolated baseboard radiator like this at the foot of the 2nd floor storefront: http://www.theradiatorfactory.com/en/radiators/micro-canal

...**not** radiant tubing in the floor.

rvzenteno, 2017-04-29:
@theoryshaw, I see. The PEX I was asking was for Fixtures though.

theoryshaw, 2017-04-29:
oh.  I believe they do.
https://docs.legis.wisconsin.gov/search/results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

But please verify.

If you can, please start a new github issue for different topics. Just to avoid potential confusion. Thanks!

shree6984, 2017-04-29:
@theoryshaw How abt electrical heater ??? Is it too costly ??

shree6984, 2017-04-29:
@rvzenteno If you can provide outlet water temp from water heater I will provide hot water capacity required from water heater

rvzenteno, 2017-04-29:
I was calculating the load for the Water heater and the correct temperature. The Tank Capacity for all the bathrooms, kitchen, Cloth Water, Service sink, and we'll need a 100 Gallon Water heater tank. The temperature will need to be at 140 F. I have to retract my previews comment on the temperature of 120 F.

theoryshaw, 2017-04-29:
Yes, good call. Let's go with electric. Thx.

Closed 2017-04-30.

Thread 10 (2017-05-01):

reroute basement duct...

theoryshaw, 2017-05-01:
Can we reroute ductwork similar to this?  Want to make sure we put registers at glazing...
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

shree6984, 2017-05-01:
Same issue of condensation during cooling mode. Should avoid throwing air on glazing

theoryshaw, 2017-05-01:
At this location, they wouldn't be pointed at the glazing...

conceptually was thinking it would just do this...

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

shree6984, 2017-05-02:
Yes done..

Closed 2017-05-02.

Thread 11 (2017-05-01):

pull main supply down?

theoryshaw, 2017-05-01:
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

shree6984, 2017-05-02:
The actual height of the duct will be decided by the furnace & evaporator coil.

theoryshaw, 2017-05-02:
can you provide a suggested spec for the furnace & coil?

shree6984, 2017-05-02:
Yes .. will provide with pdf set today

shree6984, 2017-05-02:
If any issues then we can try placing furnace horizontal

theoryshaw, 2017-05-02:
With the low head heights, it looks like a horizontal one, would be better. Defer to you.

shree6984, 2017-05-03:
Yes I agree.. We will reduce duct size and submit for permit. Once equipment is finalized or contractor on board we can change orientation & update in construction drawings

shree6984, 2017-05-03:
Solved

Closed 2017-05-03.

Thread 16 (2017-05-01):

Water Supply

theoryshaw, 2017-05-01:
@rvzenteno The existing main water supply pipe is 1".

I see you're looking for a 2"

If we can't change this to a 2", would we need a pressure tank?

Thanks, Ryan

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

apbock, 2017-05-02:
The answer to this would depend on Roberto's water calculations and the existing water pressure.

theoryshaw, 2017-05-02:
Sounds good. I will ask GC to get a plumber to test existing water pressure.

For permit, let just assume there's a 2" line (or whatever is needed) there, if that's what's necessary.

rvzenteno, 2017-05-02:
I'll take a look at this after work.

rvzenteno, 2017-05-02:
Sorry, I pressed the wrong button.

rvzenteno, 2017-05-03:
I updated the loads and it turns out to be a 1-1/2". I was able to import the Water calculation Worksheet Aaron sent me. Now, This is something new to me. If Aaron can help me filling it out I would appreciate it very much. I'll post the Excel file to the Project Github.

apbock, 2017-05-03:
Roberto, you can post the file or email it to me. The only needed piece of information we don't have is the incoming water pressure; the rest can be determined by what you have modeled. I can fill in what's known and explain how I did it.
If we don't immediately have the water pressure, we could consider omitting the calcs on the sheet altogether but the reviewer will likely flag this. Either that or we make an assumption on pressure and verify it later in the field. Either way, if there were working fixtures on the top floor prior to the remodel, the new ones will almost certainly work as well.
Thanks.
Aaron

Sent from my U.S. Cellular® Smartphone

-------- Original message --------
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

theoryshaw, 2017-05-03:
Good call, at this point, let's just assume an existing water pressure that works.

We'll verify later.

Thanks.

rvzenteno, 2017-05-03:
Aaron, The files are posted. If you do fill the Excel file send it to me and I"ll convert it to import it to the Revit Model.

Thanks,

apbock, 2017-05-03:
Can you tell me where this is located or otherwise email me the file? I can't find it.

rvzenteno, 2017-05-03:
It is in the same folder as the PDF I created and posted on the PERMIT
FOLDER.

On May 3, 2017 at 1:51 PM, <apbock <notifications@github.com>> wrote:

Can you tell me where this is located or otherwise email me the file? I
can't find it.

—
You are receiving this because you modified the open/close state.
Reply to this email directly, view it on GitHub
<https://github.com/OpeningDesign/Vacation_Rental/issues/16#issuecomment-298985871>,
or mute the thread
<https://github.com/notifications/unsubscribe-auth/AAkqKQ4GZsuQ4O4CEtMOMK8J_SboVV8vks5r2L69gaJpZM4NNUYw>
.

theoryshaw, 2017-05-03:
Hi Aaron...
https://github.com/OpeningDesign/Vacation_Rental/tree/master/Transfer/20170503%20-----%20ISSUE%20FOR%20PERMIT%20------

apbock, 2017-05-03:
I've filled out the calculation worksheet and posted it back to that folder. I calculated a demand of 33 gpm maximum based on WI code fixture units and used that in the worksheet. I assumed 35 psi at the building entrance and used pipe lengths and building elevations to get the rest.

theoryshaw, 2017-05-15:
Hi Guys, The existing water pressure is 85psi, and the existing pipe is 1".

Please let me know if that affects anything, one way or the other.

Thanks, Ryan

theoryshaw, 2017-05-18:
Hi @rvzenteno Can you let me know if this new info affects anything?

thanks.

rvzenteno, 2017-05-18:
Hey Ryan, sorry for not replying sooner. Typically we would want no more
that 45 PSI. I would typically add a PRV to reduce the pressure into the
building. But because we need to have the 1 1/2" pipe the tank that you
mentioned will probably be needed. As an alternative  an expantion tank
could serve the same purpose to handle the pressure and add to the load
requirement. I think this would be the same as the holding tank you
mentioned before.

Thanks.

On May 18, 2017 at 1:08 PM, <Ryan Schultz <notifications@github.com>>
wrote:

Hi @rvzenteno <https://github.com/rvzenteno> Can you let me know if this
new info affects anything?

thanks.

—
You are receiving this because you were mentioned.
Reply to this email directly, view it on GitHub
<https://github.com/OpeningDesign/Vacation_Rental/issues/16#issuecomment-302475709>,
or mute the thread
<https://github.com/notifications/unsubscribe-auth/AAkqKeE8GQToPVz71k-Qmyr6-_zIWvJKks5r7HsBgaJpZM4NNUYw>
.

theoryshaw, 2017-05-19:
Thanks Roberto.  @apbock would you concur?

apbock, 2017-05-19:
I have no issue with 45 psi.
Just so I'm clear, what is the expansion/holding tank for? I typically only see these on water heaters and pumped systems.
Thanks.
Aaron

Sent from my U.S. Cellular® Smartphone

-------- Original message --------
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

Closed 2017-08-14.

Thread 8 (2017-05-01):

Consolidate vents..

theoryshaw, 2017-05-01:
- Can we consoledate these vents to one?  Or at least the 2nd floor restrooms?
- Also, possible to put the fan in the side of the wall as indicated here?

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

shree6984, 2017-05-02:
done

Closed 2017-05-02.

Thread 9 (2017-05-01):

vent in directly from spiral - no flex duct.

theoryshaw, 2017-05-01:
Can we supply these rooms directly off the main branch? That is, no flex duct..

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

shree6984, 2017-05-02:
Done

Closed 2017-05-02.

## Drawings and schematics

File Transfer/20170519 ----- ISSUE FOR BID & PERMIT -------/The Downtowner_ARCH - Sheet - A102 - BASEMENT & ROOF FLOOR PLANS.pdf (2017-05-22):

B

C.3 E

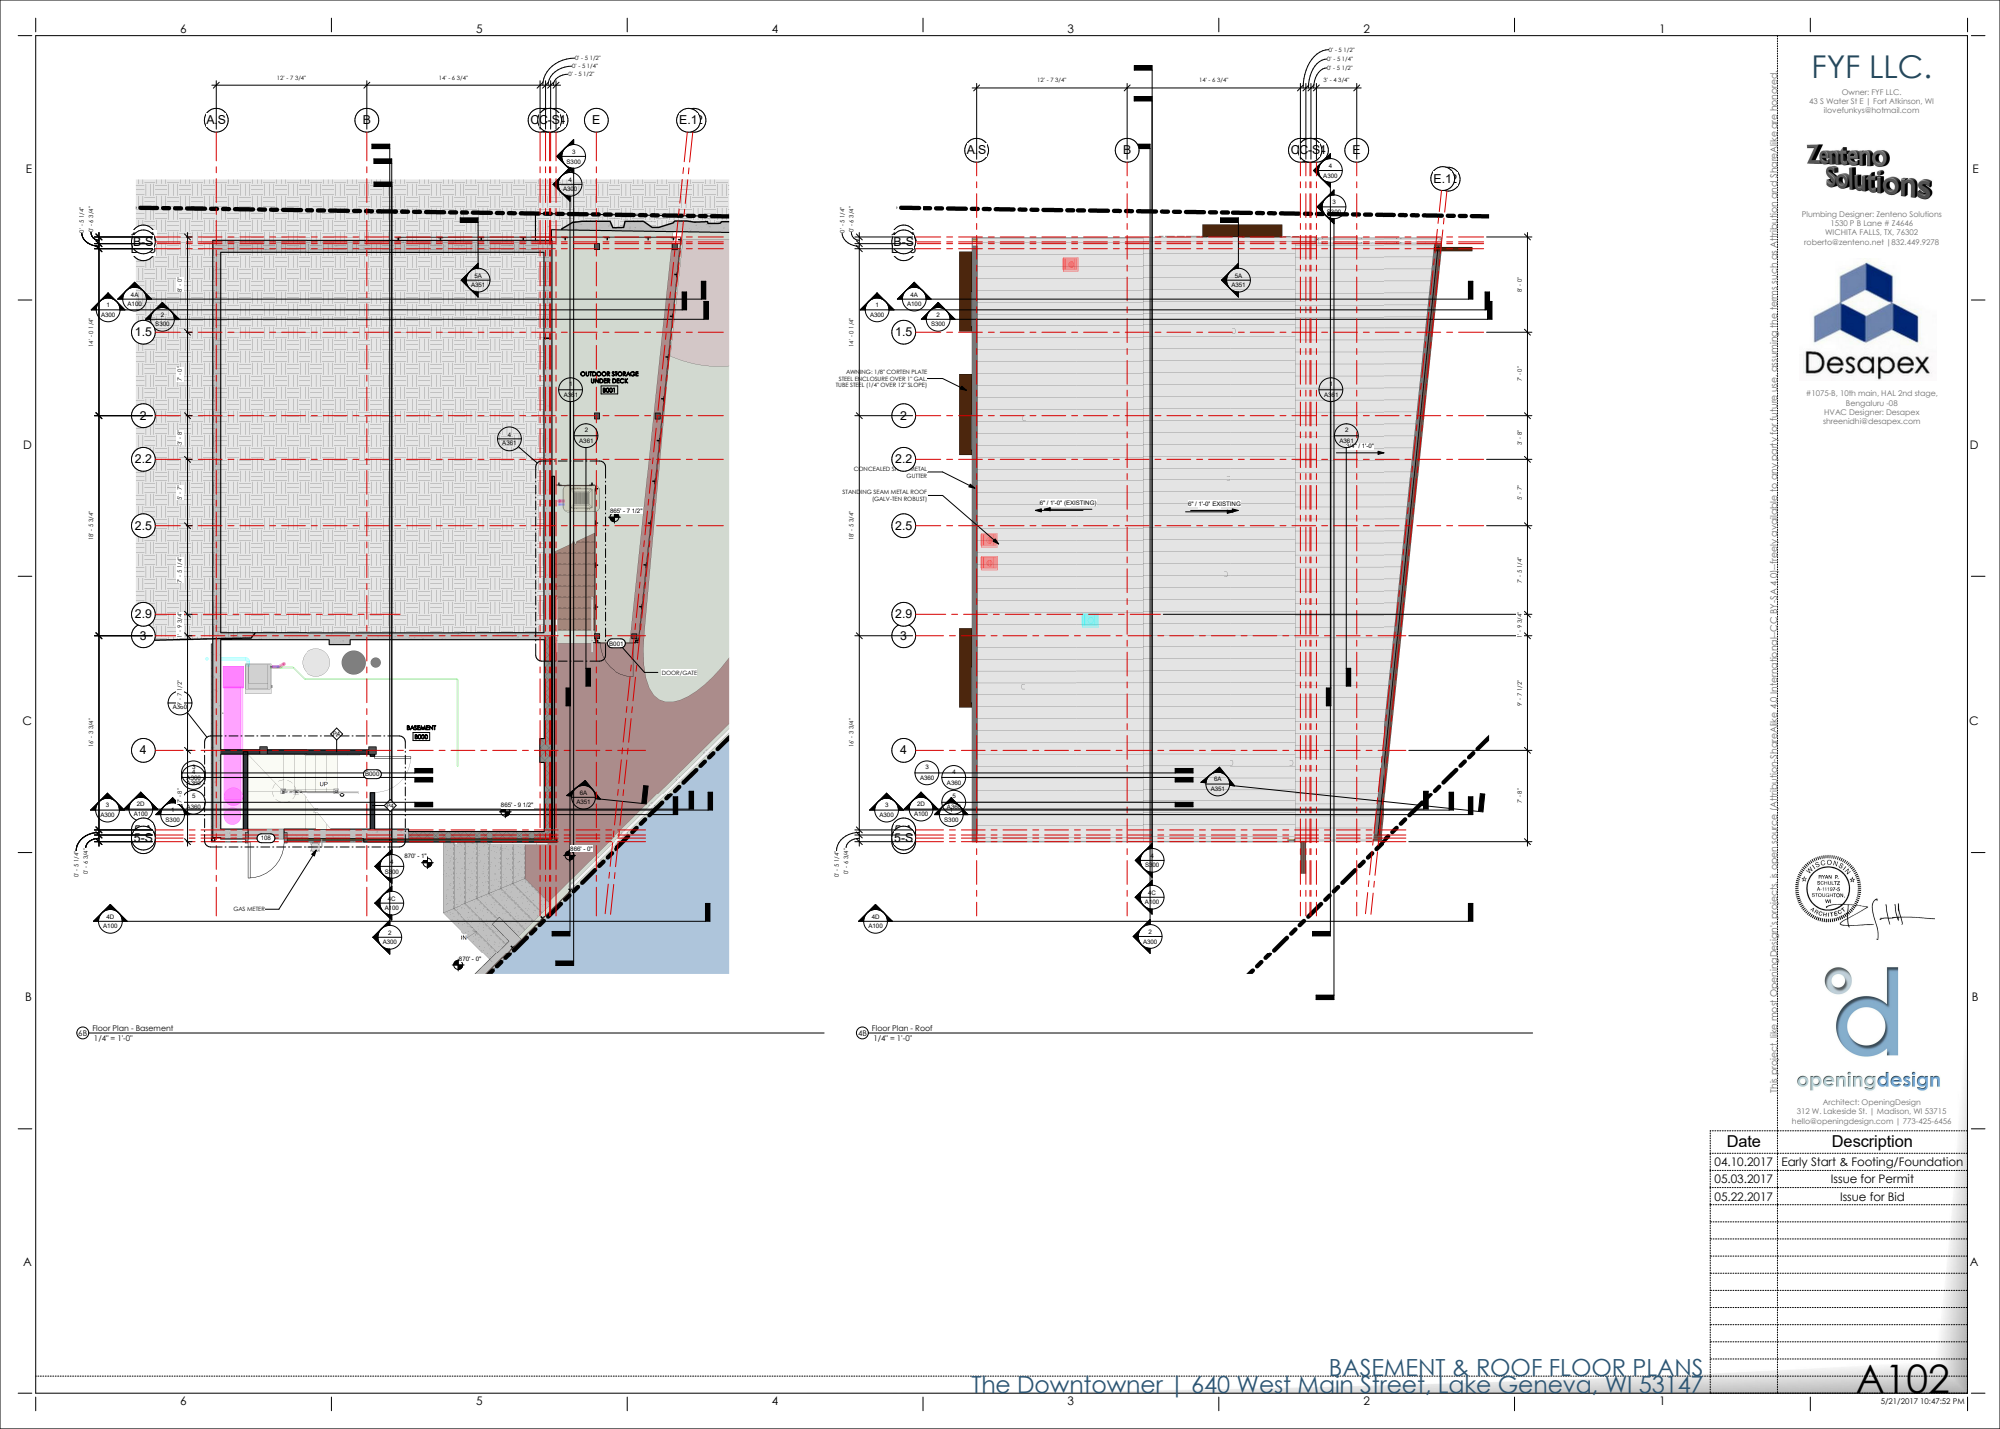
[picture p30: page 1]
BASEMENT; OUTDOOR STORAGE UNDER DECK; GAS METER; DOOR/GATE; 6" / 1'-0" (EXISTING); 6" / 1'-0" EXISTING; GUTTER; Architect: OpeningDesign; FYF LLC.; Floor Plan - Roof; Date; Description

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

Owner: FYF LLC.

43 S Water St E | Fort Atkinson, WI
ilovefunkys@hotmail.com

Plumbing Designer: Zenteno Solutions

1530 P B Lane # Z4646
WICHITA FALLS, TX, 76302
roberto@zenteno.net |832.449.9278

AWNING: 1/8" CORTEN PLATE
STEEL ENCLOSURE OVER 1" GAL.
TUBE STEEL (1/4" OVER 12" SLOPE)

#1075-B, 10th main, HAL 2nd stage,

Bengaluru -08
HVAC Designer: Desapex
shreenidhi@desapex.com

CONCEALED SHEET METAL

STANDING SEAM METAL ROOF

(GALV-TEN ROBUST)

1/4" = 1'-0" 6B Floor Plan - Basement

312 W. Lakeside St. | Madison, WI 53715
hello@openingdesign.com | 773-425-6456

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

BASEMENT & ROOF FLOOR PLANS

The Downtowner | 640 West Main Street, Lake Geneva, WI 53147

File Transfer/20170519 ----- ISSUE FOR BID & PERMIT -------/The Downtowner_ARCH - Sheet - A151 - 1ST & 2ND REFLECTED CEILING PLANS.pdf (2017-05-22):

B

C.3 E

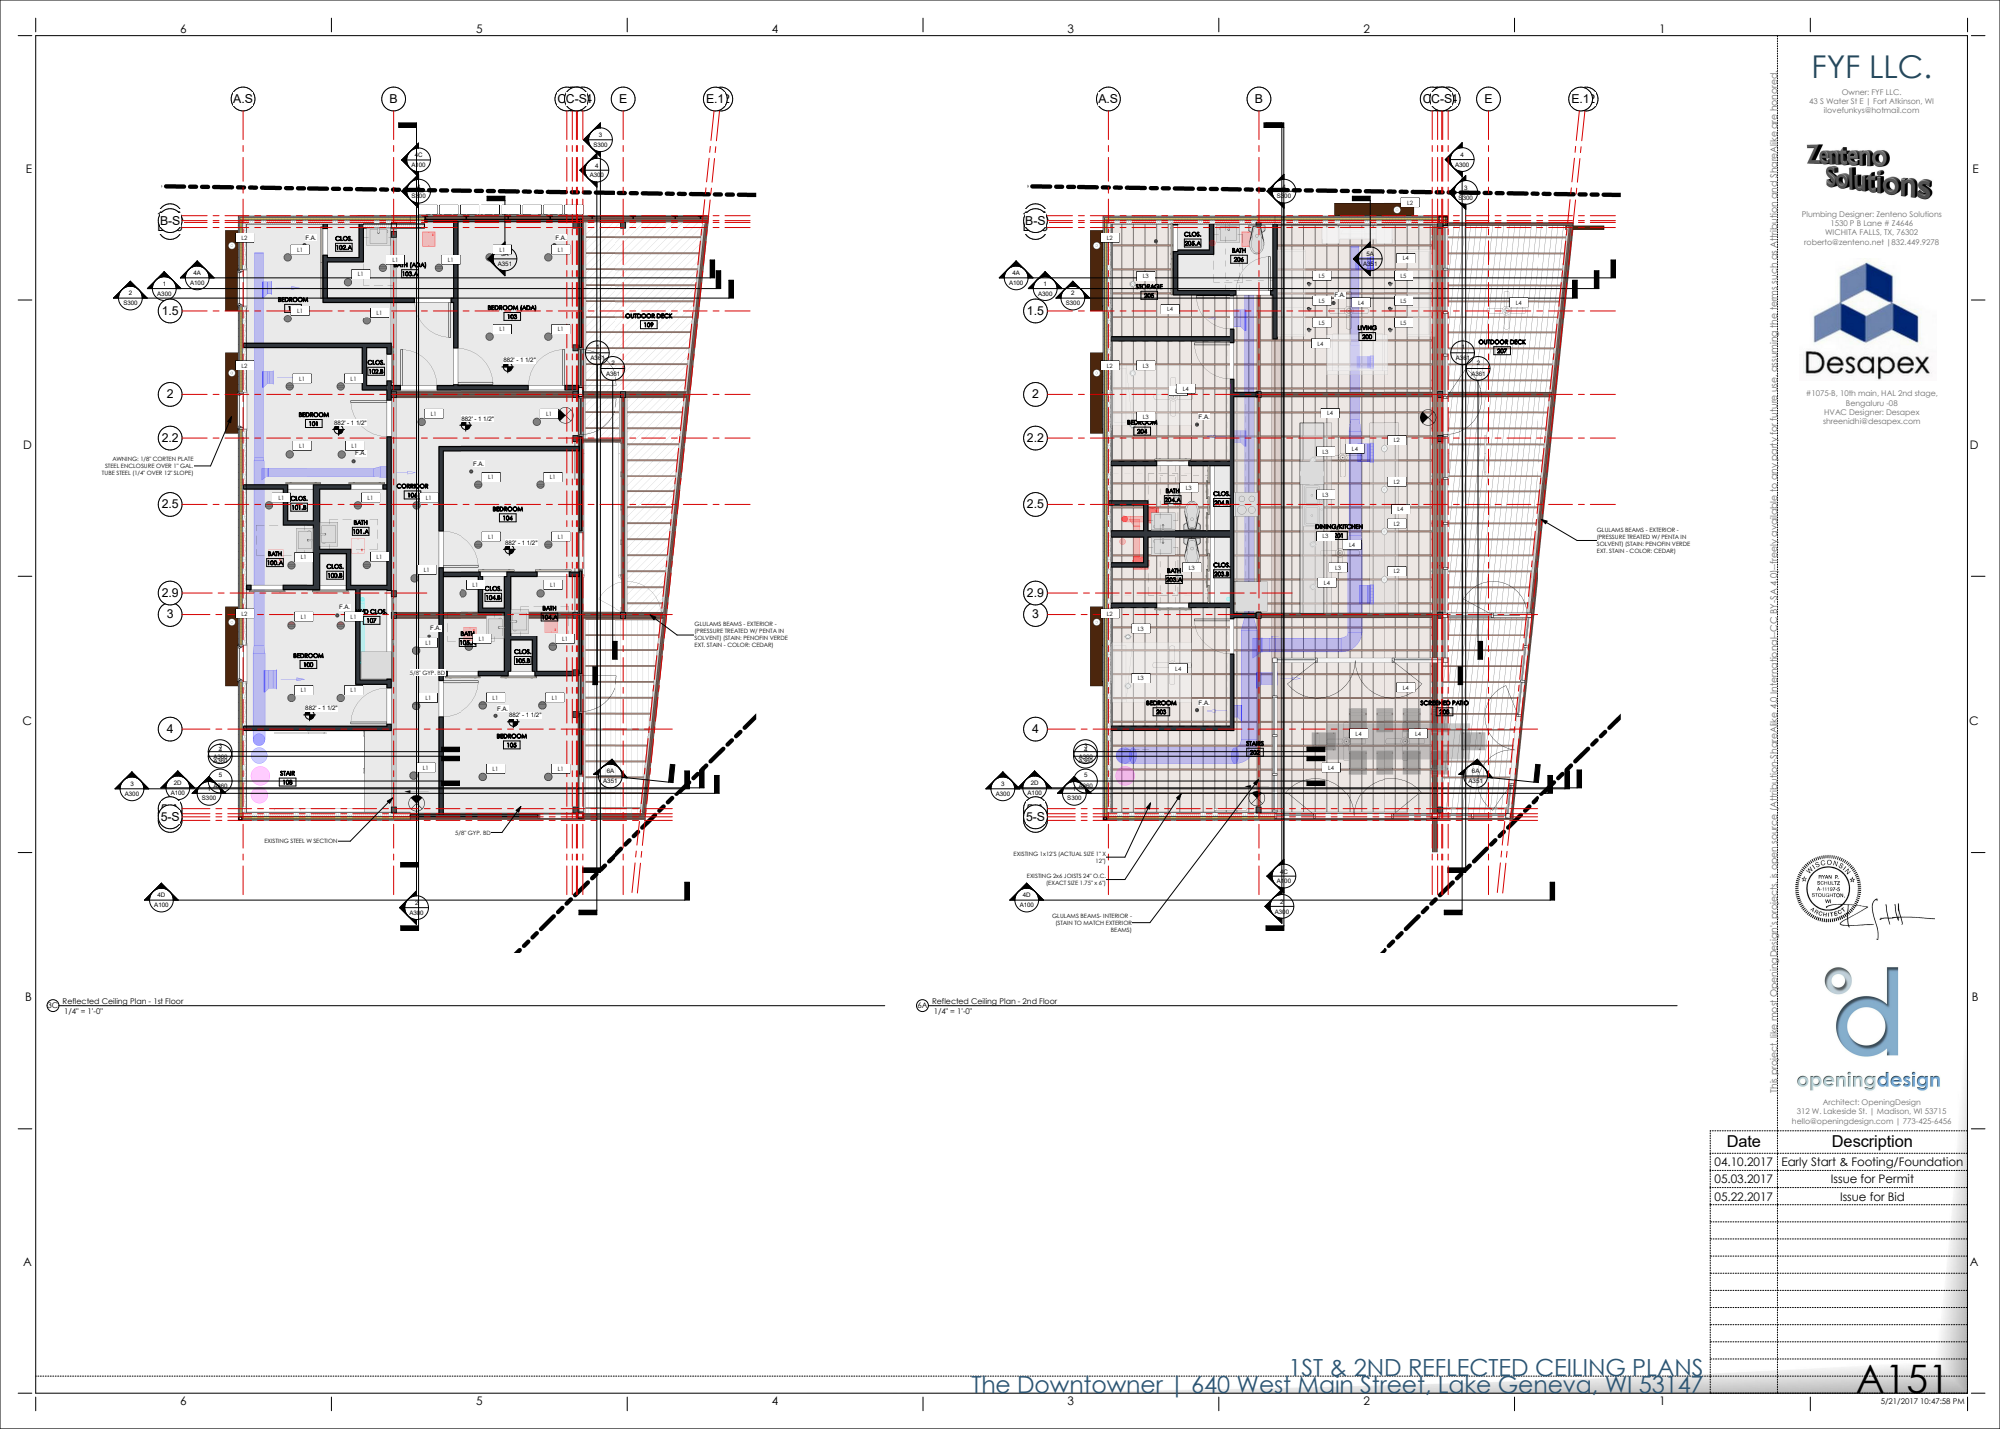
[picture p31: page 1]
BEDROOM; BATH; BATH (ADA); BEDROOM (ADA); CORRIDOR; CLOS.; W/D CLOS.; STAIR; OUTDOOR DECK; 5/8" GYP. BD; STORAGE; SCREENED PATIO; LIVING; DINING/KITCHEN; STAIRS; EXISTING 2x6 JOISTS 24" O.C. (EXACT SIZE 1.75" x 6"); BEAMS); Architect: OpeningDesign; FYF LLC.; Reflected Ceiling Plan - 2nd Floor; Date; Description

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

Owner: FYF LLC.

43 S Water St E | Fort Atkinson, WI
ilovefunkys@hotmail.com

Plumbing Designer: Zenteno Solutions

1530 P B Lane # Z4646
WICHITA FALLS, TX, 76302
roberto@zenteno.net |832.449.9278

#1075-B, 10th main, HAL 2nd stage,

Bengaluru -08
HVAC Designer: Desapex
shreenidhi@desapex.com

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

GLULAMS BEAMS - EXTERIOR -
(PRESSURE TREATED W/ PENTA IN
SOLVENT) (STAIN: PENOFIN VERDE
EXT. STAIN - COLOR: CEDAR)

EXISTING STEEL W SECTION

EXISTING 1x12'S (ACTUAL SIZE 1" X

GLULAMS BEAMS- INTERIOR -
(STAIN TO MATCH EXTERIOR

1/4" = 1'-0" 3C Reflected Ceiling Plan - 1st Floor

312 W. Lakeside St. | Madison, WI 53715
hello@openingdesign.com | 773-425-6456

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

1ST & 2ND REFLECTED CEILING PLANS

The Downtowner | 640 West Main Street, Lake Geneva, WI 53147

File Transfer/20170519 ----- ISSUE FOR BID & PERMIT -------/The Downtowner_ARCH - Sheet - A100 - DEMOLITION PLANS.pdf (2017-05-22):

B

5.B

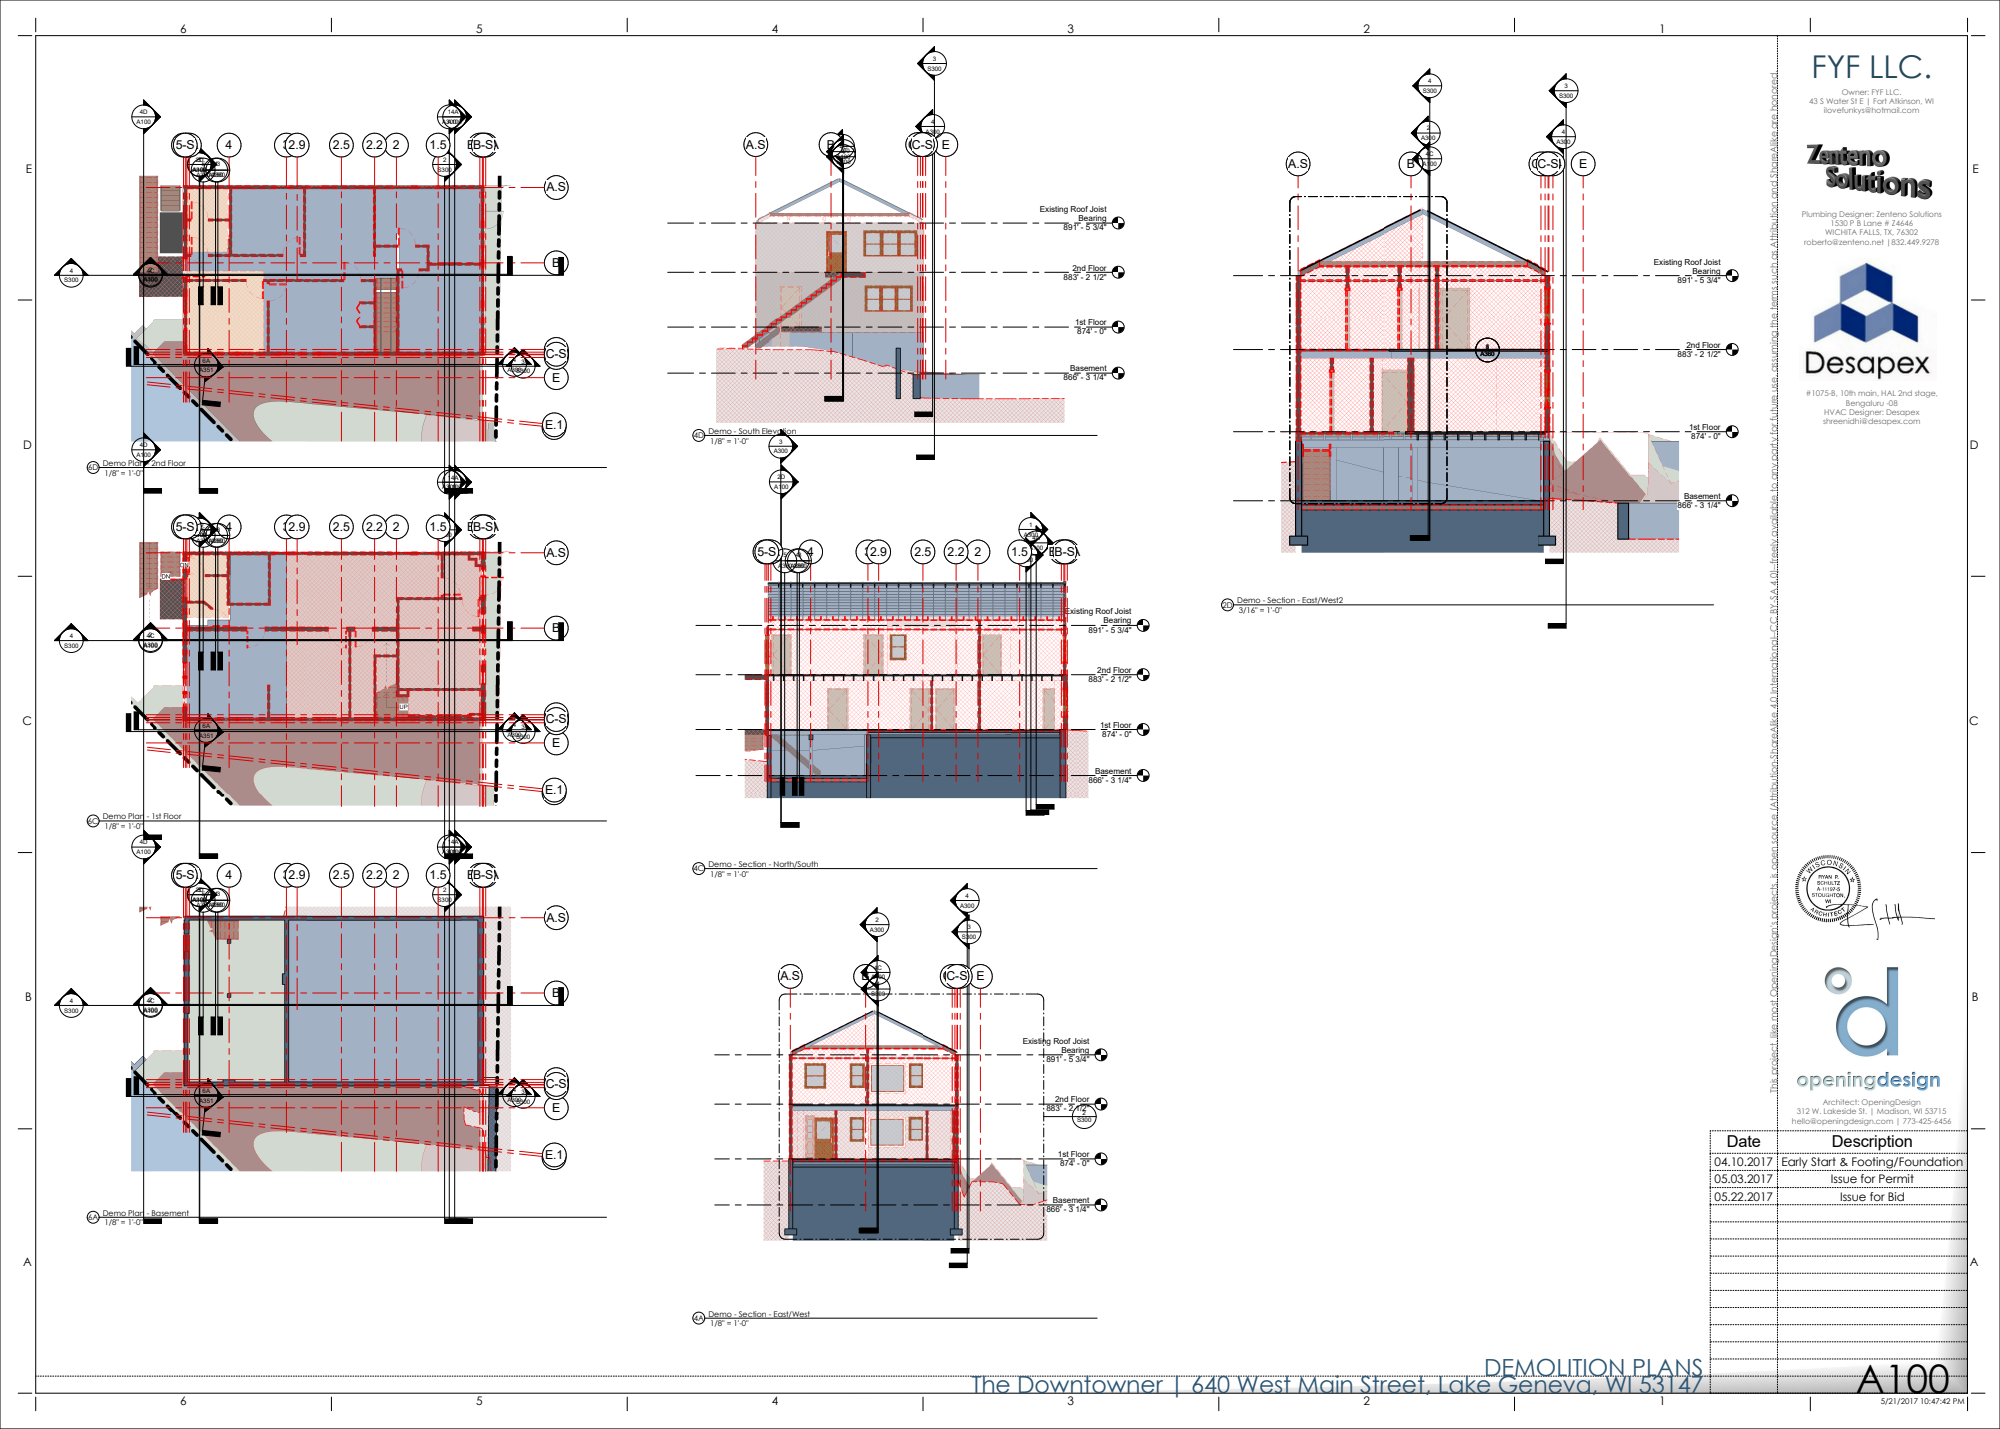
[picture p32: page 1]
1st Floor 874' - 0"; 2nd Floor 883' - 2 1/2"; Basement 866' - 3 1/4"; Bearing 891' - 5 3/4"; Architect: OpeningDesign; BCDE; ABCDE; FYF LLC.; DEMOLITION PLANS; Demo - Section - North/South; Demo - Section - East/West; Demo - Section - East/West2; Demo - South Elevation; Date; Description

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

Owner: FYF LLC.

43 S Water St E | Fort Atkinson, WI
ilovefunkys@hotmail.com

Existing Roof Joist

Plumbing Designer: Zenteno Solutions

1530 P B Lane # Z4646
WICHITA FALLS, TX, 76302
roberto@zenteno.net |832.449.9278

#1075-B, 10th main, HAL 2nd stage,

Bengaluru -08
HVAC Designer: Desapex
shreenidhi@desapex.com

1/8" = 1'-0" 6D Demo Plan - 2nd Floor

1/8" = 1'-0" 6C Demo Plan - 1st Floor

312 W. Lakeside St. | Madison, WI 53715
hello@openingdesign.com | 773-425-6456

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

1/8" = 1'-0" 6A Demo Plan - Basement

The Downtowner | 640 West Main Street, Lake Geneva, WI 53147

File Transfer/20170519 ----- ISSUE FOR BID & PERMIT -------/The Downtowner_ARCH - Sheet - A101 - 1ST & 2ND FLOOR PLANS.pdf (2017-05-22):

B

C.3 E

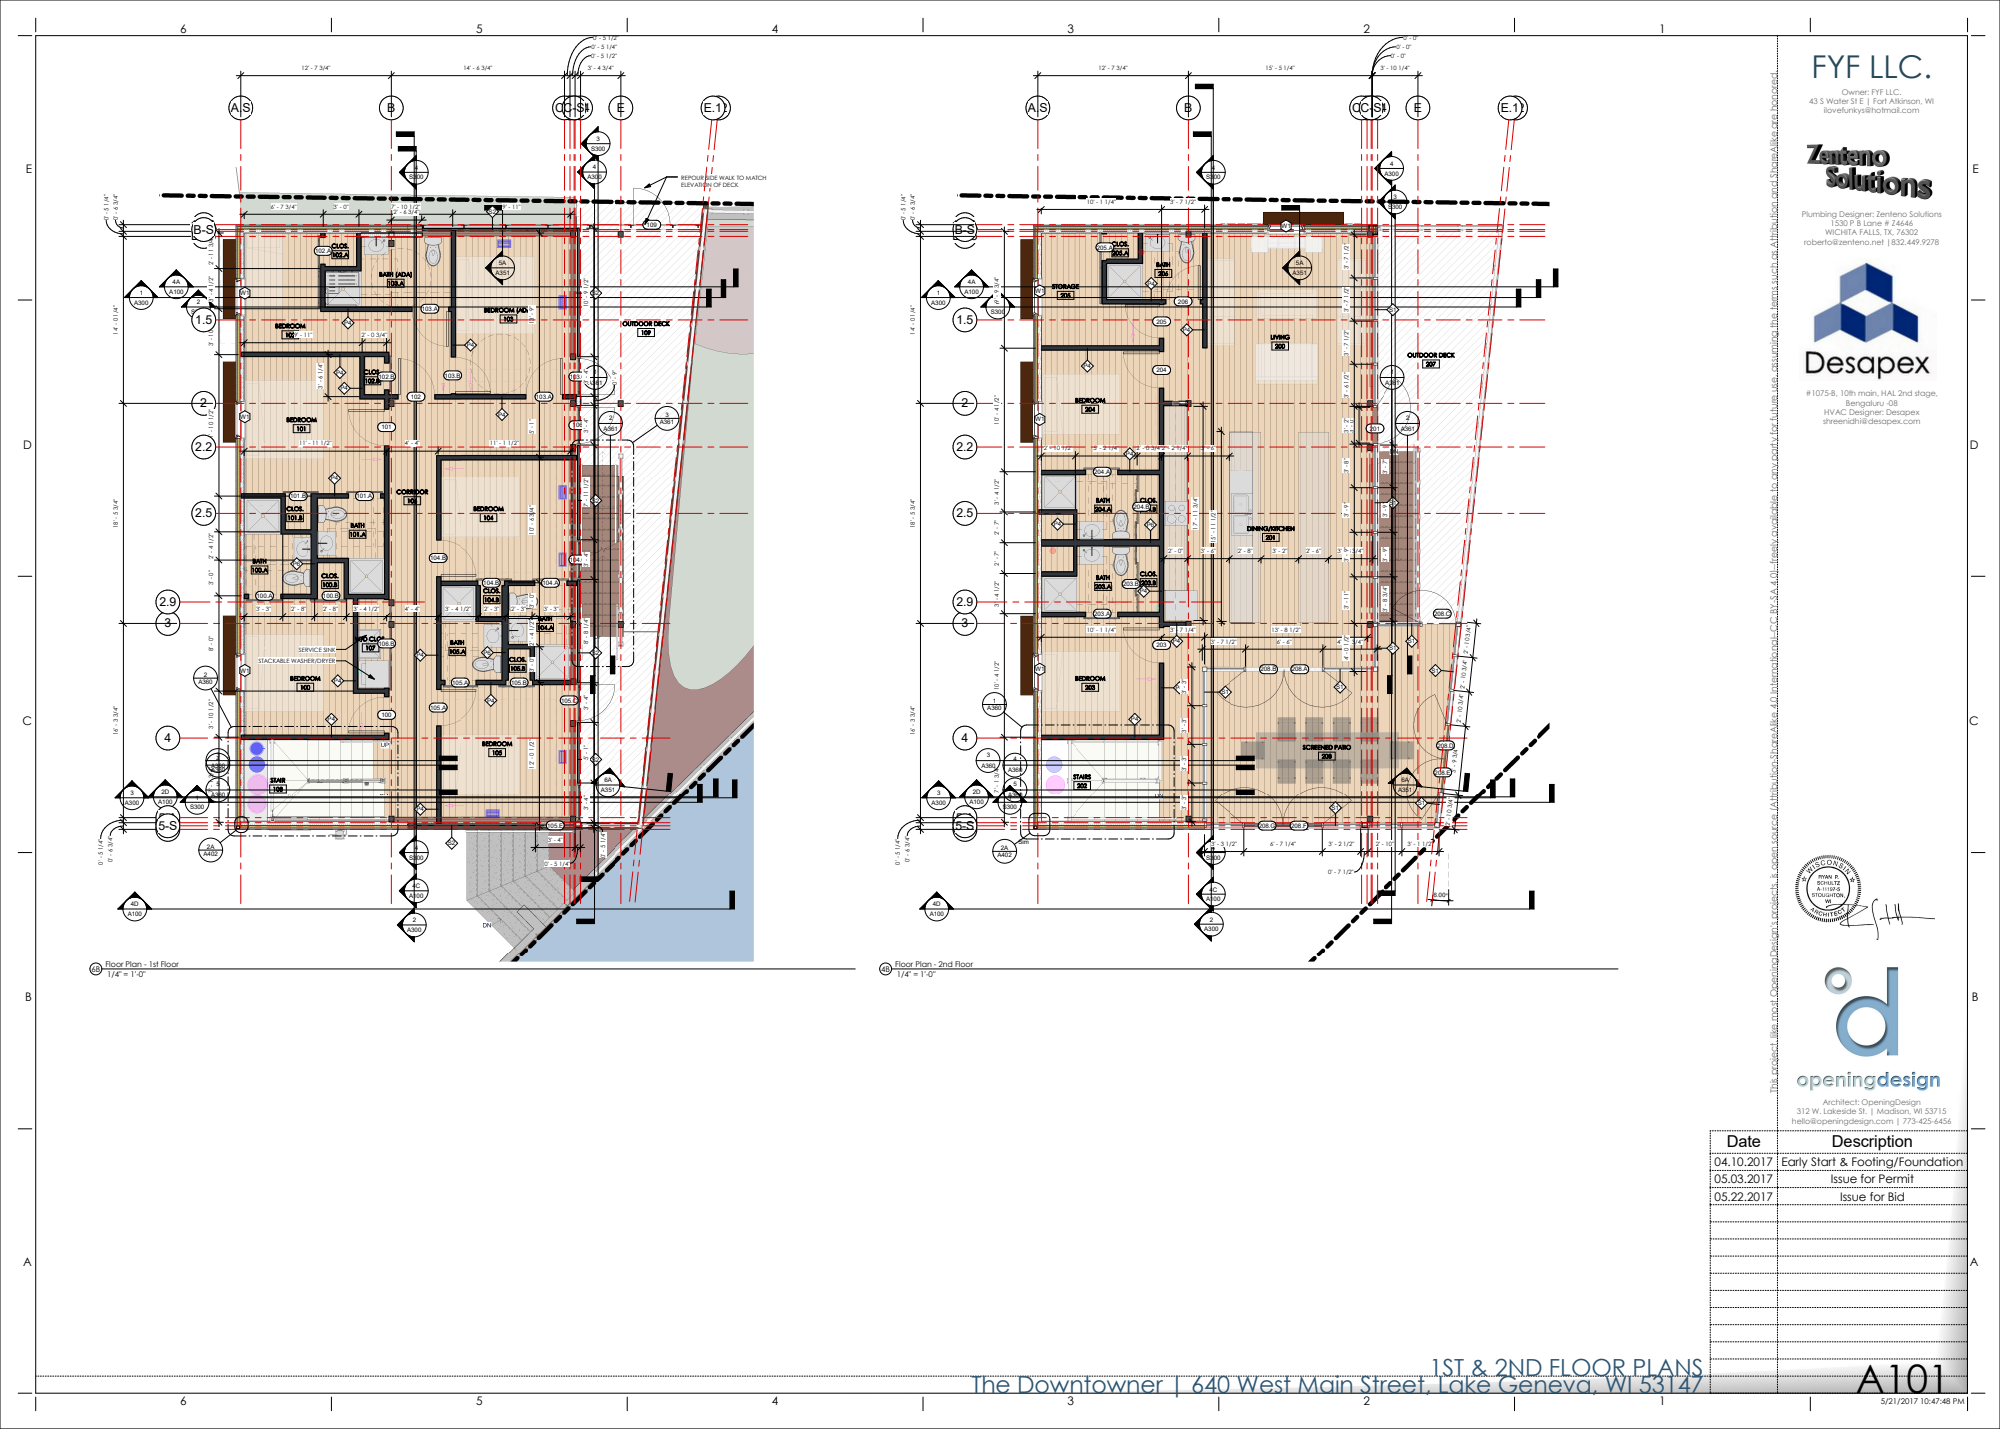
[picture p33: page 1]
BEDROOM; BATH; W/D CLOS.; BATH (ADA); BEDROOM (ADA); CLOS.; CORRIDOR; STAIR; OUTDOOR DECK; SERVICE SINK; STORAGE; STAIRS; DINING/KITCHEN; LIVING; SCREENED PATIO; Sim; Architect: OpeningDesign; FYF LLC.; 1ST & 2ND FLOOR PLANS; Floor Plan - 2nd Floor; Date; Description

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

Owner: FYF LLC.

43 S Water St E | Fort Atkinson, WI
ilovefunkys@hotmail.com

REPOUR SIDE WALK TO MATCH
ELEVATION OF DECK

Plumbing Designer: Zenteno Solutions

1530 P B Lane # Z4646
WICHITA FALLS, TX, 76302
roberto@zenteno.net |832.449.9278

#1075-B, 10th main, HAL 2nd stage,

Bengaluru -08
HVAC Designer: Desapex
shreenidhi@desapex.com

STACKABLE WASHER/DRYER

1/4" = 1'-0" 6B Floor Plan - 1st Floor

312 W. Lakeside St. | Madison, WI 53715
hello@openingdesign.com | 773-425-6456

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

The Downtowner | 640 West Main Street, Lake Geneva, WI 53147

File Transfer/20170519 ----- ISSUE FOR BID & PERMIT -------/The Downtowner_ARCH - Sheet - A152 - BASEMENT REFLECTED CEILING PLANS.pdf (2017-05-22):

B

C.3 E

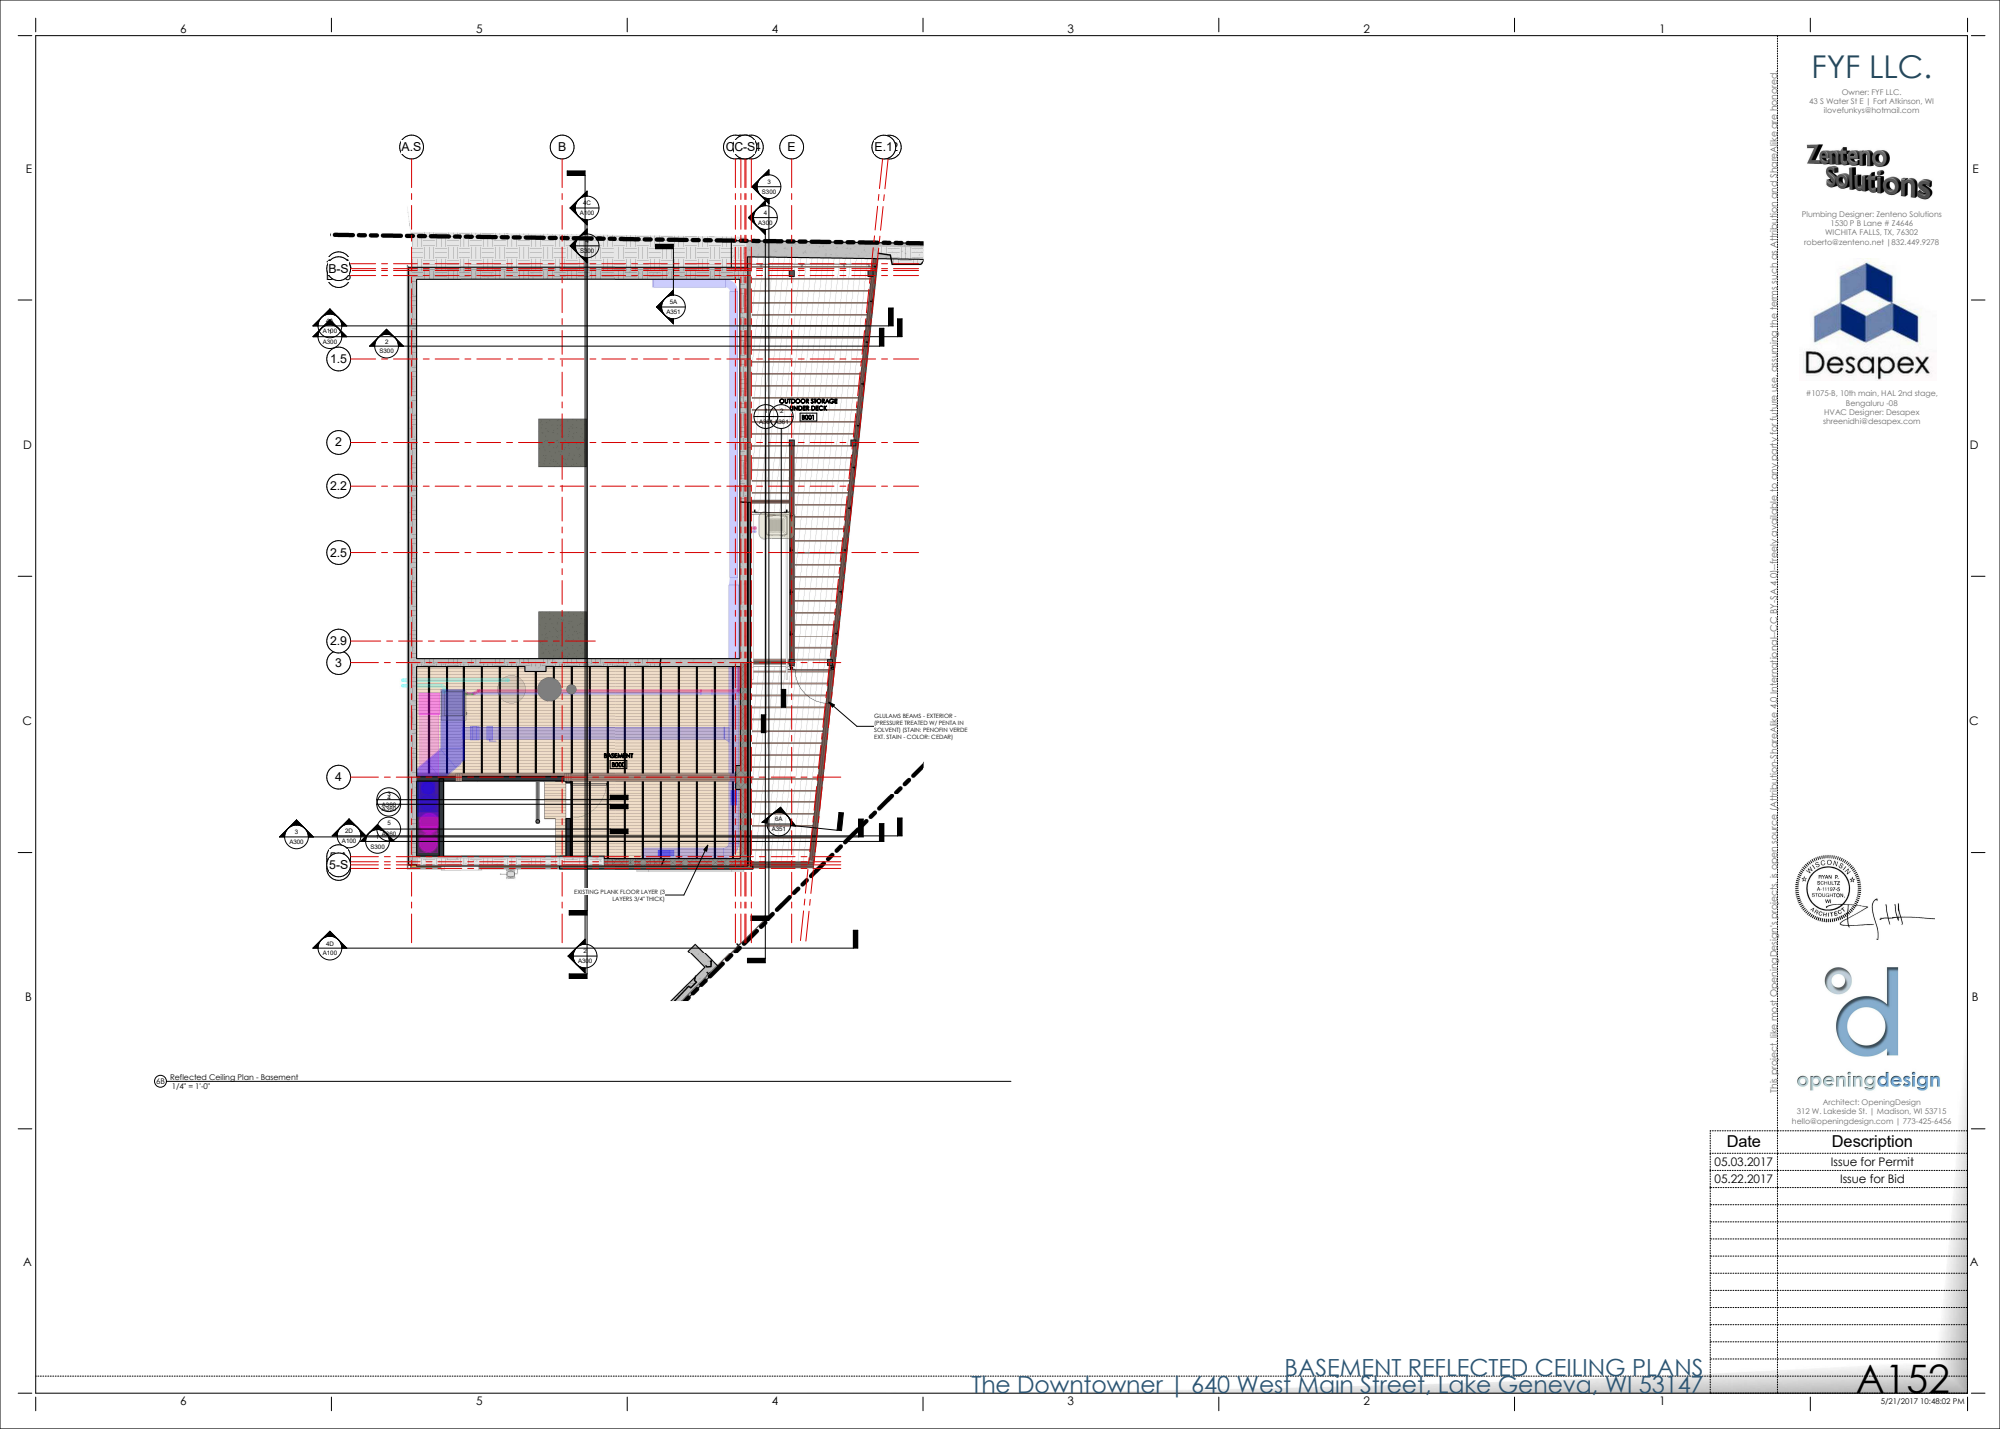
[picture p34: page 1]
BASEMENT; OUTDOOR STORAGE UNDER DECK; LAYERS 3/4" THICK); Architect: OpeningDesign; FYF LLC.; Date; Description

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

Owner: FYF LLC.

43 S Water St E | Fort Atkinson, WI
ilovefunkys@hotmail.com

Plumbing Designer: Zenteno Solutions

1530 P B Lane # Z4646
WICHITA FALLS, TX, 76302
roberto@zenteno.net |832.449.9278

#1075-B, 10th main, HAL 2nd stage,

Bengaluru -08
HVAC Designer: Desapex
shreenidhi@desapex.com

GLULAMS BEAMS - EXTERIOR -
(PRESSURE TREATED W/ PENTA IN
SOLVENT) (STAIN: PENOFIN VERDE
EXT. STAIN - COLOR: CEDAR)

EXISTING PLANK FLOOR LAYER (3

1/4" = 1'-0" 6B Reflected Ceiling Plan - Basement

312 W. Lakeside St. | Madison, WI 53715
hello@openingdesign.com | 773-425-6456

05.03.2017 Issue for Permit
05.22.2017 Issue for Bid

BASEMENT REFLECTED CEILING PLANS The Downtowner | 640 West Main Street, Lake Geneva, WI 53147

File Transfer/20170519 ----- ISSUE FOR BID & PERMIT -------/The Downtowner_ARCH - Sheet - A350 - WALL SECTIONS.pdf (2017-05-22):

B
5.B

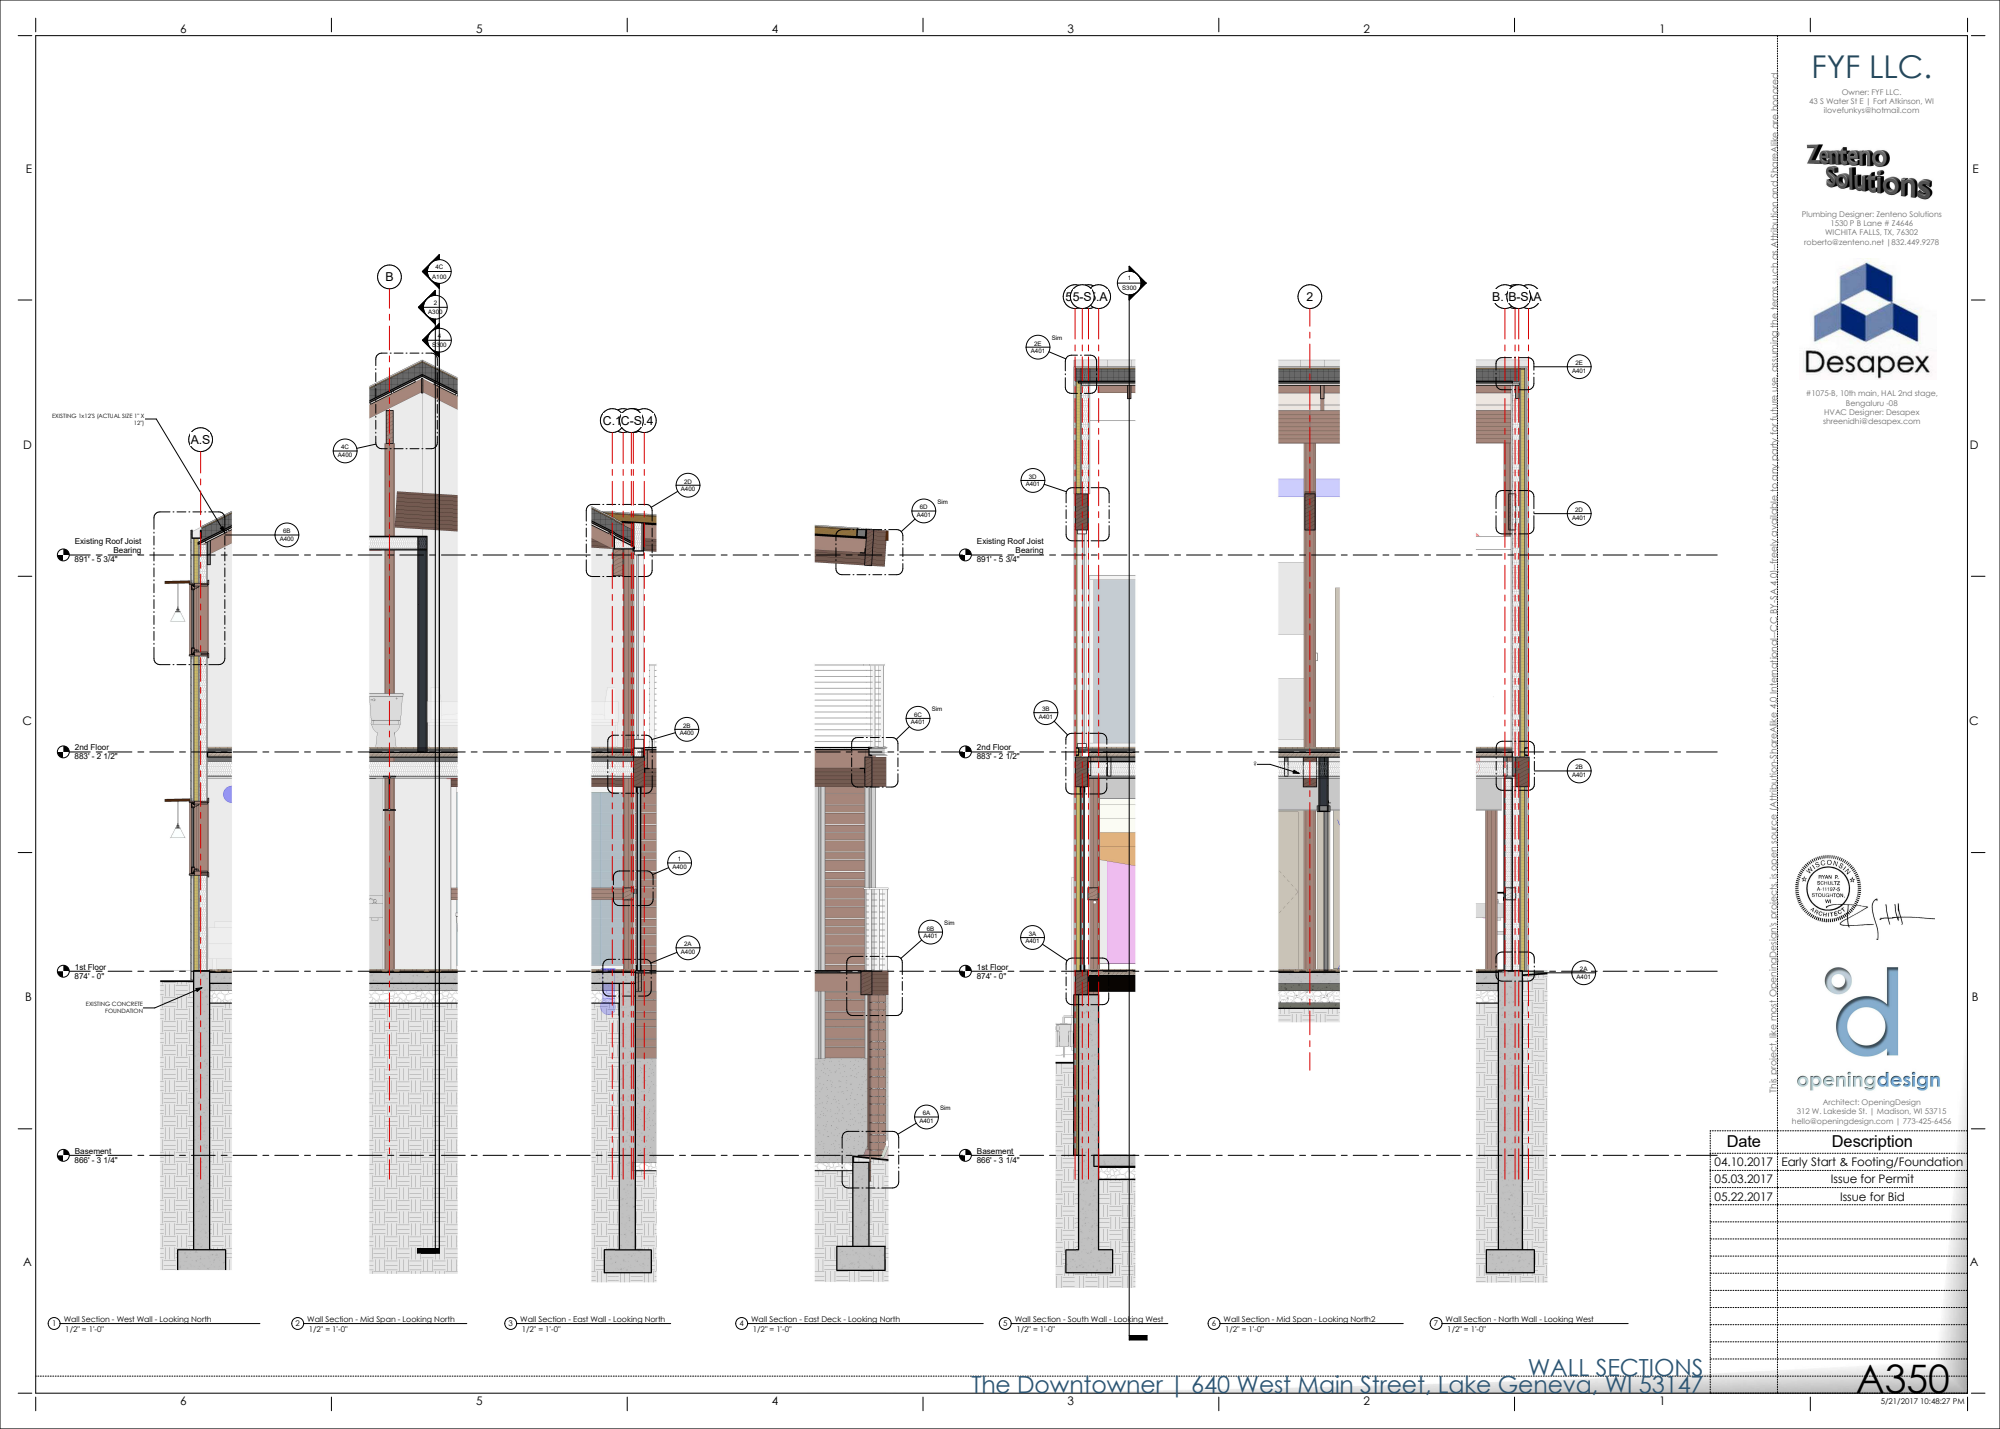
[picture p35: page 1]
1st Floor 874' - 0"; 2nd Floor 883' - 2 1/2"; Basement 866' - 3 1/4"; Bearing 891' - 5 3/4"; EXISTING CONCRETE FOUNDATION; Sim; Architect: OpeningDesign; FYF LLC.; Ali; ely; ila; ble; 1/2" = 1'-0" 1 Wall Section - West Wall - Looking North; 1/2" = 1'-0" 2 Wall Section - Mid Span - Looking North; 1/2" = 1'-0" 3 Wall Section - East Wall - Looking North; 1/2" = 1'-0" 4 Wall Section - East Deck - Looking North; 1/2" = 1'-0" 5 Wall Section - South Wall - Looking West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

Owner: FYF LLC.

43 S Water St E | Fort Atkinson, WI
ilovefunkys@hotmail.com

Plumbing Designer: Zenteno Solutions

1530 P B Lane # Z4646
WICHITA FALLS, TX, 76302
roberto@zenteno.net |832.449.9278

#1075-B, 10th main, HAL 2nd stage,

Bengaluru -08
HVAC Designer: Desapex
shreenidhi@desapex.com

EXISTING 1x12'S (ACTUAL SIZE 1" X

Existing Roof Joist

312 W. Lakeside St. | Madison, WI 53715
hello@openingdesign.com | 773-425-6456

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

WALL SECTIONS The Downtowner | 640 West Main Street, Lake Geneva, WI 53147

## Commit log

2016-09-19 Owner review of floor plan options
    [Cadastral Map.dwg, Cadastral Map2.dwg, Streets & buildings.dwg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]
2016-09-28 pre-review of Conditional Use and Site Approval Application
    [Topo.dwg, Topo_REDUCED.dwg]
2016-10-01 20160930 - Final Printing for City Review
2016-10-25 product research
    [Siding - Prices.ods]
2016-10-25 Materials Boards for City Council Meeting
2016-11-02 20161102 - Drawings - Plan Commission - Review of Materials and Fence
    [Fee Breakdown.ods]
2017-03-27 Add files via upload
    Hi, Ryan pls update the highlighted items in the sheet or provide us the technical data sheet ( cut sheet) of envelope items.
    [Building envelop factors.xlsx]
2017-03-30 HVAC checklist as csv
    [HVAC Checklist for Permit Submittal.csv]
2017-03-30 fix formatting
    [HVAC Checklist for Permit Submittal.csv]
2017-03-30 tab deliminator
    [HVAC Checklist for Permit Submittal.csv]
2017-03-30 quote text cells
    [HVAC Checklist for Permit Submittal.csv]
2017-03-30 Plumbing Checklist for Permit Submittal.csv
    [Plumbing Checklist for Permit Submittal.csv]
2017-04-28 Plumbing-Upload
    Sanitary and Vent systems is complete. Started on the Water
    distribution. Located the Water Heater.
2017-05-03 Plumbing - Water Calculation Worksheet
    Plumbing - Water Calculation Worksheet Excel File.
    [pl-P_water_calc_worksheet-date-job12.xlsx]
2017-05-03 Permit set HVAC
    [Heal loss calculation_The Downtowner.xlsx]
2017-05-04 Permit Set
    [Sheet List.csv]
2017-05-22 ----- Issue for Bid & Permit ------------
    [Sheet List.csv]
2017-05-24 Framing & Columns Schedules.xls
    [Framing & Columns Schedules.xls]
2017-05-30 different format
    [Framing & Columns Schedules.xlsx]
2017-06-19 refined glulam quote
    [Structural Column Schedule.xls, Structural Framing Schedule.xls]
2017-07-13 Path Filename Extension Status Lines added Lines removed Last Modified Size Transfer\20170626 - example files for bracket fabrication\BRACKET ASSY 1.PDF BRACKET ASSY 1.PDF .PDF Unknown Transfer\20170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
    [Flat pattern - ITEM#1.DXF, Flat pattern - ITEM#2.DXF, Flat pattern - ITEM#3.DXF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]
2017-07-27 20170713 - Details printed before site visit
2017-07-27 glulam order
    [All Members.xls, Structural Column Schedule.xls, Structural Framing Schedule.xls]
2017-07-27 20170726 - to Metal Fabricator - connection shop drawings\Glulam Connections.zip
    [(C-2-2-1ST) - SECTION LOOKING NORTH (4 COPIES).dxf, (C-2-2-2ND) - Plate 1 (2 COPIES).dxf, (C-2ND) - SECTION LOOKING EAST (4 COPIES).dxf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]
2017-07-27 Glulam Connectors
2017-09-26 marketing materials for VHBO
2017-10-30 Transfer\20171011 - to GC - Lateral Bracket Clarification
2018-02-05 signage for owner review
    [51h-51hbc-double-box-rail-bracket_techdrawing.dxf]
